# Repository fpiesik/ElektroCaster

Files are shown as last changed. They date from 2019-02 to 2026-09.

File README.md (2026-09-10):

What is the ElektroCaster?

The highest premise of the ElectroCaster is that it's a real guitar which can be used just like that. This project is about to extend the possibilities of expression of a guitar without taking anything away from it. By guitar I don't mean a specific instrument that's hacked somehow, but the idea of a guitar that's to be extended. The ElektroCaster is built from scratch out of aluminum, 3d printed PLA and wood. All the design files are made with open tools such as OpenScad and Kicad. The design is made with the option of parametric changes in mind, like changing the string count, for example.

Here is a list with the most important "guitar-extensions" I've implemented on the hardware side so far are:

    led lit fretboard with 150 individually controllable rbg-leds
    hexaphonic pickip along with a Teensy 4 based 6 channel dsp-unit
    actuator called Kickup that consists of 6 solenoid hitting the strings
    actuator called MultEbow that works like a polyphonic e-Bow (endless sustain)
    fretboard is "touch sensitive" in a way that it recognises which string was pressed at what position
    10 faders, 7 potis, 8 rotary encoder(&switches), 5 buttons, 7 toggle switches, 3 rotary switches (12steps), an analog joystick
    128*64 oled display

## Documentation quick reference

This repository contains three cooperating firmware targets. The tables below summarize the currently documented board roles, serial links, and hardware/protocol references without changing firmware behavior.

### Board roles

| Board firmware | Target noted in docs | Main role | Documentation |
| --- | --- | --- | --- |
| `software/firmwareHid` | Teensy 3.5 | Body controls, encoder/analog/digital input scanning, and local OLED rendering. | `docs/architecture.md`, `docs/protocols.md`, `docs/pinout.md` |
| `software/firmwareCtl` | Teensy 4.1 | Main controller for system state, LED fretboard, fretboard sensing, Kickup, MulEBow control, sequencer/MIDI/SD coordination, and board-to-board routing. | `docs/architecture.md`, `docs/protocols.md`, `docs/realtime.md` |
| `software/firmwareAudio` | Teensy 4.1 | Hexaphonic audio processing, pitch/amplitude analysis, per-string DSP, and actuator audio/control outputs. | `docs/architecture.md`, `docs/protocols.md`, `docs/realtime.md` |

### Serial protocol map

| Link | Baud | Purpose | Details |
| --- | ---: | --- | --- |
| HID <-> CTL | 115200 | Body-control events from HID to CTL and AsciiMassage display commands from CTL to HID. | `docs/protocols.md` |
| CTL <-> Audio | 250000 | Raw byte audio-control commands from CTL to Audio and pitch/amplitude status from Audio to CTL. | `docs/protocols.md` |

### Hardware and timing notes

| Topic | Documentation file | Notes |
| --- | --- | --- |
| Pin assignments | `docs/pinout.md` | Documents firmware-inferred pins only; hardware connector names remain open unless present in source. |
| Realtime intervals | `docs/realtime.md` | Documents LED, fretboard debounce, Kickup, display, clock, HID, and audio intervals. |
| Testing guidance | `docs/testing.md` | Lists safe checks and hardware validation areas. |

### User manual

The German, code-derived operating guide is available at [`docs/bedienungsanleitung.md`](docs/bedienungsanleitung.md). It distinguishes implemented behavior from hardware details that cannot be confirmed from the repository.

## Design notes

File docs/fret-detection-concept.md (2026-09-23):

# Konzept für eine robustere Bunderkennung

## Ausgangslage

Im vollständigen Sensormodus scannt `firmwareCtl` nacheinander alle Bundkontakte
und liest dabei für jede Saite den zugehörigen Eingang. Aus allen aktiven
Kontakten wird derzeit der höchste Bund als `strPrs` gewählt. Erst wenn derselbe
Wert `strBncs` Scans lang anliegt und seit dem letzten ausgegebenen Ereignis
mindestens `fretMaskT` Millisekunden vergangen sind, wird die Änderung
weitergegeben.

Ein normal gegriffener Ton oberhalb des ersten Bundes kann mechanisch zwei
benachbarte Kontakte erzeugen:

- den tatsächlich gegriffenen Bund `F`, und
- den darunterliegenden Bund `F - 1`.

Beim Greifen und Loslassen entstehen diese Kontakte jedoch nicht gleichzeitig.
Die Zwischenzustände `nur F`, `nur F - 1` und `kein Kontakt` können deshalb als
scheinbar gültige Zustände lange genug anliegen, um trotz Debounce und Maske ein
falsches Ereignis auszulösen.

## Bewertung der Zwei-Kontakt-Idee

Zwei **benachbarte** Kontakte sind ein wesentlich stärkeres Plausibilitätssignal
als ein einzelner Kontakt. Die Idee kann daher insbesondere beim Umgreifen
Fehlinterpretationen des tieferen Bundes unterdrücken. Eine globale Regel
„gedrückt nur bei mindestens zwei Kontakten“ ist aber nicht ausreichend:

1. **Bund 1 ist konstruktiv ein Sonderfall.** Dort steht kein tieferer
   Bundkontakt zur Bestätigung zur Verfügung. Ein striktes Zwei-Kontakt-Kriterium
   würde Bund 1 unspielbar machen.
2. **Ein einzelner Kontakt am höheren Bund ist nicht zwingend falsch.** Je nach
   Fingerposition, Saitenlage, Verschmutzung oder Kontaktwiderstand kann der
   zweite Kontakt zeitweise fehlen. Eine harte Regel würde dann gültige Griffe
   übersehen und sich langsamer anfühlen.
3. **Beliebige zwei Kontakte reichen nicht.** Nur das Paar `(F - 1, F)` bestätigt
   `F`. Zwei nicht benachbarte Kontakte können durch mehrere Finger, Nebenschlüsse
   oder Scanartefakte entstehen.
4. **Beim Loslassen hilft das Kriterium allein nicht.** Das bestätigte Paar zerfällt
   zwangsläufig zuerst zu einem Einzelkontakt. Würde dieser sofort als anderer
   Bund behandelt, bleibt das bisherige Fehltracking erhalten; würde er sofort
   als „losgelassen“ behandelt, entstehen vorzeitige Note-Offs.
5. **Die aktuelle Information wird bereits erfasst, aber verworfen.** Der Scanner
   hält die gesamte Matrix in `frtState`; `updateFretDebounce()` reduziert sie
   anschließend auf den höchsten Kontakt und eine Kontaktanzahl. Für ein
   Nachbarschaftskriterium muss deshalb kein Pin oder Scanablauf geändert werden.

**Empfehlung:** Das benachbarte Kontaktpaar als schnelle Bestätigung verwenden,
aber nicht als absolute Voraussetzung. Es sollte Teil eines zustandsbehafteten,
asymmetrischen Filters sein: bestätigte Paare dürfen schneller übernommen
werden; Einzelkontakte werden als Übergang behandelt und erst nach einer kurzen,
gemessenen Frist als Fallback akzeptiert.

## Vorgeschlagene Zustandsmaschine pro Saite

Die Zustandsmaschine arbeitet nach einem vollständigen Matrixscan und getrennt
von MIDI-, Audio-, Kickup- und Sequenceraktionen. Sie liefert weiterhin nur den
bisherigen logischen Wert `0..nFrets`; nachgelagerte Ereignisse und Protokolle
bleiben unverändert.

### Beobachtung aus einem Scan

Für jede Saite werden abgeleitet:

- `highest`: höchster aktiver Kontakt oder `0`,
- `hasPair`: `highest > 1` und die Kontakte `highest` sowie `highest - 1` sind
  aktiv,
- `contactCount`: Zahl aktiver Kontakte,
- optional eine Bitmaske aller Kontakte für Diagnose und Tests.

Die vorhandene Abbildung ist zu beachten: Matrixindex `f` wird aktuell als
Bundnummer `f + 1` ausgegeben. Das Paar für den ausgegebenen Bund `F` liegt somit
an den Matrixindizes `F - 1` und `F - 2`.

### Zustände

| Zustand | Bedeutung |
| --- | --- |
| `RELEASED` | Kein bestätigter Griff. |
| `CANDIDATE(F)` | Ein noch nicht bestätigter Einzelkontakt oder ein instabiler Übergang. |
| `PRESSED(F)` | Stabil bestätigter, nach außen gemeldeter Griff. |
| `RELEASING(F)` | Das bestätigte Paar ist zerfallen; kurze Haltephase gegen falschen Bundwechsel beziehungsweise vorzeitiges Loslassen. |

### Übergänge

1. **Schnelles Greifen oberhalb Bund 1:** In `RELEASED` oder `CANDIDATE`
   bestätigt das benachbarte Paar `(F - 1, F)` den Bund `F` nach einer kleinen
   Anzahl aufeinanderfolgender identischer Scans. Diese Schwelle sollte deutlich
   kleiner als der heutige allgemeine Debounce sein, muss aber am Instrument
   gemessen werden.
2. **Bund 1:** Ein Einzelkontakt an Bund 1 wird über einen eigenen, zeitbasierten
   oder scanbasierten Debounce bestätigt.
3. **Fallback für unvollständige Paare:** Ein stabiler Einzelkontakt oberhalb
   Bund 1 darf nach einer längeren Frist bestätigt werden. Dadurch bleibt das
   System bei schwachem oder fehlendem Zweitkontakt spielbar.
4. **Umgreifen:** Liegt in `PRESSED(oldF)` ein vollständiges neues Paar für
   `newF` vor, kann direkt auf `newF` gewechselt werden. Ein einzelner Kontakt
   neben `oldF` ändert die ausgegebene Note zunächst nicht, sondern startet oder
   erneuert nur `CANDIDATE(newF)`.
5. **Loslassen:** Zerfällt das Paar, bleibt `oldF` zunächst in `RELEASING(oldF)`
   logisch aktiv. Erst eine kurze stabile Nullphase erzeugt Release. Entsteht
   währenddessen ein bestätigtes neues Paar, erfolgt ein direkter Bundwechsel
   ohne zwischenzeitliches Release.
6. **Mehrdeutige Matrix:** Bei mehr als zwei Kontakten wird das höchste
   benachbarte Paar als Kandidat gewählt. Existiert kein benachbartes Paar, gilt
   die Beobachtung als unsicher und wird nur über den langsamen Fallback
   übernommen. Ob Mehrfingergriffe auf derselben Saite für Step-Edit weiterhin
   separat benötigt werden, muss vor der Implementierung geprüft werden.

## Warum Zeit statt ausschließlich Scananzahl erwägen

`readFretboard()` läuft im Hauptloop, dessen Frequenz durch andere Aufgaben
schwanken kann. Eine feste Anzahl gleicher Scans entspricht daher nicht zwingend
einer konstanten Latenz. Für musikalisch wahrnehmbare Übergänge sind Zeitgrenzen
in Mikro- oder Millisekunden leichter zu messen und zu begründen. Alternativ muss
die tatsächliche Scanrate unter Worst-Case-Last bestimmt werden, bevor neue
Scan-Schwellen gewählt werden.

Die bestehenden Werte `strBncs = 500` Samples und `fretMaskT = 50 ms` sollten
nicht blind übernommen oder geändert werden. Die Paarbestätigung, der
Einzelkontakt-Fallback und die Release-Haltezeit benötigen getrennte, anhand von
Messdaten festgelegte Parameter. Insbesondere darf die bestehende 50-ms-Maske
einen schnellen, eindeutig bestätigten Bundwechsel nicht unnötig blockieren.

## Implementierung in kleinen Schritten

1. **Nur instrumentieren:** Pro Scan Zeitstempel, Rohkontaktmaske, aktuell
   ausgegebenen Bund und Ereignisgrund in einen begrenzten Debug-Puffer schreiben.
   Keine seriellen Prints im zeitkritischen Scanpfad; den Puffer später gedrosselt
   ausgeben.
2. **Reale Übergänge aufzeichnen:** Je Saite Bund 1, mehrere mittlere und hohe
   Bünde, langsames und schnelles Greifen, Loslassen, Slides und schnelle
   Bundwechsel erfassen. Dabei besonders die Dauer der Einzelkontaktphasen
   bestimmen.
3. **Filter als reine Logik isolieren:** Die Auswertung einer Kontaktmaske in
   einer kleinen zustandsbehafteten Komponente implementieren. Der bestehende
   Hardware-Scan bleibt unverändert. Hostseitige Tests speisen aufgezeichnete
   Maskenfolgen ein.
4. **Schattenbetrieb:** Alten und neuen Filter parallel berechnen, Aktionen aber
   weiterhin nur aus dem alten Filter auslösen. Abweichungen protokollieren.
5. **Gezielter Hardwareversuch:** Erst nach Auswertung der Logs den neuen Filter
   für Ereignisse aktivieren. MIDI, Audio, Kickup und Step-Edit einzeln prüfen.
6. **Parameter abstimmen:** Fast-Path, Fallback und Releasezeit anhand der
   schlechtesten realen Saite/Bund-Kombination wählen, nicht anhand eines
   synthetischen Idealverlaufs.

## Minimale Testmatrix

Für jede Saite und mindestens Bund 1, 2, einen mittleren sowie den höchsten
erfassten Bund:

- einzelnes Greifen und Loslassen, langsam und schnell,
- Wechsel `F -> F + 1`, `F + 1 -> F` und Sprung über mehrere Bünde,
- Slide mit durchgehendem Saitenkontakt,
- sehr kurzer Tap und wiederholte schnelle Taps,
- absichtlich nur ein Bundkontakt,
- Kontaktfolge `F - 1`, dann Paar; beim Loslassen Paar, dann `F - 1`, dann null,
- Kontaktfolge `F`, dann Paar; beim Loslassen Paar, dann `F`, dann null,
- mehr als zwei gleichzeitige Kontakte sowie nicht benachbarte Kontakte,
- mehrere Saiten gleichzeitig,
- Betrieb mit LED-Update, Sequencer und MIDI, um variable Looplast abzudecken.

Zu messen sind mindestens False Note-On, False Note-Off, falsche Bundnummer,
verlorene Griffe sowie Latenz von erstem Kontakt bis zum Ereignis. Als
Abnahmekriterium sollte die neue Logik bei gleicher Testsequenz weniger
Fehlereignisse erzeugen, ohne die gemessene typische Anschlagslatenz zu erhöhen.

## Auswirkungen und Grenzen

- **Betroffenes Board:** ausschließlich `firmwareCtl` (Teensy 4.1).
- **Pins und elektrischer Scan:** Das Konzept benötigt keine Änderung.
- **Serielle Protokolle:** Keine Änderung; nach außen bleibt der logische
  Griffzustand gleich codiert.
- **Realtime-Audio und Audio-Routing:** Keine Änderung.
- **Kickup:** Keine Timingänderung, aber verbesserte Erkennung verändert
  naturgemäß, welches Griffereignis einen Kick auslöst; deshalb sicher testen.
- **Ungewissheit:** Ob wirklich jeder reale Griff ab Bund 2 zuverlässig das
  benachbarte Paar bildet, ist aus dem Code nicht belegbar. Diese Annahme muss mit
  Rohdaten aller Saiten und relevanten Bünde validiert werden.

## Implementierungsstand

Der zustandsbehaftete Filter ist als hardwareunabhängige Logik in
`software/firmwareCtl/FretDetection.h` umgesetzt. Im vollständigen Sensormodus
wertet `firmwareCtl` nach jedem unveränderten Matrixscan die Kontaktmaske aus und
verwendet den höchsten benachbarten Kontakt als schnelle Bestätigung. Bund 1,
einzelne höhere Kontakte und die Nullphase besitzen getrennte Zeitgrenzen. Der
vereinfachte Sensormodus verwendet weiterhin den bisherigen scanbasierten
Debounce und die 50-ms-Ereignismaske.

Die Startwerte betragen 4 ms für ein Paar, 12 ms für Bund 1, 30 ms für den
Einzelkontakt-Fallback und 12 ms für das Loslassen. Diese Werte sind ausdrücklich
vorläufig. Vor dem Einsatz am Instrument müssen sie mit der oben beschriebenen
Testmatrix und aufgezeichneten Rohkontakten validiert und gegebenenfalls
angepasst werden.

Die reine Filterlogik wird hostseitig durch `tests/fret_detection_test.cpp`
geprüft. Der Test deckt Paarbestätigung, zerfallende Paare, Loslassen, Bund 1,
Einzelkontakt-Fallback, direkte Bundwechsel, mehrdeutige Kontaktmasken und den
Überlauf von `millis()` ab.

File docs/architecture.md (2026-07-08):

# ElektroCaster architecture

This document summarizes the firmware architecture as currently inferable from the repository. It is documentation only and does not define new behavior.

## System overview

ElektroCaster is a hardware/firmware electric guitar platform with:

- a 150-pixel LED fretboard,
- touch-sensitive fretboard detection through string/fret contacts,
- Kickup solenoid string actuators,
- a MulEBow electromagnetic sustain actuator,
- hexaphonic pickup/audio processing,
- many body controls,
- an OLED display.

The firmware is split across three microcontrollers.

## Board role summary

| Firmware | Board role | Owns / directly touches | Communicates with | Protected behavior to preserve |
| --- | --- | --- | --- | --- |
| `software/firmwareHid` | Body-control and display companion | Analog controls, digital controls, encoders, resistor-ladder rotary switches, SH1106 128x64 OLED | `firmwareCtl` over `Serial6` at 115200 baud | HID command byte layout, display packet names/payloads, input pin assignments |
| `software/firmwareCtl` | Main coordinator | LED fretboard, fretboard contact scanning, Kickup pins/timing, MIDI, SD song state, display composition, Audio/HID routing | `firmwareHid` over `Serial7` at 115200 baud; `firmwareAudio` over `Serial1` at 250000 baud; USB/hardware MIDI | Fretboard scan/debounce, Kickup pulse timing, serial payload formats, LED pin/mapping |
| `software/firmwareAudio` | Hexaphonic DSP and actuator-audio board | TDM audio I/O, CS42448 codec control, per-string DSP, analysis objects, coil/MulEBow outputs | `firmwareCtl` over `Serial1` at 250000 baud | AudioConnection graph, audio routing, analysis intervals, audio command scaling |

## Microcontroller roles

### `software/firmwareHid`

Likely target: Teensy 3.5.

Responsibilities:

- Read body controls:
  - 22 analog inputs,
  - 19 digital inputs,
  - 8 encoders,
  - 3 analog resistor-ladder rotary switch values.
- Send changed control values to `firmwareCtl` over a serial link.
- Own the OLED display hardware through U8g2.
- Receive display drawing commands from `firmwareCtl` using AsciiMassage packets and render them locally.

Important files:

- `software/firmwareHid/HardwareConfig.h`: HID input counts and pin arrays.
- `software/firmwareHid/firmwareHid.ino`: encoder instances, input scanning loop, display initialization.
- `software/firmwareHid/send.ino`: HID-to-CTL byte protocol.
- `software/firmwareHid/receive.ino`: CTL-to-HID display command receiver.
- `software/firmwareHid/display.ino`: local U8g2 drawing helpers.

### `software/firmwareCtl`

Likely target: Teensy 4.1.

Responsibilities:

- Main system state.
- LED fretboard control through FastLED/WS2812Serial.
- Fretboard contact scanning and debouncing.
- Kickup cueing and solenoid timing.
- MulEBow control messages sent to the audio board.
- Sequencer, scale, string setup, song, and pattern state.
- SD card song loading/saving.
- USB MIDI and hardware MIDI handling.
- Serial coordination with HID and Audio boards.

Important files:

- `software/firmwareCtl/firmwareCtl.ino`: large global state block, setup, main loop, hardware initialization.
- `software/firmwareCtl/04_hid.ino`: fretboard scan/debounce plus HID processing and musical actions.
- `software/firmwareCtl/ProtocolAudio.h` and `ProtocolHid.h`: shared byte constants for Audio and HID serial protocols.
- `software/firmwareCtl/2audio.ino`: CTL-to-Audio command senders.
- `software/firmwareCtl/13_serialEvents.ino`: serial receivers from Audio and HID.
- `software/firmwareCtl/01_actuators.ino`: Kickup cueing and pulse handling.
- `software/firmwareCtl/02_clock.ino`: internal clock, MIDI clock, sync points, pattern scheduling.
- `software/firmwareCtl/03_display.ino`: display update and drawing command senders.
- `software/firmwareCtl/05_ledfrets.ino`: LED fretboard update logic.
- `software/firmwareCtl/14_song.ino`: binary SD song save/load format.

### `software/firmwareAudio`

Likely target: Teensy 4.1.

Responsibilities:

- Hexaphonic audio input and processing using the Teensy Audio Library.
- TDM audio input and output through `AudioInputTDM`, `AudioOutputTDM`, and `AudioControlCS42448`.
- Per-string input gain, envelope, filter, ring/amplitude modulation, pitch analysis, RMS analysis.
- MulEBow/coil oscillator outputs.
- Receive control commands from `firmwareCtl`.
- Send pitch and amplitude analysis data back to `firmwareCtl`.

Important files:

- `software/firmwareAudio/ProtocolAudio.h`: shared byte constants for the CTL/Audio serial protocol.
- `software/firmwareAudio/firmwareAudio.ino`: global audio objects, state, static output summing connections.
- `software/firmwareAudio/0Setup.ino`: audio hardware setup and per-string `AudioConnection` construction.
- `software/firmwareAudio/yLoop.ino`: serial command parser, analysis loop, MulEBow state handling.
- `software/firmwareAudio/2ctl.ino`: Audio-to-CTL status senders.
- `software/firmwareAudio/envelopes.ino`, `filter.ino`, `fx.ino`, `lfos.ino`: DSP parameter helpers.

## Data flow

```text
Body controls + OLED hardware
        |
        | firmwareHid Serial6 @ 115200 baud
        v
firmwareCtl Serial7 @ 115200 baud
        |
        | firmwareCtl Serial1 @ 250000 baud
        v
firmwareAudio Serial1 @ 250000 baud
```

Additional flows:

- `firmwareCtl` sends display drawing commands to `firmwareHid` using AsciiMassage packets.
- `firmwareHid` sends HID control changes to `firmwareCtl` using compact byte messages.
- `firmwareCtl` sends audio control, string state, envelope, filter, volume, and bow commands to `firmwareAudio` using compact byte messages.
- `firmwareAudio` sends pitch and amplitude estimates back to `firmwareCtl`.
- `firmwareCtl` also handles USB MIDI and hardware MIDI.

## Known technical risks

- Many global variables in `firmwareCtl` and `firmwareAudio` make dependencies implicit.
- Several files mix hardware access, state updates, UI handling, musical logic, and protocol handling.
- Pin assignments and hardware mappings are embedded directly in firmware files.
- Serial protocols use magic byte values and do not appear to have checksums, versioning, or documented recovery behavior.
- Serial packet parsing is non-blocking on the inspected HID and Audio links and uses short packet timeouts, but the byte protocols still lack checksums, sequence numbers, explicit length bytes, or version negotiation.
- `firmwareCtl/04_hid.ino` couples fretboard scanning, debounce, MIDI, Kickup, audio triggering, and sequencer editing.
- `firmwareCtl/02_clock.ino` calls display updates from the internal clock path; timing impacts should be measured before changing it.
- `firmwareAudio/0Setup.ino` builds many audio connections dynamically; audio routing changes are high risk.
- `firmwareCtl/14_song.ino` stores song data as an implicit binary layout without an evident version header.

## Refactor safety guidance

- Documentation-only changes should not touch firmware source files.
- For firmware refactors, start by naming constants and documenting existing behavior before changing control flow.
- Treat pin mappings, serial payloads, audio routing, Fretboard scan timing, Clock timing, and Kickup pulse timing as protected behavior.

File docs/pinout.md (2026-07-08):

# ElektroCaster pinout notes

This document records pin assignments inferable from firmware source. It does not change pin values. Hardware labels and board connector names are open unless explicitly shown in code.

## Board-level pin ownership

| Firmware | Pin / hardware area | Source of truth in firmware | Notes |
| --- | --- | --- | --- |
| `software/firmwareHid` | Body controls, encoders, OLED I2C | `software/firmwareHid/HardwareConfig.h`, `software/firmwareHid/firmwareHid.ino` | OLED constructor uses hardware I2C with `U8X8_PIN_NONE`; exact SDA/SCL board pins are implied by Teensy hardware I2C rather than listed here. |
| `software/firmwareCtl` | LED data, fret contacts, string sense pins, Kickup outputs | `software/firmwareCtl/HardwareConfig.h`, `software/firmwareCtl/firmwareCtl.ino` | LED matrix order is encoded in `led_pixPos`; fret and string scan semantics are timing-sensitive. |
| `software/firmwareAudio` | TDM audio channels and codec/audio objects | `software/firmwareAudio/firmwareAudio.ino`, `software/firmwareAudio/0Setup.ino` | Physical codec connector labels are not documented in source. |

## `software/firmwareHid`

### Encoders

| Encoder | Pins |
| --- | --- |
| `enc0` | `16`, `15` |
| `enc1` | `3`, `2` |
| `enc2` | `6`, `5` |
| `enc3` | `9`, `8` |
| `enc4` | `12`, `11` |
| `enc5` | `26`, `24` |
| `enc6` | `29`, `28` |
| `enc7` | `45`, `44` |

Note: `nEnc` is declared as `8`; eight encoders are instantiated and sent.

### Analog inputs

`aPin[22]`:

| Index | Pin | Notes |
| ---: | --- | --- |
| 0 | `31` | Analog control; exact hardware function open. |
| 1 | `32` | Analog control; exact hardware function open. |
| 2 | `33` | Analog control; exact hardware function open. |
| 3 | `34` | Analog control; exact hardware function open. |
| 4 | `35` | Analog control; exact hardware function open. |
| 5 | `36` | Analog control; exact hardware function open. |
| 6 | `37` | Analog control; exact hardware function open. |
| 7 | `38` | Analog control; exact hardware function open. |
| 8 | `39` | Analog control; exact hardware function open. |
| 9 | `A21` | Analog control; exact hardware function open. |
| 10 | `A22` | Analog control; exact hardware function open. |
| 11 | `14` | Analog control; exact hardware function open. |
| 12 | `A26` | Analog control; exact hardware function open. |
| 13 | `A25` | Analog control; exact hardware function open. |
| 14 | `A11` | Analog control; exact hardware function open. |
| 15 | `A10` | Analog control; exact hardware function open. |
| 16 | `A24` | Analog control; exact hardware function open. |
| 17 | `A23` | Analog control; exact hardware function open. |
| 18 | `A9` | Analog control; exact hardware function open. |
| 19 | `A8` | Rotary switch resistor ladder input. |
| 20 | `A7` | Rotary switch resistor ladder input. |
| 21 | `A6` | Rotary switch resistor ladder input. |

### Digital inputs

`dPin[19]`:

| Index | Pin | Notes |
| ---: | --- | --- |
| 0 | `17` | Digital control; exact hardware function open. |
| 1 | `13` | Digital control; exact hardware function open. |
| 2 | `51` | Digital control; exact hardware function open. |
| 3 | `52` | Digital control; exact hardware function open. |
| 4 | `53` | Digital control; exact hardware function open. |
| 5 | `42` | Digital control; exact hardware function open. |
| 6 | `41` | Digital control; exact hardware function open. |
| 7 | `40` | Digital control; exact hardware function open. |
| 8 | `56` | Digital control; exact hardware function open. |
| 9 | `57` | Digital control; exact hardware function open. |
| 10 | `43` | Digital control; exact hardware function open. |
| 11 | `54` | Digital control; exact hardware function open. |
| 12 | `55` | Digital control; exact hardware function open. |
| 13 | `4` | Digital control; exact hardware function open. |
| 14 | `7` | Digital control; exact hardware function open. |
| 15 | `10` | Digital control; exact hardware function open. |
| 16 | `25` | Digital control; exact hardware function open. |
| 17 | `27` | Digital control; exact hardware function open. |
| 18 | `30` | Digital control; exact hardware function open. |

## `software/firmwareCtl`

### Serial ports

| Port | Baud | Inferred use |
| --- | ---: | --- |
| `Serial` | 115200 | Debug USB serial. |
| `Serial1` | 250000 | Audio board link. |
| `Serial7` | 115200 | HID board link. |
| `Serial8` | MIDI library instance | Hardware MIDI. |

### LED fretboard

| Symbol | Value | Notes |
| --- | --- | --- |
| `LED_PIN` | `14` | WS2812Serial/FastLED data pin. |
| `NUMPIXELS` | `150` | Total LED count. |
| `nLedFrets` | `25` | LED fret positions per string. |

The physical LED matrix mapping is encoded in `led_pixPos[6][25]`. Exact physical orientation should be verified against hardware.

### Fretboard contact sensing

| Symbol | Values | Notes |
| --- | --- | --- |
| `nFrets` | `21` | Fret contact count used for scanning. |
| `frtPins` | `{13,33,2,3,4,5,6,7,8,9,10,11,12,24,25,26,27,30,31,32,17,16}` | Contains 22 entries while `nFrets` is 21; open issue to verify. |
| `strPins` | `{18,19,20,21,22,23}` | Six string sense inputs. |

Open: `strSnsPins` is also declared as `{2,3,4,5,6,7}` in the string definitions section, but the fretboard scanner uses `strPins`.

### Kickup

| String index | Pin |
| ---: | ---: |
| 0 | `41` |
| 1 | `40` |
| 2 | `39` |
| 3 | `38` |
| 4 | `37` |
| 5 | `36` |

## `software/firmwareAudio`

### Serial ports

| Port | Baud | Inferred use |
| --- | ---: | --- |
| `Serial` | 115200 | Debug USB serial. |
| `Serial1` | 250000 | CTL board link. |

### TDM audio channel mappings

| Array | Values | Notes |
| --- | --- | --- |
| `strAIn[6]` | `{10,8,6,4,2,0}` | Audio input channels of the strings. |
| `strAOut[6]` | `{10,8,6,4,2,0}` | Output channels of the string coils. |

Open: Physical codec channel labels and connector wiring are not documented in source.

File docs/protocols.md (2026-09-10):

# ElektroCaster serial protocols

This document records currently observed serial protocols. It is based on repository source code only. Where semantics are unclear, they are marked as open.

## Serial links and baud rates

| Link | Sender-side port | Receiver-side port | Baud | Notes |
| --- | --- | --- | --- | --- |
| HID -> CTL | `firmwareHid` `Serial6` | `firmwareCtl` `Serial7` | 115200 | HID controls to main controller. |
| CTL -> HID display | `firmwareCtl` `Serial7` | `firmwareHid` `Serial6` | 115200 | AsciiMassage display drawing commands. Same physical link is likely bidirectional. |
| CTL -> Audio | `firmwareCtl` `Serial1` | `firmwareAudio` `Serial1` | 250000 | Raw byte command protocol. |
| Audio -> CTL | `firmwareAudio` `Serial1` | `firmwareCtl` `Serial1` | 250000 | Raw byte status protocol. Same physical link is likely bidirectional. |

Open question: physical wiring and electrical directionality are not documented in the repository.

## Protocol byte-space summary

| Direction | Transport | Framing style | Command / packet namespace | Payload style | Receiver notes |
| --- | --- | --- | --- | --- | --- |
| HID -> CTL | Raw bytes on HID/CTL serial link | Command/index byte followed by value byte; HID also sends `255` after `sendAllNew()` | Command bytes are offset from HID indexes using `+ 201`; CTL subtracts `201` before dispatch | One value byte per recognized input event | CTL uses non-blocking packet assembly with a short timeout; no checksum or versioning identified. |
| CTL -> HID display | AsciiMassage on HID/CTL serial link | Named AsciiMassage packets | Text packet names such as `str`, `int`, `frm`, `buf` | Packet-specific byte/int/long/string fields | HID delegates parsing/framing to AsciiMassage and executes U8g2 drawing calls. |
| CTL -> Audio | Raw bytes on CTL/Audio serial link | Command byte `200..255`, then command-specific payload | Shared audio command constants; Audio decodes `command - 200` | One or more bytes; most scaled values are intended to stay `<= 199` | Audio uses non-blocking packet assembly with a short timeout; no checksum or length byte identified. |
| Audio -> CTL | Raw bytes on CTL/Audio serial link | Status command byte, then status-specific payload | Audio status constants reuse some numeric IDs from the opposite direction | Pitch/amplitude/status bytes | CTL decodes by direction, so numeric reuse is only safe because links are directional at parser level. |

## HID -> CTL protocol

Implemented in:

- `software/firmwareHid/ProtocolHid.h`
- `software/firmwareHid/send.ino`
- `software/firmwareCtl/ProtocolHid.h`
- `software/firmwareCtl/13_serialEvents.ino`

General form: a command/index byte followed by one value byte. HID also emits `255` as a frame/end marker; CTL resets the current HID packet state when it receives this marker.

Constants inferred from code:

- `nDigital = 19`
- `nAnalog = 22`
- Rotary switch analog source indices are `19..21`, sent separately as rotary states instead of normal analog values.

| HID data type | Sender command byte | CTL decoded range | Payload | Value range / scaling |
| --- | --- | --- | --- | --- |
| Digital input | `idx + 201` | `incoming < 19` | 1 byte `val` | Raw digital state. |
| Analog input | `idx + nDigital + 201` | `incoming >= 19 && incoming < 38` | 1 byte `val` | `analogRead` mapped from `0..1023` to `0..200`; indices `19..21` are excluded. |
| Rotary switch | `idx + nDigital + 19 + 201` | `incoming >= 38 && incoming < 41` | 1 byte `val` | Rotary state index, likely `0..11`. |
| Encoder delta | `idx + nDigital + 22 + 201` | `incoming >= 41 && incoming < 49` | 1 byte `val` | Delta encoded as `delta + 100`; CTL subtracts `100`. |
| Frame/end marker | `255` | Packet-state reset marker | none | Sent by HID after `sendAllNew()`; CTL resets any pending HID packet state. |

Open/incomplete:

- `nEnc` is declared as `8`; eight encoder instances are instantiated and the protocol range supports encoder indices `0..7` through decoded values `41..48`.
- CTL uses a 20 ms timeout while assembling HID command/value pairs.
- No checksum or sequence number was identified.

## CTL -> HID display protocol

Implemented in:

- `software/firmwareCtl/03_display.ino`
- `software/firmwareHid/receive.ino`

Transport: AsciiMassage packets over the CTL/HID serial link.

Known packet names and payloads:

| Packet | Payload | Meaning |
| --- | --- | --- |
| `str` | `byte x`, `byte y`, `string text` | Draw string. |
| `int` | `byte x`, `byte y`, `int val` | Draw integer. |
| `lng` | `byte x`, `byte y`, `long val` | Draw long integer. |
| `frm` | `byte xp`, `byte yp`, `byte xs`, `byte ys` | Draw frame. |
| `box` | `byte xp`, `byte yp`, `byte xs`, `byte ys` | Draw box. |
| `rfr` | `byte xp`, `byte yp`, `byte xs`, `byte ys`, `byte r` | Draw rounded frame. |
| `rbx` | `byte xp`, `byte yp`, `byte xs`, `byte ys`, `byte r` | Draw rounded box. |
| `cir` | `byte x`, `byte y`, `byte r` | Draw circle. |
| `dis` | `byte x`, `byte y`, `byte r` | Draw filled disc. |
| `pix` | `byte x`, `byte y` | Draw pixel. |
| `col` | `byte c` | Set draw color. |
| `lin` | `byte x0`, `byte y0`, `byte x1`, `byte y1` | Draw line. |
| `clr` | none | Clear buffer. |
| `buf` | none | Send buffer to display. |
| `tuner` | open | Handler is present but commented out. |

Open/incomplete:

- Coordinate and color ranges are not formally documented; likely U8g2 display coordinates for a 128x64 OLED.
- Error handling for malformed packets is delegated to AsciiMassage behavior.

## CTL -> Audio protocol

Implemented in:

- `software/firmwareCtl/ProtocolAudio.h`
- `software/firmwareCtl/2audio.ino`
- `software/firmwareAudio/ProtocolAudio.h`
- `software/firmwareAudio/yLoop.ino`

General form: first byte is a command ID in the range `200..255`. Audio computes `incoming = command - 200`. Payload length depends on command.

Known command IDs:

| Command byte | Audio `incoming` | Sender function | Payload | Observed receiver behavior / scaling |
| --- | ---: | --- | --- | --- |
| `200` | `0` | `sndTrigEnv(str, vel)` | `byte str`, `byte velocity` | Audio calls `trigEnv(str, velocity / 199.0)`. |
| `201` | `1` | `sndStrPrs(str, pitch, state)` | `byte str`, `byte pitch`, `byte state` | Audio calls `strFret(str, pitch, state)` and stores `strState[str] = state`. |
| `202` | `2` | not found in CTL sender file | one byte | Audio calls `chOpMode(data)` when byte `<=199`. Source uncertain. |
| `203` | `3` | not found in CTL sender file | one byte | Audio calls `chDispMode(data)` when byte `<=199`. Source uncertain. |
| `204` | `4` | not found in CTL sender file | one byte | Audio calls `chKickMode(data)` when byte `<=199`. Source uncertain. |
| `205` | `5` | `sndBowMode(mode)` | `byte mode` | Audio calls `chBowMode(mode)` when byte `<=199`. Note: Audio-to-CTL CC also uses byte `205` in another direction. |
| `206` | `6` | `sndBowOn(mode)` | `byte mode` | Audio sets `bowOn = mode` when byte `<=199`. Note: Audio-to-CTL pitch also uses byte `206` in reverse direction. |
| `207` | `7` | `sndEnv1(para, val)` | `byte para`, `byte scaledVal` | Audio scales `scaledVal / 199.0` with `sclEnvA[para]`, calls `chEnvA`. |
| `208` | `8` | `sndEnv2(para, val)` | `byte para`, `byte scaledVal` | Audio scales `scaledVal / 199.0` with `sclEnvF[para]`, calls `chEnvF`. |
| `209` | `9` | `sndFilter(para, val)` | `byte para`, `byte scaledVal` | Audio scales with `sclFilter[para]`, calls `chFilter`. |
| `210` | `10` | `sndManualEnv(str, state)` | `byte str`, `byte state` | Audio stores per-string manual envelope-decay override; while enabled, amplitude and filter decay keep sustain high regardless of decay fader value. |
| `211` | `11` | `sndVol(val)` | `byte scaledVal` | Audio computes `(scaledVal / 199.0)^2 * 2`, then `ampOut.gain(val + 0.0001)`. |
| `212` | `12` | `sndStrGain(str, val)` | `byte str`, `byte scaledVal` | Audio computes `scaledVal / 100.0`, calls `chngStrOutGain`. CTL sends `val * 2`. |
| `215` | `15` | not found in CTL sender file | `byte para`, `byte scaledVal` | Audio scales with `sclFX[para]`, calls `chFX`. Source uncertain. |
| `216` | `16` | `sndLfo1(para, val)` | `byte para`, `byte scaledVal` | Audio scales with `sclLfo1[para]`, applies `chLfo1` to all strings. |
| `217` | `17` | not found in CTL sender file | one byte | Audio stores BPM byte. Source uncertain. |
| `218` | `18` | not found in CTL sender file | `byte a`, `byte b` | Audio sends MIDI CC `3, b/2` only if `a == 2`. Source uncertain. |

Open/incomplete:

- Commands `202`, `203`, `204`, `215`, `217`, and `218` are handled by Audio but corresponding CTL sender functions were not identified in `2audio.ino`.
- Audio uses a 10 ms timeout while assembling CTL-to-Audio packets.
- No checksum, version, length byte, escaping, or full resynchronization strategy was identified beyond treating bytes `>= 200` as command/status bytes.
- Values above `199` are treated as command bytes, so payload values should remain `<=199` unless explicitly safe.

## Audio -> CTL protocol

Implemented in:

- `software/firmwareAudio/ProtocolAudio.h`
- `software/firmwareAudio/2ctl.ino`
- `software/firmwareCtl/ProtocolAudio.h`
- `software/firmwareCtl/13_serialEvents.ino`

General form: first byte is a command ID, CTL computes `incoming = command - 200`.

Known command IDs:

| Command byte | CTL `incoming` | Sender function | Payload | CTL receiver behavior |
| --- | ---: | --- | --- | --- |
| `201` | `1` | `sndNote(pitch, vel)` | `byte pitch`, `byte vel` | Audio sender exists, but CTL currently assigns no payload length for this status, so these packets are ignored by the non-blocking parser. |
| `205` | `5` | `sndCC()` | `byte cc`, `byte val` | Audio sender exists, but CTL currently assigns no payload length for this status, so these packets are ignored by the non-blocking parser. |
| `206` | `6` | `sndStrP()` | `byte string`, `byte integerPart`, `byte fractionalPart` | CTL stores `strP[string] = integerPart + fractionalPart / 100.0`. |
| `207` | `7` | `sndStrA()` | `byte string`, `byte amplitudePercent` | CTL stores `strA[string] = amplitudePercent / 100.0`. |

Open/incomplete:

- Audio sender functions for note/CC exist, but CTL currently ignores those status IDs because only pitch and amplitude are assigned receive payload lengths.
- CTL uses a 10 ms timeout while assembling Audio-to-CTL status packets.
- Same numeric command IDs are reused in opposite directions, which is acceptable on a bidirectional link only if direction is always clear.

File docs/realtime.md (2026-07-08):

# ElektroCaster realtime and timing notes

This document records timing values inferable from firmware source. It does not change timing behavior.

## Timing summary

| Firmware | Area | Interval / value | Why it matters |
| --- | --- | --- | --- |
| `software/firmwareCtl` | LED fretboard refresh | `fled_frameInt = 50 ms` | Visible LED update cadence. |
| `software/firmwareCtl` | Fretboard press masking/debounce | `fretMaskT = 50 ms`, `strBncs = 500 samples`, `strBncsP = 5000 samples` | Touch detection behavior; hardware-sensitive. |
| `software/firmwareCtl` | Kickup actuation | `kickDur[6] = 5 ms`, `kCueInt = 3 ms` | Solenoid pulse width and stagger interval. |
| `software/firmwareCtl` | Display refresh | `disp_frameInt = 200 ms` | OLED command generation cadence from CTL. |
| `software/firmwareCtl` | Internal clock basis | 24 PPQN; default `bpm = 90` | Sequencer/MIDI-clock-style timing. |
| `software/firmwareHid` | Serial byte spacing / analog averaging | `waitS = 50 us`, `analogReadAveraging(200)` | HID serial pacing and analog stability. |
| `software/firmwareAudio` | Control / analysis loop | `ctlInt = 10 ms`, `nFrqInt = 20 ms`, `peakInt = 20 ms` | DSP status and CTL feedback cadence. |

## `software/firmwareCtl`

### LED fretboard

| Symbol | Value | Meaning |
| --- | ---: | --- |
| `fled_frameInt` | `50` ms | LED fretboard frame/update interval. |

### Fretboard scanning and debounce

| Symbol | Value | Meaning |
| --- | ---: | --- |
| `fretMaskT` | `50` ms | Minimum time before another string press on the same string is detected. |
| `strBncs` | `500` samples | Same-sample count threshold for normal string press detection. |
| `strBncsP` | `5000` samples | Same-sample count threshold intended for pattern section detection; related code appears commented/disabled. |

Notes:

- `readFretboard()` is called from the main loop.
- The scanner switches fret pins between output/input modes depending on sensing mode.
- Fretboard scan behavior is protected and should not be changed without explicit request and hardware tests.

### Kickup timing

| Symbol | Value | Meaning |
| --- | ---: | --- |
| `kickDur[6]` | `{5,5,5,5,5,5}` ms | Pulse duration per string. |
| `kCueInt` | `3` ms | Interval used to stagger queued kicks. |

Notes:

- `cueKicks()` calls `kickOff()` and then triggers at most one queued string per cue interval.
- This likely prevents simultaneous solenoid current spikes.

### Display update

| Symbol | Value | Meaning |
| --- | ---: | --- |
| `disp_frameInt` | `200` ms | Display update interval. |

Note: `updDisplay()` is currently called from `updIntClock()`, so display refresh is coupled to internal clock processing when `extClk == 0`.

### Clock timing

| Item | Value / formula | Meaning |
| --- | --- | --- |
| Internal PPQN basis | `24` | `bpm2Micros()` divides by 24. |
| `bpm2Micros(val)` | `60000000 / val / 24` | Microseconds per MIDI-clock-style tick. |
| `bpm2Millis(val)` | `60000 / val / 24` | Milliseconds equivalent; comment says microseconds but function name says millis. |
| Default `bpm` | `90` | Main controller default BPM. |

Clock-derived state:

- `pulse = mClock / 24`
- `bar = mClock / 96`
- `syncPnt = mClock / syncInt`

Open: `syncInt` initialization should be verified before any clock refactor.

## `software/firmwareHid`

| Symbol / call | Value | Meaning |
| --- | ---: | --- |
| `waitS` | `50` microseconds | Delay inserted between HID protocol bytes. |
| `analogReadAveraging(200)` | `200` samples | Analog input averaging setting. |
| startup display delay | `2000` ms | Delay after `u8g2.begin()`. |

## `software/firmwareAudio`

| Symbol | Value | Meaning |
| --- | ---: | --- |
| `ctlInt` | `10` ms | Control loop interval placeholder/check interval. |
| `nFrqInt` | `20` ms | Pitch analysis/send interval. |
| `peakInt` | `20` ms | RMS/amplitude analysis/send interval. |
| `waitS` | `100` microseconds | Delay used between bytes in some Audio-to-CTL senders. |
| `AudioMemory` | `2000` blocks | Teensy Audio memory allocation. |
| setup delay | `1000` ms | Delay before audio initialization. |

Notes:

- Pitch analysis resumes/checks all six `AudioAnalyzeMonoFrequency` instances every `nFrqInt` interval.
- RMS analysis checks all six `AudioAnalyzeRMS` instances every `peakInt` interval.
- Debug processor/memory usage printing exists but is disabled behind `if(0)`.

## Protected timing areas

Do not change these without explicit user instruction and hardware validation:

- LED frame interval and LED update path.
- Fretboard pin scanning mode, debounce counters, and mask time.
- Kickup pulse duration and queue interval.
- Internal clock tick calculation and pattern sync behavior.
- Audio analysis intervals and Audio Library routing.
- Serial byte spacing unless the protocol is intentionally redesigned.

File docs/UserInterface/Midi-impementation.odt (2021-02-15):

CC# | Function | | Original Midi
0 | | | Bank Select (MSB)
1 | | | Modulation Wheel (MSB)
2 | | | Breath Controller (MSB)
3
4 | | | Foot Controller (MSB)
5 | | | Portamento Time (MSB)
6 | | | Data Entry (MSB)
7 | | | Channel Volume (MSB)
8 | | | Balance (MSB)
9
10 | | | Pan (MSB)
11 | | | Expression (MSB)
12 | | | Effect Control 1 (MSB)
13 | | | Effect Control 2 (MSB)
14
15
16 | | | General Purpose Controller 1 (MSB)
17 | | | General Purpose Controller 2 (MSB)
18 | | | General Purpose Controller 3 (MSB)
19 | | | General Purpose Controller 4 (MSB)
20 | Arp | String 1 repeats
21 | Arp | String 2 repeats
22 | Arp | String 3 repeats
23 | Arp | String 4 repeats
24 | Arp | String 5 repeats
25 | Arp | String 6 repeats
26 | Arp | All String repeats
27
28 | ArpMode | Val
29 | Arp Clock Mode | Val
30 | Time devision | String 1
31 | | String 2
32 | | String 3 | Bank Select (LSB)
33 | | String 4 | Modulation Wheel (LSB)
34 | | String 5 | Breath Controller (LSB)
35 | | String 6
36 | | All Strings | Foot Controller (LSB)
37 | | | Portamento Time (LSB)
38 | | | Data Entry (LSB)
39 | | | Channel Volume (LSB)
40 | Operation Mode | | Balance (LSB)
41
42 | | | Pan (LSB)
43 | | | Expression (LSB)
44 | | | Effect Control 1 (LSB)
45 | | | Effect Control 2 (LSB)
46
47
48 | | | General Purpose Controller 1 (LSB)
49 | | | General Purpose Controller 2 (LSB)
50 | Light Hold | On Off | General Purpose Controller 3 (LSB)
51 | Light Hold | reset | General Purpose Controller 4 (LSB)
52
53 | Filter | frequency
54 | Filter | resonance
55 | Filter
56 | Filter | octave control
57
58
59
60 | Notes or Tones
61
62
63
64 | | | Sustain Pedal
65 | | | Portamento On/Off
66 | | | Sostenuto
67 | | | Soft Pedal
68 | | | Legato Footswitch
69 | | | Hold 2
70 | | | Sound Controller 1 (default: Sound Variation)
71 | | | Sound Controller 2 (default: Timbre / Harmonic Quality)
72 | | | Sound Controller 3 (default: Release Time)
73 | | | Sound Controller 4 (default: Attack Time)
74 | | | Sound Controller 5 (default: Brightness)
75 | | | Sound Controller 6 (GM2 default: Decay Time)
76 | | | Sound Controller 7 (GM2 default: Vibrato Rate)
77 | | | Sound Controller 8 (GM2 default: Vibrato Depth)
78 | | | Sound Controller 9 (GM2 default: Vibrato Delay)
79 | | | Sound Controller 10 (GM2 default: Undefined)
80 | | | General Purpose Controller 5
81 | | | General Purpose Controller 6
82 | | | General Purpose Controller 7
83 | | | General Purpose Controller 8
84 | | | Portamento Control
85
86
87
88
89
90
91 | | | Effects 1 Depth (default: Reverb Send)
92 | | | Effects 2 Depth (default: Tremolo Depth)
93 | | | Effects 3 Depth (default: Chorus Send)
94 | | | Effects 4 Depth (default: Celeste [Detune] Depth)
95 | | | Effects 5 Depth (default: Phaser Depth)
96 | | | Data Increment
97 | | | Data Decrement
98 | | | Non-Registered Parameter Number (LSB)
99 | | | Non-Registered Parameter Number(MSB)
100 | | | Registered Parameter Number (LSB)
101 | | | Registered Parameter Number(MSB)
102 | Amp Envelope | delay
103 | Amp Envelope | attack
104 | Amp Envelope | hold
105 | Amp Envelope | decay
106 | Amp Envelope | sustain
107 | Amp Envelope | release
108 | Amp Envelope | bias
109 | Filter Envelope | delay
110 | Filter Envelope | attack
111 | Filter Envelope | hold
112 | Filter Envelope | decay
113 | Filter Envelope | sustain
114 | Filter Envelope | release
115 | Filter Envelope | bias
116
117
118
119
120 | | | All Sound Off
121 | | | Reset All Controllers
122 | | | Local Control On/Off
123 | | | All Notes Off
124 | | | Omni Mode Off
125 | | | Omni Mode On
126 | | | Poly Mode Off
127 | | | Poly Mode On

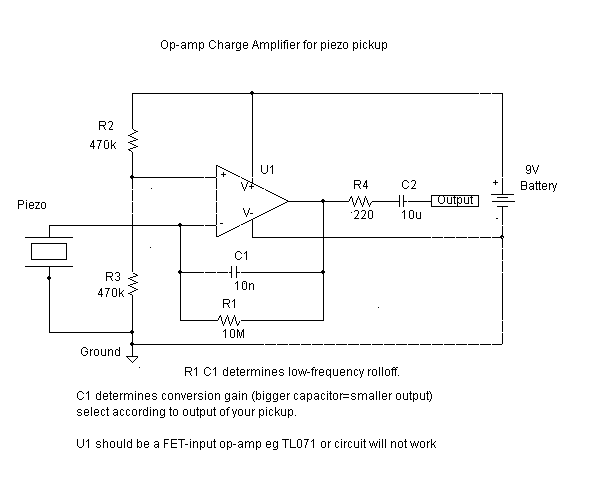
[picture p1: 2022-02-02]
electronics/hexPreamp(opAmp)/chargeamp.gif

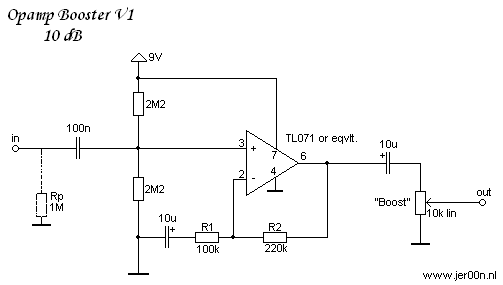
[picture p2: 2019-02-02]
electronics/hexPreamp(opAmp)/schematic.png

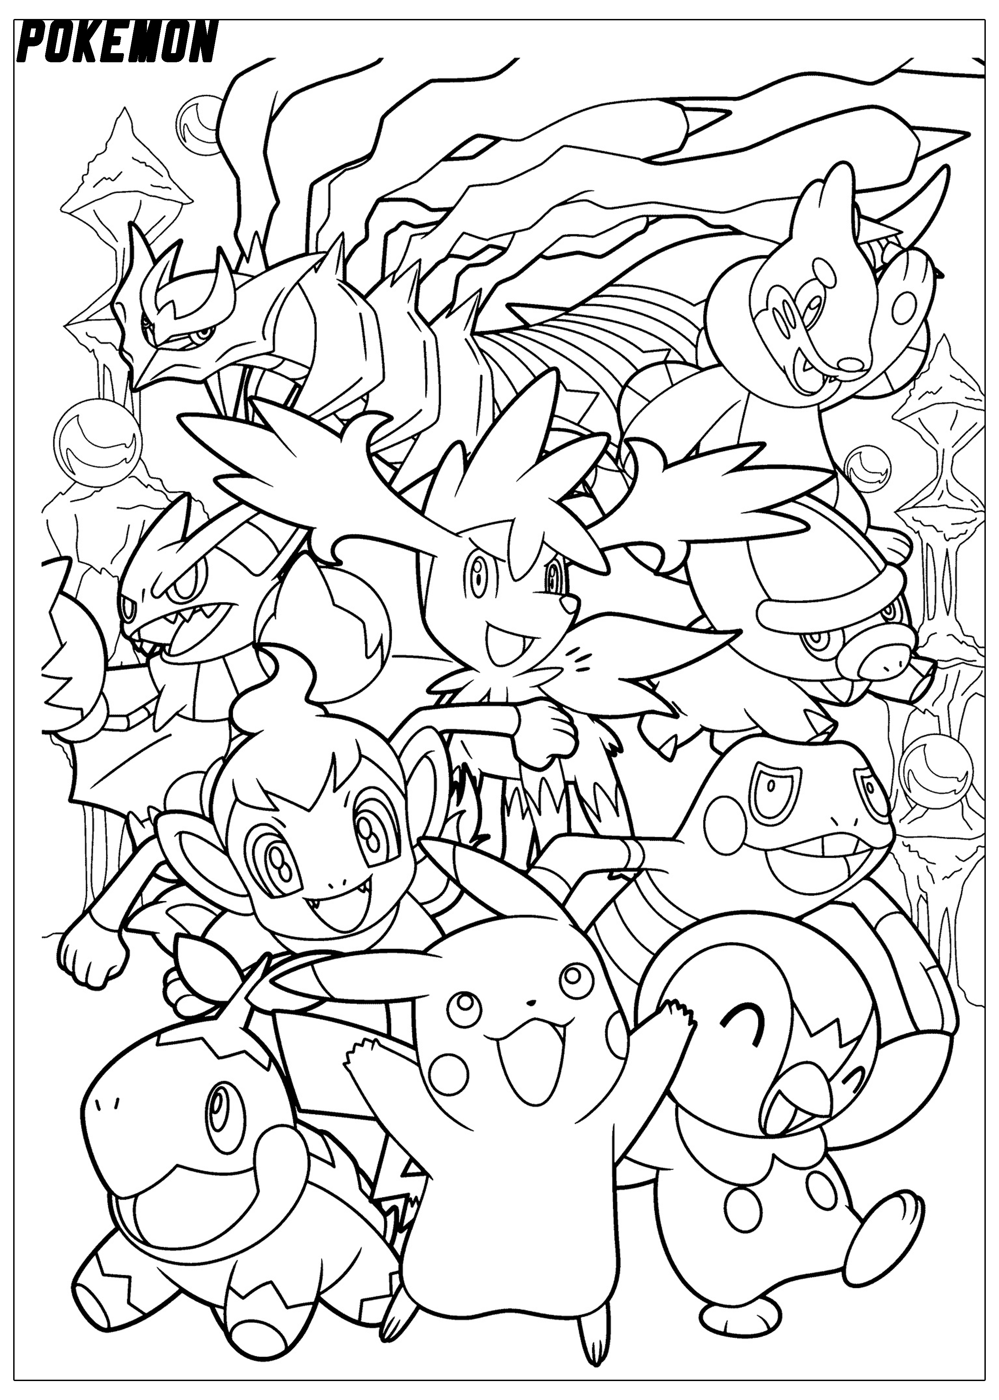
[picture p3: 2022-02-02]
docs/ext_ressources/circuits/piezoPreamps/Pokemon Ausmalbilder Kostenlos Malvorlagen Windowcolor zum Drucken-Dateien/pokemon4.jpg

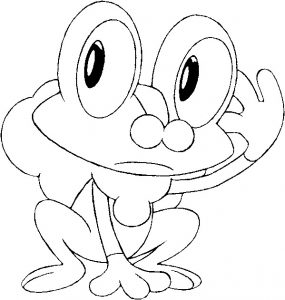
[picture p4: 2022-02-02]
docs/ext_ressources/circuits/piezoPreamps/Pokemon Ausmalbilder Kostenlos Malvorlagen Windowcolor zum Drucken-Dateien/Pokemon-Ausmalbilder-Froxy-285x300.jpg

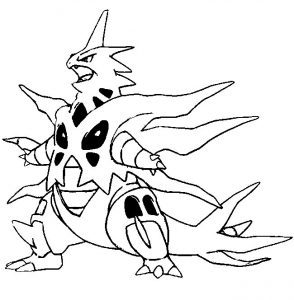
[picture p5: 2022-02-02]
docs/ext_ressources/circuits/piezoPreamps/Pokemon Ausmalbilder Kostenlos Malvorlagen Windowcolor zum Drucken-Dateien/Pokemon-Ausmalbilder-Despotar-294x300.jpg

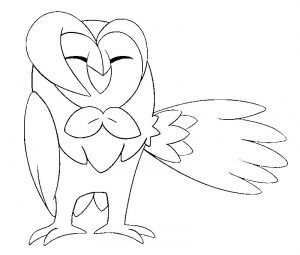
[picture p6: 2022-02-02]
docs/ext_ressources/circuits/piezoPreamps/Pokemon Ausmalbilder Kostenlos Malvorlagen Windowcolor zum Drucken-Dateien/Ausmalbilder-Pokemon-Arboretoss-300x255.jpg

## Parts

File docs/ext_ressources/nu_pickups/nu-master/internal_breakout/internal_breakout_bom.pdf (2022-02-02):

iNTERNAL BREAKOUT
Item | Description | Part Number | Packaging | Qty. | Location
1 | 1uF | C1608X7R1V105M080AE (https://www.mouser.ph/ProductDetail/TDK/C1608X7R1V105M080AE) | C0603 | 3 | C1, C3
2 | 10nF | ZRB18AR61E106ME01L (https://www.mouser.ph/ProductDetail/Murata-Electronics/ZRB18AR61E106ME01L) | C0402 | 1 | C4
3 | 2.2uF | GCM155L81H102KA37D (https://www.mouser.ph/ProductDetail/Murata-Electronics/GCM155L81H102KA37D) | C0603 | 1 | C6
4 | 1nF | C0402C103K5RAC (https://www.mouser.ph/ProductDetail/80-C0402C103K5RAC) | C0402 | 1 | C5
5 | 10uF | C1608JB1V225K080AC (https://www.mouser.ph/ProductDetail/TDK/C1608JB1V225K080AC) | C0603 | 1 | C2
6 | 2x5 Male Header TH | | 2mm TH | 4 | SV5, SV6, SV7, SV8
7 | 1X3 Male Header TH | | 2.54mm TH | 9 | SV1, SV2, SV4, SV9, SV11, SV12, SV13, SV3, SV10
8 | P MOSFET | DMP3099L-7 (https://www.mouser.ph/ProductDetail/Diodes-Incorporated/DMP3099L-7) | SOT 23 | 1 | Q1
9 | 10V LDO Regulator | LP2985-10DBVR (https://www.mouser.ph/ProductDetail/Texas-Instruments/LP2985-10DBVR) | SOT23-5 | 1 | U1

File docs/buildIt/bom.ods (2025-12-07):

Part type | part model/specs | quantity | price (one) | price (sum) | partnumber | link
Body&Neck
aluminum profile | V-slot 2020 50cm | 4 | 3,75
plywood sheet | 40cm*40cm | 2 | 5
locking tuner | Left | 6 | 6 |  |  | https://www.thomann.de/de/harley_benton_parts_locking_tuners_6l_chrome.htm
screw | m5, 50mm | 20 | 0,1
nut | m5 | 20 | 0,1
Fretboard
Rgb-led | ws2812b Led-Stripe 144
frets | nickel silver 7 cm x 3,25 mm x 2,99 mm | 1 | 12,9 |  | Wagner 9770 Nickel Silver Frets
Elektronics
microcontroller board | Arduino Due | 1 | 35
microcontroller board | Teensy 3.6 | 1
microcontroller board | Teensy 3.5 | 1 |  |  | 1568-1443-ND | http://d.digikey.com/r20a1K0gcXtNMpS9M00f070
3d-printing filament | pla | 1
3d-printing filament | Wood-pla | 1
guitar Pickup | hexaphonic | 1
Teensy TDM-Audio-Board |  | 1
pcb blanked | 150mm*1500mm | 2
slide potentiometer | 10k OHM, 20mm | 10 |  |  | PTA2043-2015DPB103 | http://d.digikey.com/Ec70S0MUXCM1p0fK0f02N09
potentiometer | 10k OHM | 7 |  |  | 987-1649-ND | http://d.digikey.com/TapSf0M0901cMXS00N2f7K0
Joystick | 10k OHM | 1 |  |  | 1528-1730-ND | http://d.digikey.com/SX1K070MN020pSMc900ff2K
mosfet | N-ch. 20V 6A Sot23-3 | 6 |  |  | DMN2050LDICT-ND | http://d.digikey.com/F9MXN00wOcS0M0ff010K7p2
rotary encoder | MECHANICAL 20PPR | 8 |  |  | 987-1188-ND | http://d.digikey.com/G9X0Kg00Mn24S07N00c1Mpf
rotary switch | 12 positions | 3 |  |  | GH7279-ND | http://d.digikey.com/y9fSMfMp070NKXXc2f10000

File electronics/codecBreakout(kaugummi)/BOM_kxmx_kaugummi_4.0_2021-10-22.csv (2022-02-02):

ID | Name | Designator | Footprint | Quantity | Manufacturer Part | Manufacturer | Supplier | Supplier Part | Price
1 | 100pF | C4,C10,C17,C22 | 0603 | 4
2 | 100nF | C2,C1,C5,C3,C9,C16,C21,C18,C11 | 0603 | 9
3 | 10uF | C6,C20,C8,C15 | 0603 | 4
4 | CAT811TTBI-GT3 | U1 | SOT-143 | 1
5 | 2K | R2,R1 | 0603 | 2
6 | Header-2.54_1x16 | P2,P1 | HDR-16X1/2.54 | 2
7 | 220Ω | L1 | 0805 | 1
8 | CS42448 | U2 | LQFP64-10X10 | 1
9 | Header-2.54_1x5 | H1,H2 | HDR-5X1/2.54 | 2
10 | 100uF | C13,C7,C19,C14 | 1206 | 4
11 | 22uF | C12 | 0603 | 1
12 | TEENSY 4.0 W. USB ONLY | MCU2 | TEENSY 4.0 W. USB ONLY | 1

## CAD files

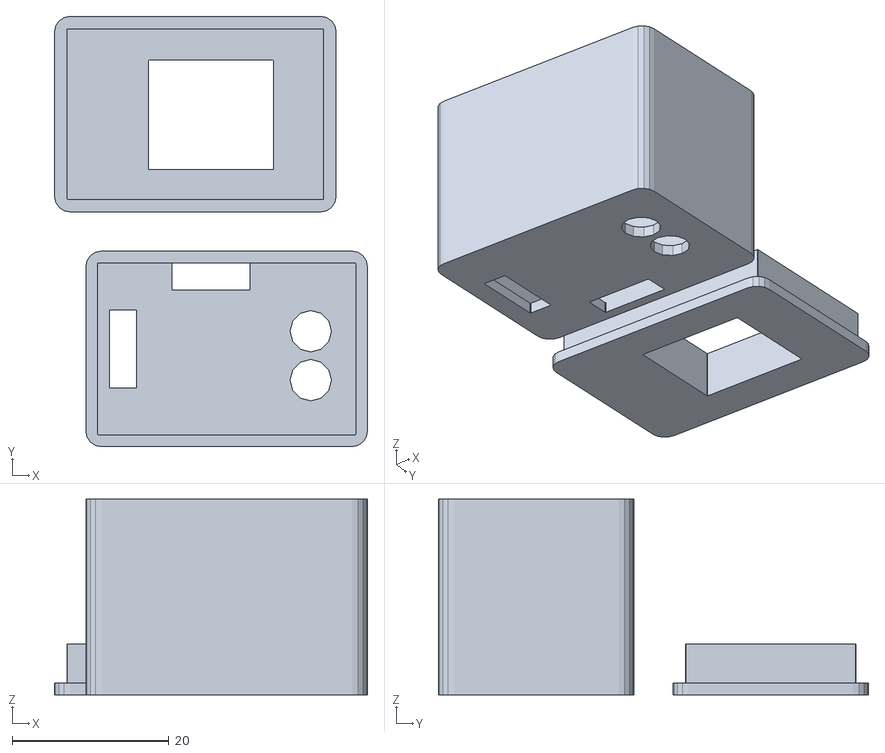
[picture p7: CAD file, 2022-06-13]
mechanics/adapterBox/usbc_power_data.stl
40.0 x 55.0 x 25.0

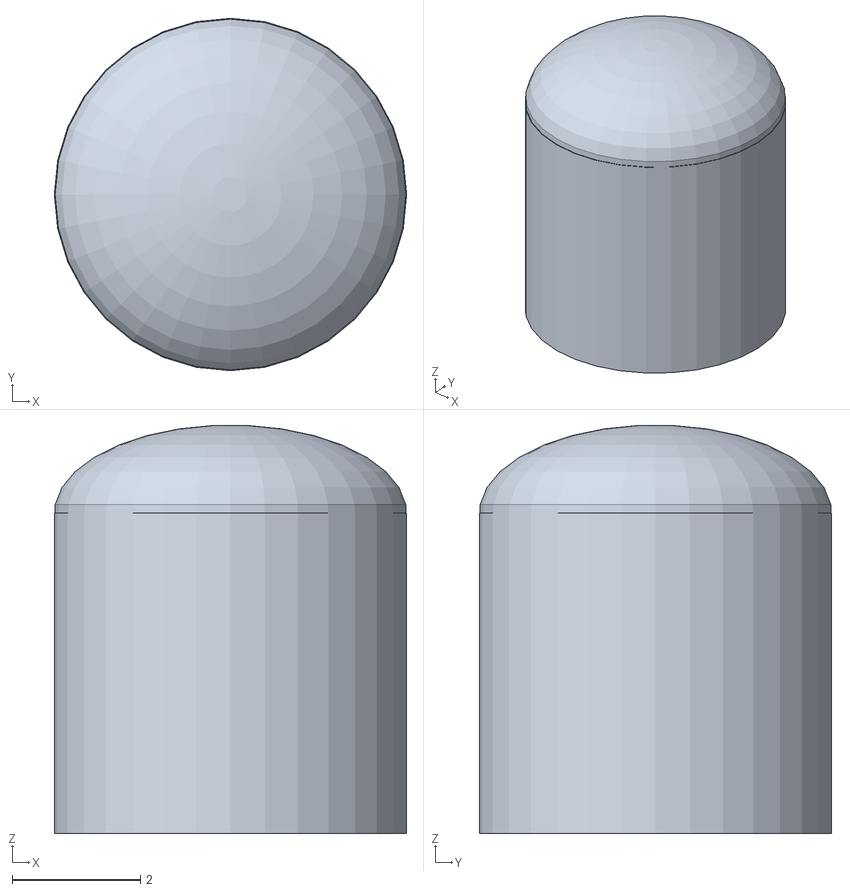
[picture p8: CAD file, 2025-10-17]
mechanics/body/littleButton.stl
5.50 x 5.50 x 6.37

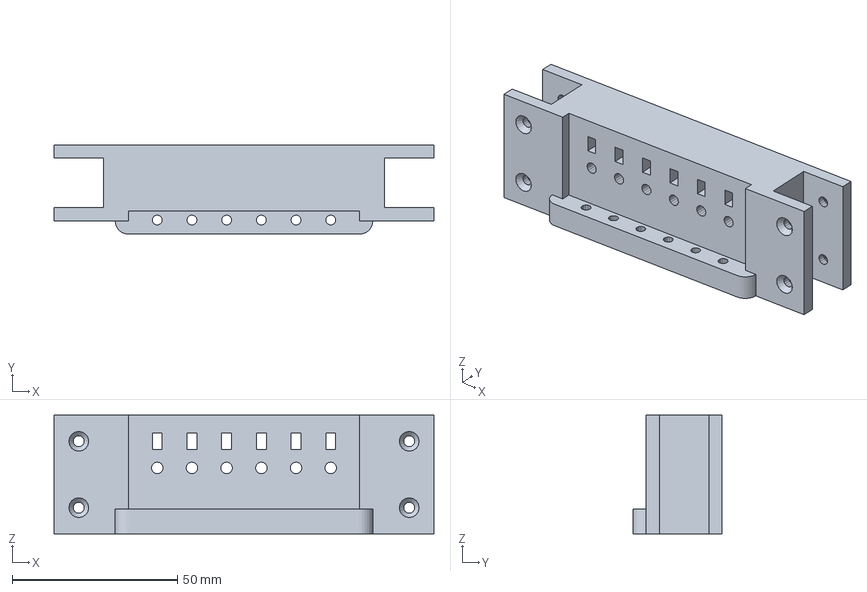
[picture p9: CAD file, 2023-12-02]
mechanics/bridge/bridge(piezo(ghost)).3mf
115.0 x 27.0 x 36.0 mm

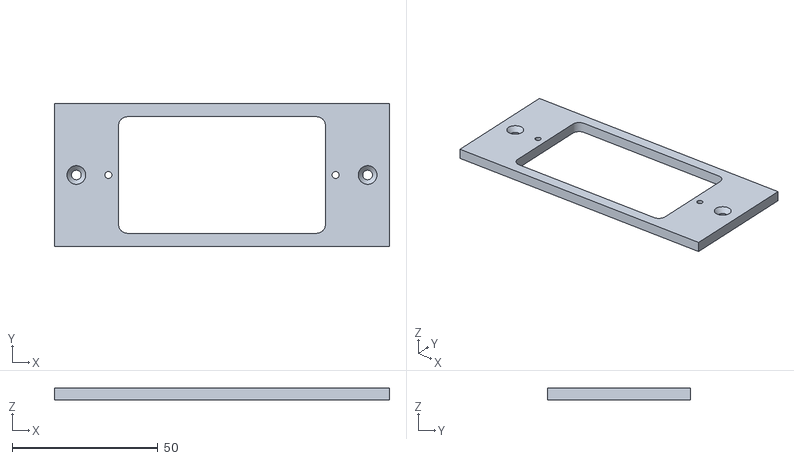
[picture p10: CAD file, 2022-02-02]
mechanics/fretboard/pickup(hb).stl
115.0 x 49.0 x 4.00

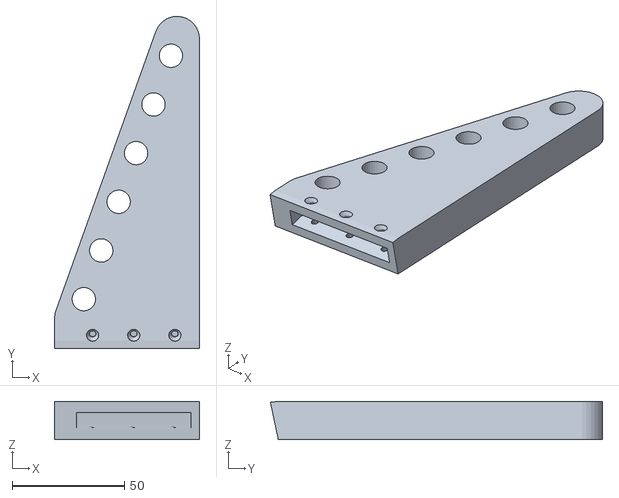
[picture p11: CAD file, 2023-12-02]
mechanics/head/head.stl
64.5 x 147.8 x 17.0

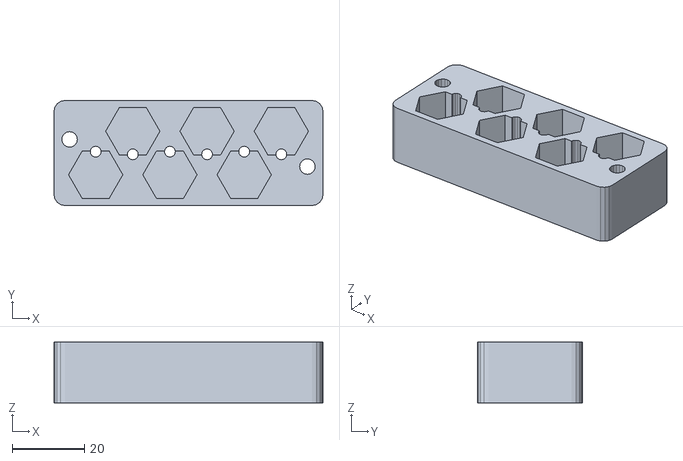
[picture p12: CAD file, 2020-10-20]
mechanics/kickup_mEbow/kickup-base.stl
74.2 x 29.0 x 16.8

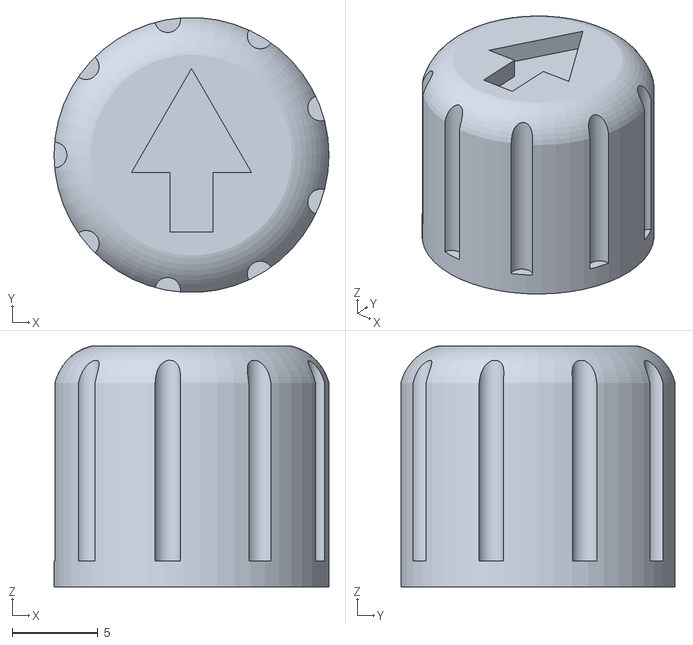
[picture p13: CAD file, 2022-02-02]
mechanics/knobs/rotSwKnob(ext).stl
16.0 x 16.0 x 14.0

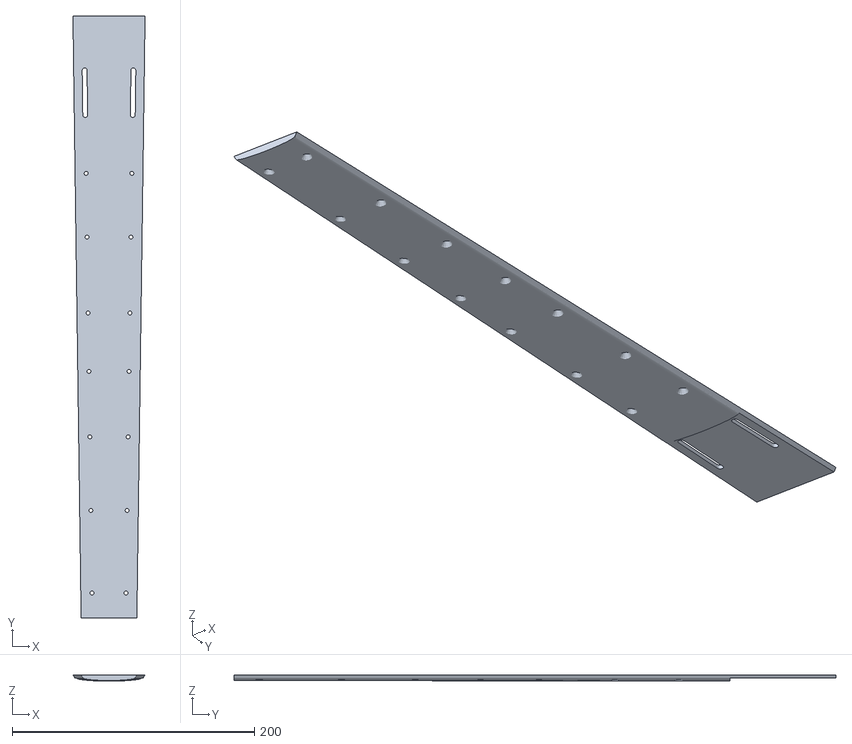
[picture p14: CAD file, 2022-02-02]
mechanics/neck/neck_mntBtm.stl
59.5 x 496.7 x 5.21

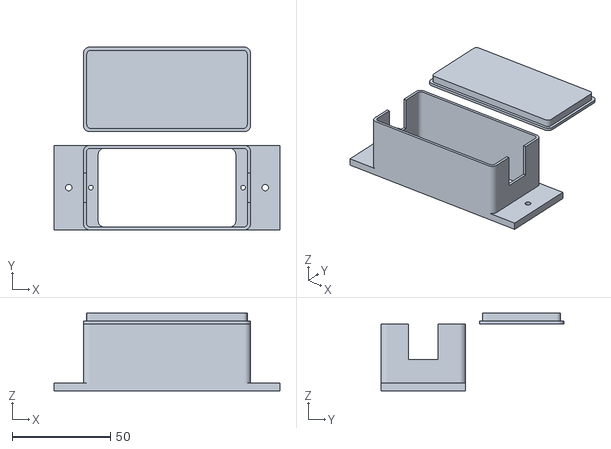
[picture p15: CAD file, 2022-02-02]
mechanics/pickup(HB)/pickup(hb).stl
115.0 x 93.0 x 39.5

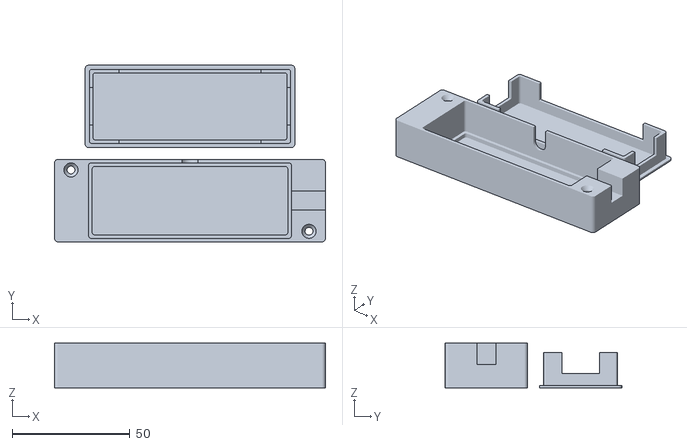
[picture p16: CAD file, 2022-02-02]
mechanics/preamp/preampCase.stl
115.0 x 75.0 x 19.0

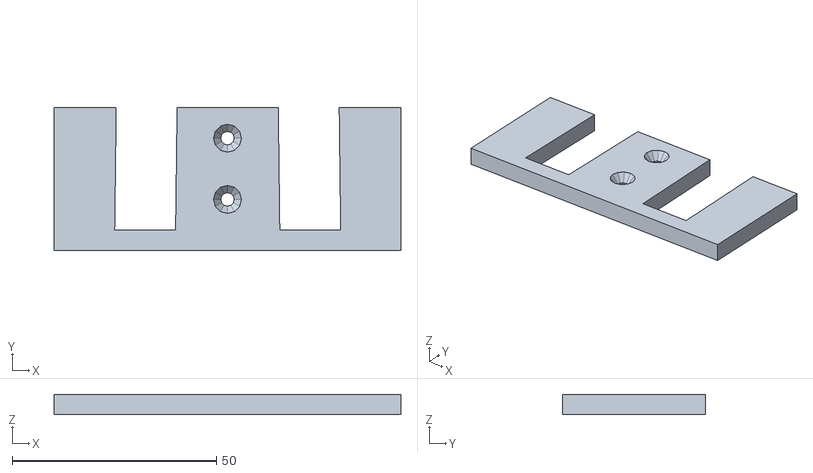
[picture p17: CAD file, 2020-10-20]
mechanics/skeleton/slotBody-spacer.stl
85.0 x 35.0 x 5.00

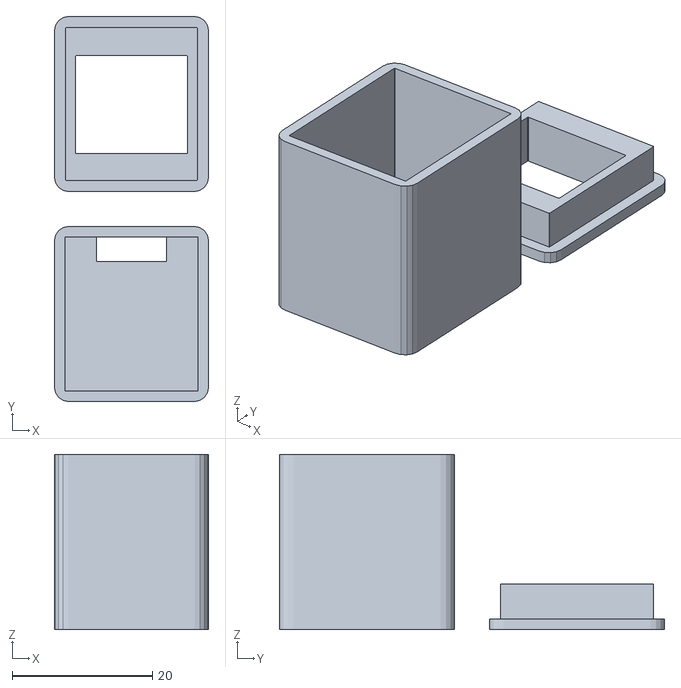
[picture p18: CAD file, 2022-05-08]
mechanics/adapterBox/usbc_power.stl
22.0 x 55.0 x 25.0

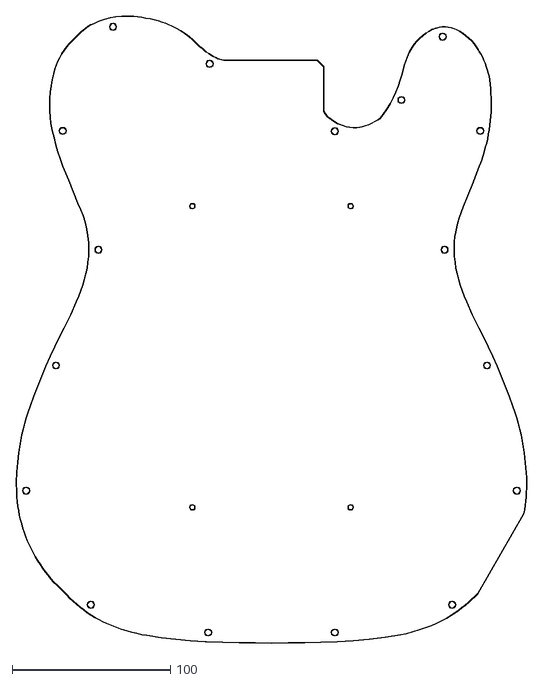
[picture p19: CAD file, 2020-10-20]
mechanics/body/bodyBtm.dxf
322.0 x 395.7

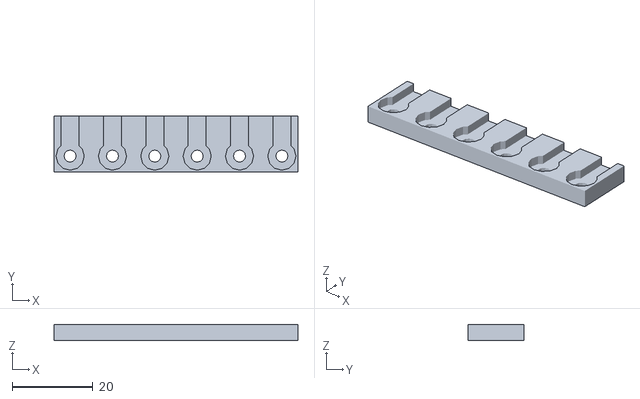
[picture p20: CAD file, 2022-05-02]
mechanics/bridge/stringContact.stl
60.5 x 14.0 x 4.00

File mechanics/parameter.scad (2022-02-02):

nStrings=6;
nFrets=24;
nLedFrets=16;
m5Dia=5.3;
m5HeadZ=3.5;
m4Dia=4.3;
m4NutDia=8.3;
m4NutZ=3.5;
m4HeadZ=2.5;
m3Dia=3.3;
m3NutDia=6.6;
m3NutZ=2.5;
m3HeadZ=2;
m3HeadDia=6;
m2Dia=2.4;
m2HeadZ=2;
strDistN=7;
strDistB=10.5;
scale=645;
neckSlotY=500;

slotXY=15;

bodySlotX=115;
bodySlotY=250;

jackYA=40;
jackYB=54;
jackZA=20;
jackZB=25;

bodyX=300;

bodyZ=40;

strDia=[1.7,1.4,1.1,0.7,0.5,0.35];

fretStrPlus=4;
fretLN=strDistN*(nStrings-1)+fretStrPlus*2;
fretLB=strDistB*(nStrings-1)+fretStrPlus*2;
strSpanB=strDistB*(nStrings-1);
strSpanN=strDistN*(nStrings-1);
fretBtmZ=1;
neckSlotX=fretLN;
neckSlotDist=neckSlotX-slotXY*2;

neck_sideT=5.5; //thicknes of the neck side locks
neck_bottomT=2.5;

neck_mntPosYA=447;
neck_mntPosYB=420;
neck_mntEndT=2.5;
neck_lastFretSpc=13;

nut_slotSink=6;

//fretY=16;
fretPcbZ=1.6;
fretDia=3.5;
fretZ=1.5;
fretOvrZ=4;
fretboardZ=fretOvrZ+fretPcbZ;



L=scale;
k=1.05946;

fretPos1=scale-(scale/pow(k,4));

function fretPos(i)=L-(L/pow(k,i));
function fretSpc(i)=(L/pow(k,i))-(L/pow(k,i+1));
function strSpc(i)=i/L*strDistB+(1-i/L)*strDistN;
function fretL(i)=(i/L*strDistB+(1-i/L)*strDistN)*(nStrings-1)+fretStrPlus*2;

echo (70-(fretL(fretPos(1))));

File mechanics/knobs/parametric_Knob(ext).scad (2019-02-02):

/*

Parametric Potentiometer Knob Generator
version 1.4
2013 Steve Cooley
http://sc-fa.com
http://beatseqr.com
http://hapticsynapses.com

parametric potentiometer knob generator by steve cooley is licensed under a Creative Commons Attribution-NonCommercial-ShareAlike 3.0 Unported License. Based on a work at sc-fa.com. Permissions beyond the scope of this license may be available at http://sc-fa.com/blog/contact.

view terms of the license here:
http://creativecommons.org/licenses/by-nc-sa/3.0/


version history
---------------
1.4 2013-07-16 added an additive OR subtractive pill shaped indicator type
1.3 2013-04-01 updated for more awesome Thingiverse Customizer
1.2 2013-01-09 updated for Thingiverse Customizer
1.1 2012-04-12 fixed the arrow indicator code to be more robust and easier to adjust parameters for.
1.0 2012-03-?? initial release.


*/

/* [Physical attributes] */

bottom_spaceH=0;
bottom_spaceD=11;
layerH=0;

// All values are in Millimeters!  How big the top of the knob is:
01_knob_diameter_top = 13; //[10:100]
knob_radius_top = 01_knob_diameter_top / 2;

// How big the bottom of the knob is:
02_knob_diameter_bottom = 13; // [10:100]
knob_radius_bottom = 02_knob_diameter_bottom / 2;

// how tall the knob is:
03_knob_height = 12; // [5:50]
knob_height = 03_knob_height / 1;

// how smooth or geometric the knob is:
04_knob_smoothness = 40; // [3:40]
knob_smoothness = 04_knob_smoothness / 1;

// (measure the potentiometer shaft with calipers and remember to add a bit for shrinkage.)
05_shaft_diameter = 6.2; // this could be a slider if precision were available
shaft_radius = 05_shaft_diameter / 2;

// how much of the shaft the knob should allow space inside for:
06_shaft_height = 10; // [1:40]
shaft_height = 06_shaft_height / 1;

// higher is smoother
07_shaft_smoothness = 20; // [3:20]
shaft_smoothness = 07_shaft_smoothness / 1;

// some potentiometers have a flat surface on the shaft to allow for the use of a set screw.
08_shaft_hole_is_flatted = "true"; // [true,false]

// ignore if no flat is needed.
09_shaft_hole_flat_size = 5; // this could be a slider if precision were available
flat_size = 09_shaft_hole_flat_size / 1;

/* [Set screw] */

// some potentiometers need to have their knobs affixed with a set screw.
10_set_screw = "false"; //[true,false]

// in MM:
11_set_screw_diameter = 3; // [0:8]
set_screw_radius = 11_set_screw_diameter / 2;

// how deep into the knob, from the side:
12_set_screw_depth = 9; // [0:20]
set_screw_depth = 12_set_screw_depth / 1;

// from the top:
13_set_screw_height = 4; // [0:20]
set_screw_height = 13_set_screw_height / 1;

// higher is smoother:
14_quality_of_set_screw = 20; // [0:20]
quality_of_set_screw = 14_quality_of_set_screw / 1;

/* [Decorations] */

// thanks to http://www.iheartrobotics.com/ for the articles!
15_top_edge_smoothing = "true"; // [true,false]

// how big of a smoothing radius to apply
16_top_edge_smoothing_radius = 3.0; // [1:10]
smoothing_radius = 16_top_edge_smoothing_radius / 1;

// Number of facets for the rounding cylinder
17_top_edge_smoothing_smoothness = 20.0; // [1:40]
smooth = 17_top_edge_smoothing_smoothness / 1;

ct = -0.1 / 1; 							// circle translate? not sure.
circle_radius = knob_radius_top / 1;  	// just match the top edge radius
circle_height = 1 / 1; 					// actually.. I don't know what this does.
pad = 0.2 / 1;							// Padding to maintain manifold



/* [External indicator] */

// this is a corner edge of a cube sticking out of the cylinder at the bottom, you can use it instead of the arrow shaped cutout in the top if you like. Or both.
18_pointy_external_indicator = "false"; // [true,false]


// how tall should the indicator be, from the bottom:
19_pointy_external_indicator_height = 3; // [1:50]
pointy_external_indicator_height = 19_pointy_external_indicator_height / 1;

// how far out the indicator should poke out:
20_pointy_external_indicator_pokey_outey_ness = 1.0;
pointy_external_indicator_pokey_outey_ness = 20_pointy_external_indicator_pokey_outey_ness * 1;

pokey_outey_value = pointy_external_indicator_pokey_outey_ness - 1 - pad;
pokey_outey = [pokey_outey_value, pokey_outey_value,0];

// there's an arrow shaped hole you can have. There aren't a lot of controls for this.
// please feel free to improve on this script here.

/* [Pill-shaped indicator] */

// there's an arrow shape you can have in the top of the knob.
00_pill_indicator = "false"; // [true,false]

// add or subtract the pill shape?
00_pill_add_or_subtract = "add"; // [add,subtract]

// relative scale of the pill shape:
00_pill_scale = 1.0;

// height of the pill shape:
00_pill_height = 16.0;

// relative scale of length of the pill shape:
00_pill_length = 2.5;

// where to put the arrow, x:
00_pill_location_x = 0.0;

// where to put the arrow, y:
00_pill_location_y = 5.0;

// where to put the arrow, z:
00_pill_location_z = 0.0;

pill_translate = [00_pill_location_x,00_pill_location_y,00_pill_location_z];


/* [Internal Arrow indicator] */

// there's an arrow shape you can have in the top of the knob.
21_top_of_knob_arrow_indicator = "false"; // [true,false]

// scale the arrow head:
22_arrow_head_scale = 2.0;
arrow_scale_head = 22_arrow_head_scale / 1;

// scale the arrow shaft:
23_arrow_shaft_scale = 1.5;
arrow_scale_shaft = 23_arrow_shaft_scale / 1;

// how big the overall arrow indicator should be:
24_arrow_indicator_scale = 1.3;
arrow_indicator_scale = 24_arrow_indicator_scale / 1;

// where to put the arrow, x:
25_arrow_location_x = 0.0;

// where to put the arrow, y:
26_arrow_location_y = 1.0;

// where to put the arrow, z:
27_arrow_location_z = 16.0;

arrow_indicator_translate = [25_arrow_location_x,26_arrow_location_y,27_arrow_location_z];



/* [Sphere Indentations] */

// for spherical indentations, set the quantity, quality, size, and adjust the placement
28_indentations_sphere = "false"; // [true,false]

29_sphere_number_of_indentations = 12; // [1:50]
sphere_number_of_indentations = 29_sphere_number_of_indentations / 1;

30_sphere_quality_of_indentations = 40; // [1:100]
sphere_quality_of_indentations = 30_sphere_quality_of_indentations / 1;

31_size_of_sphere_indentations = 4; // [1:20]
size_of_sphere_indentations = 31_size_of_sphere_indentations / 1;

// the first number in this set moves the spheres in or out. smaller is closer to the middle
32_sphere_indentation_location_x = 12.0;

// the second number in this set moves the spheres left or right
33_sphere_indentation_location_y = 00.0;

// the third number in this set moves the speheres up or down
34_sphere_indentation_location_z = 15.0;

translation_of_sphere_indentations = [32_sphere_indentation_location_x,33_sphere_indentation_location_y,34_sphere_indentation_location_z];

// in case you are using an odd number of indentations, you way want to adjust the starting angle so that they align to the front or set screw locations.
35_sphere_indentation_starting_rotation = 30; // [-90:90]
sphere_starting_rotation = 35_sphere_indentation_starting_rotation / 1 + 90;

/* [Cylinder Indentations] */

// for cylinder indentations, set quantity, quality, radius, height, and placement
36_indentations_cylinder = "true"; // [true,false]

37_number_of_cylinder_indentations = 9; // [1:40]
cylinder_number_of_indentations = 37_number_of_cylinder_indentations / 1;

// higher is smoother:
38_smoothness_of_cylinder_indentations = 50; // [3:100]
cylinder_quality_of_indentations = 38_smoothness_of_cylinder_indentations / 1;

39_diameter_of_top_of_the_cylinder = 1.5; // [1:20]
radius_of_cylinder_indentations_top = 39_diameter_of_top_of_the_cylinder / 2;

40_diameter_of_bottom_of_the_cylinder = 1.5;  // [1:20]
radius_of_cylinder_indentations_bottom = 40_diameter_of_bottom_of_the_cylinder / 2;

41_height_of_cylinder_indentations = 15.0; // [0:40]
height_of_cylinder_indentations = 41_height_of_cylinder_indentations / 1;

// this moves the cylinders in or out from the center
42_position_of_cylinder_x = -0.0; //[-20:20]

// this moves the cylinders left or right
43_position_of_cylinder_y = 0.0; //[-20:20]

// this moves the cylinders up or down
44_position_of_cylinder_z = -5.0; //[-20:20]

translation_of_cylinder_indentations = [42_position_of_cylinder_x,43_position_of_cylinder_y,44_position_of_cylinder_z];

45_cylinder_starting_rotation = -30; // [-90:90]
cylinder_starting_rotation = 45_cylinder_starting_rotation / 1 - 90;


// these are some setup variables... you probably won't need to mess with them.
negative_knob_radius = knob_radius_bottom*-1;


// this is the main module. It calls the submodules.
make_the_knob();
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

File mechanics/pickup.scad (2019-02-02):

include <parameter.scad>
pickup();

!rotate([0,0,0])coil();


module pickup(){
strings=6;
spacing=strSpanB;
echo (spacing);
diameter=10.5;
wall=2;
coilZ=12;
bottomZ=2;
t=0.3;
ySpacing=11;

bX = spacing+diameter+wall*4;
bY=ySpacing+diameter+wall*1;
bZ=coilZ+bottomZ+t;

tX = bX;
tY=bY;
hub=2.5;
magZ=1.5;
magDia=3.2;
tbottomZ=2;
tZ=hub+magZ+tbottomZ;
tDia=6.7;//6.5;
screwTdia=3.3;

screwMdia=4.3;
screwAdia=2.25;


module base(){
$fn=16;
difference(){
translate([0,0,0])rcube([bX,bY,bZ],3);

translate([-spacing/2,0,0]){
for(x=[0:strings-1]){
translate([x*(spacing/(strings-1)),ySpacing/2,0]){
translate([0,0,bottomZ])rotate([0,0,30])cylinder(d=diameter,h=100,$fn=6);
translate([0,0,-1])cylinder(d=magDia,h=100,$fn=16);
rotate([0,0,30])translate([0,-diameter/2+0.5,0])cylinder(d=screwAdia,h=100);
}}

for(x=[0:strings-1]){
translate([x*(spacing/(strings-1)),-ySpacing/2,0]){
translate([0,0,bottomZ])rotate([0,0,30])cylinder(d=diameter,h=100,$fn=6);
translate([0,0,-1])cylinder(d=magDia,h=100,$fn=16);
rotate([0,0,30])translate([0,diameter/2-0.5,0])cylinder(d=screwAdia,h=100);
}}

}
translate([-bX/2+screwMdia*0.8,0,0])cylinder(d=screwMdia-t,h=bZ);
translate([bX/2-screwMdia*0.8,0,0])cylinder(d=screwMdia-t,h=bZ);
}

}

//for(x=[0:strings-1]){
//translate([-spacing/2+x*(spacing/(strings-1)),-ySpacing/2,bottomZ]){
//rotate([0,0,0])coil();
//}}
base();
}

module coil(){
$fn=32;
magholedia=4;
wallthick=0.5;
loweridlerZ=1.8;
upperidlerZ=1.8;
rampBZ=0.1;
rampTZ=0.1;
coildia=10.25;
rampdia=coildia;
threaddepth=5;
roofZ=0;//loweridlerZ;
coilZ=12;
idlRes=6;

difference(){
union(){
cylinder(d=magholedia+wallthick*2,h=coilZ);
translate([0,0,loweridlerZ])cylinder(d1=rampdia,d2=magholedia+wallthick*2,h=rampBZ,$fn=idlRes);
translate([0,0,coilZ-upperidlerZ-rampTZ])cylinder(d2=rampdia/100*100,d1=magholedia+wallthick*2,h=rampTZ,$fn=idlRes);
translate([0,0,coilZ-upperidlerZ])cylinder(d=coildia/100*100,h=upperidlerZ,,$fn=idlRes);
//Ccube([coildia,coildia,upperidlerZ],[0,0,1]);
translate([0,0,0]){
//Ccube([coildia,coildia,loweridlerZ],[0,0,1]);
cylinder(d=coildia,h=loweridlerZ,$fn=idlRes);

}
}

translate([0,0,-roofZ])cylinder(d=magholedia,h=coilZ);
//cylinder(d=coilthreaddia,h=coilZ+1);
}}

module rcube(size,radius){
linear_extrude(height=size[2])
if(radius>0){
hull()
{
    // place 4 circles in the corners, with the given radius
    translate([(-size[0]/2)+(radius), (-size[1]/2)+(radius), 0])
    circle(r=radius);

    translate([(size[0]/2)-(radius), (-size[1]/2)+(radius), 0])
    circle(r=radius);

    translate([(-size[0]/2)+(radius), (size[1]/2)-(radius), 0])
    circle(r=radius);

    translate([(size[0]/2)-(radius), (size[1]/2)-(radius), 0])
    circle(r=radius);
}
}
if(radius==0){
translate([0,0,size[2]/2])cube(size,center=true);
}
}

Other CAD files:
docs/ext_ressources/nu_pickups/nu-master/cad_drawings/nu_multi/nu_multi_8.DWG
docs/ext_ressources/nu_pickups/nu-master/cad_drawings/nu_multi/nu_multi_6.DWG
mechanics/fretboard/fretConnect.stl
mechanics/kickup_mEbow/kickup-top.stl
mechanics/putTogether.scad
docs/ext_ressources/nu_pickups/nu-master/cad_drawings/nu_multi/Nu_Multi_6_Routing_Template_Drawing.DXF
docs/ext_ressources/nu_pickups/nu-master/cad_drawings/nu_multi/nu_multi_7.DWG
electronics/hexPreamp(jfet)/case.scad
mechanics/adapterBox/AdapterBox.scad
mechanics/adapterBox/usbc_power.scad
mechanics/adapterBox/usbc_power_data.scad
mechanics/body/body.scad
mechanics/body/body.stl
mechanics/body/bodyConFilled.dxf
mechanics/body/bodyCont.dxf
mechanics/body/bodyCont.stl
mechanics/body/bodyContFilled.stl
mechanics/body/bodyContFilled2.stl
mechanics/body/bodyContour.dxf
mechanics/body/bodyTop(noKnobs).dxf
mechanics/body/bodyTop.dxf
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

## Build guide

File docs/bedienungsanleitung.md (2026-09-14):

# ElektroCaster – Bedienungsanleitung

> **Stand und Geltungsbereich:** Diese Anleitung beschreibt ausschließlich das Verhalten, das sich aus dem aktuellen Firmware-Quellcode ableiten lässt. Die Bedienelemente sind im Code nur teilweise beschriftet; deshalb werden sie hier zusätzlich mit ihren Firmware-Indizes bezeichnet. Aussagen mit **„unklar“**, **„derzeit ohne Wirkung“** oder **„zu prüfen“** sind bewusst keine Vermutungen über die Hardware.

## Inhaltsverzeichnis

1. [Sicherheit und wichtige Einschränkungen](#1-sicherheit-und-wichtige-einschränkungen)
2. [Systemüberblick](#2-systemüberblick)
3. [Bedienelemente und Bezeichnungen](#3-bedienelemente-und-bezeichnungen)
4. [Globale Schalter und Taster](#4-globale-schalter-und-taster)
5. [Fader, Potis und Joystick](#5-fader-potis-und-joystick)
6. [String Setup und Stimmhilfe](#6-string-setup-und-stimmhilfe)
7. [Skalen- und Spielansicht](#7-skalen--und-spielansicht)
8. [Generischer Sequencer](#8-generischer-sequencer)
   - [Aufbau](#81-aufbau)
   - [Pattern-Drehschalter](#82-pattern-drehschalter)
   - [Spurparameter über Saiten-Encoder](#83-spurparameter-über-saiten-encoder)
   - [Step setzen und bearbeiten](#84-step-setzen-und-bearbeiten)
   - [Step-Parameter (`str`)](#85-step-parameter-str)
   - [Saitentaster-Funktionen (`btn`)](#86-saitentaster-funktionen-btn)
   - [Pattern kopieren](#87-pattern-kopieren)
9. [Saiten-Arpeggiator](#9-saiten-arpeggiator)
   - [Aktivieren](#91-aktivieren)
   - [Globale Arpeggiatorfunktionen](#92-globale-arpeggiatorfunktionen)
10. [Spielen, Griffbrettsensing und Aktoren](#10-spielen-griffbrettsensing-und-aktoren)
11. [Clock und Synchronisation](#11-clock-und-synchronisation)
12. [MIDI-Funktionen](#12-midi-funktionen)
13. [Songs und SD-Karte](#13-songs-und-sd-karte)
14. [OLED- und LED-Anzeigen lesen](#14-oled--und-led-anzeigen-lesen)
15. [Bekannte derzeitige Grenzen](#15-bekannte-derzeitige-grenzen)
16. [Empfohlener erster Funktionstest](#16-empfohlener-erster-funktionstest)

## 1. Sicherheit und wichtige Einschränkungen

- Die ElektroCaster ist ein Prototyp mit sechs **Kickup-Magneten** und sechs elektromagnetischen **MulEBow-Spulen**. Aktoren nur mit korrekt dimensionierter Versorgung und Treiberhardware betreiben. Vor Arbeiten an Saiten, Steg, Spulen oder Verkabelung die Aktorversorgung trennen.
- Kickup kann eine Saite selbsttätig anschlagen. Hände und lose Gegenstände aus dem Bewegungsbereich halten.
- MulEBow erzeugt ein elektromagnetisches Dauersignal. Bei ungewöhnlicher Erwärmung oder Geräuschentwicklung sofort ausschalten.
- Die Firmware zeigt keine aus dem Code erkennbare Fehler- oder Schutzmeldung am OLED für SD-, Audio- oder Kommunikationsfehler an.
- Die reale Anordnung, Beschriftung, Schalterpolarität und Saitennummerierung sind nicht vollständig dokumentiert. Vor einem Bühnen- oder Lautstärkebetrieb alle Zuordnungen bei kleiner Lautstärke prüfen.
- Die Firmware verwendet intern die **Saitenindizes 0 bis 5**. OLED-Werte werden meist in umgekehrter räumlicher Reihenfolge ausgegeben. Diese Anleitung spricht deshalb neutral von „Saite 0 … 5“ und nicht von hoher/tiefer E-Saite.

## 2. Systemüberblick

Die ElektroCaster kann zunächst wie eine normale Gitarre gespielt werden. Zusätzlich verarbeitet sie jede Saite getrennt und bietet:

- ein berührungsempfindliches Griffbrett mit 21 erfassten Bundpositionen,
- 150 RGB-LEDs, entsprechend 25 LED-Positionen je Saite,
- hexaphonische Filter-, Hüllkurven- und Ringmodulationsverarbeitung,
- Kickup zum mechanischen Anschlagen einzelner Saiten,
- MulEBow zum elektromagnetischen Anregen gegriffener Saiten,
- USB-MIDI-Ausgabe und USB-MIDI-Eingang,
- drei parallele generische Sequencer-Instanzen mit je sechs Patterns,
- einen alternativen Saiten-Arpeggiator mit sechs Patterns,
- 100 Song-Speicherplätze auf SD-Karte,
- Skalen-, MIDI- und Sequencer-Anzeigen auf dem LED-Griffbrett.

Beim Start lädt der Hauptcontroller **Song 0**, anschließend die separat gespeicherte Saitenstimmung und die Saitenpegel. Der interne Standardwert ist 90 BPM; gestartet wird die Clock erst über die Wiedergabetaste oder einen entsprechenden Steuerablauf.

## 3. Bedienelemente und Bezeichnungen

### 3.1 Übersicht

| Bedienelement | Anzahl | Bezeichnung in dieser Anleitung |
| --- | ---: | --- |
| Schieberegler | 10 | Fader 1 … 10 |
| Potentiometer | 7 | Poti 1 … 7 |
| Joystick | 1, zweiachsig | Joystick X/Y |
| Drehencoder | 8 | Display-Encoder, sechs Saiten-Encoder, Sammel-Encoder |
| 12-Stufen-Drehschalter | 3 | Pattern-Schalter 1 … 3 |
| digitale Eingänge | 19 | Display-Taster, Shift, drei Aktor/Auto-Schalter, drei Transporttaster, Poti-Schalter, Speichertaster, Poti-Encoder-Taster, zwei Griffbrett-Schalter, sechs Saiten-Encoder-Taster |

Die Zuordnung „Fader/Poti“ folgt den Kommentaren im Controllercode. Ein analoger Eingang ist dort als „Poti 7“ geführt; die übrigen sechs als Poti 1, 2, 3, 5 und 6 sowie ein weiterer, nur durch seine Funktion erkennbarer LFO-Regler. Eine physische Beschriftung für „Poti 4“ ist aus dem Code nicht sicher rekonstruierbar.

### 3.2 Encoder

- **Display-Encoder:** Der einzelne Encoder neben dem OLED. Drehen verändert je nach Ansicht einen Wert oder die gewählte Funktionszeile. Drücken schaltet zwischen diesen beiden Ebenen um.
- **Saiten-Encoder 0 … 5:** Je ein Encoder pro Saite. Sie ändern den aktuell gewählten Saitenparameter. Ihre Anzeige auf dem OLED erfolgt von links nach rechts in der Reihenfolge Saite 5 … 0.
- **Sammel-Encoder:** Ändert den aktuellen Parameter grundsätzlich für alle sechs Saiten. Im Step-Edit-Modus kann er stattdessen den gewählten Step-Parameter bearbeiten.
- Die HID-Firmware teilt Encoderbewegungen durch vier. Eine wahrnehmbare Rasterbewegung entspricht daher erst nach vier Rohschritten einer Änderung.

### 3.3 Display-Encoder bedienen

In den Skalen-, Sequencer- und Arpeggiatoransichten gilt grundsätzlich:

1. **Display-Taster nicht gedrückt:** Drehen ändert den Wert der markierten Zeile.
2. **Display-Taster gedrückt:** Drehen verschiebt die Auswahlmarkierung zwischen den Zeilen.

Im String-Setup wechselt das Drehen des Display-Encoders direkt zwischen Stimmung, Saitenpegel und BPM; der Tastenzustand wird dort nicht ausgewertet.

## 4. Globale Schalter und Taster

### 4.1 Shift-Taster

Der Taster unter dem Display-Encoder setzt den globalen `shift`-Zustand. Shift verändert folgende Funktionen:

- zusammen mit **MulEBow-Schalter**: interne/externe Clock auswählen,
- zusammen mit **Kickup-Schalter**: Griffbrett-Vollerkennung/vereinfachte Erkennung auswählen,
- beim Bearbeiten eines Sequencer-Steps: den Step löschen bzw. mit dem Display-Encoder alle Steps der gewählten Saite(n) ändern,
- beim Songwechsel: vor dem Wechsel Song 0 statt des aktuell gewählten Slots speichern,
- zusammen mit Speichertaster und gedrücktem Display-Taster: Standard-Song nur im Arbeitsspeicher herstellen.

Der Code wertet einen Zustand aus, nicht ausdrücklich eine Haltezeit. Ob der physische Taster als momentaner Taster oder rastender Schalter ausgeführt ist, muss am Instrument geprüft werden.

### 4.2 Dreifach-Schaltergruppe

| Schalter | Ohne Shift | Mit Shift |
| --- | --- | --- |
| links | Automatik für Instanz 1: generischen Saitensequencer oder, bei gewähltem Arpeggiator, Arpeggiator ein/aus | keine zusätzliche Sonderfunktion |
| Mitte | MulEBow ein/aus | setzt gleichzeitig `extClk`: aus = interne Clock, ein = externe USB-MIDI-Clock |
| rechts | Kickup ein/aus | setzt gleichzeitig den Griffbrett-Sensormodus: aus = Bundposition erkennen, ein = nur gedrückt/nicht gedrückt erkennen |

**Wichtig:** Mit Shift werden MulEBow beziehungsweise Kickup trotzdem ebenfalls geschaltet. Die Clock- beziehungsweise Sensormoduswahl ist keine getrennte, „stumme“ Zweitfunktion.

### 4.3 Dreifach-Tastergruppe

| Taster | Funktion |
| --- | --- |
| rechts | plant die Synchronisierung aller drei Sequencer-Instanzen und des Arpeggiators auf den nächsten Taktwechsel |
| Mitte | schaltet Start/Stop um; Start sendet USB-MIDI Start, danach 24 Clock-Ticks pro Viertelnote, Stop sendet USB-MIDI Stop und All Notes Off |
| links | wählt zyklisch Sequencer-Instanz 1, 2, 3 und schaltet auf deren Bedienmodus |

### 4.4 Griffbrett-Schalter

- **Edit/Play-Schalter (`fbrdMode`):**
  - `0` = Spielen. Berührte Bünde erzeugen je nach Automatikzustand Hüllkurven-, MIDI- und Kickup-Ereignisse; das LED-Griffbrett zeigt die Skalen-/Notenansicht.
  - `1` = Step-Edit. Die ersten 16 Bundpositionen dienen zum Setzen und Bearbeiten von Sequencer-Steps; das LED-Griffbrett zeigt das Raster. Außer im alternativen Arpeggiatorbetrieb wird der Audio-Hauptausgang dabei stummgeschaltet.
- **Sequencer-Ansicht halten (`fbrdSeqVHld`):** Zeigt das Sequencer- oder Arpeggiatorraster auch im Spielmodus. Der Kommentar im Code bezeichnet diese Ansicht ausdrücklich als **nicht editierbar**.

### 4.5 Poti-Schalter und Encoder-Taster

Der **Poti-Schalter** wählt die Funktion der sechs Saiten-Encoder-Taster:

- Stellung `1`: Ein Saiten-Encoder-Taster wählt direkt eine Encoderfunktion. Wegen der umgekehrten Zuordnung wählen die sechs Taster die Funktionsindizes 5 … 0. Beim generischen Sequencer existieren nur fünf gültige Encoderfunktionen; der zusätzliche Index 5 wird zwar gesetzt, hat aber keine implementierte Wirkung. Beim Arpeggiator gilt dasselbe für den zusätzlichen Index 5.
- Stellung `0`: Ein Saiten-Encoder-Taster führt die aktuell im OLED unter `btn` gewählte Saitenfunktion aus.

Der separate **Poti-Encoder-Taster** führt die aktuell gewählte generische Saitentaster-Funktion gleichzeitig für alle sechs Saiten aus. Er ruft auch im Arpeggiatorbetrieb die generische Sequencerfunktion auf, nicht die Arpeggiatorfunktion.

## 5. Fader, Potis und Joystick

Alle analogen Werte werden intern auf ungefähr 0 … 1 normiert.

| Regler | Funktion | Ausgabebereich / Hinweis |
| --- | --- | --- |
| Fader 1 | USB-MIDI CC 3, Kanal 1 | 0 … 127 |
| Fader 2 | USB-MIDI CC 4, Kanal 1 | 0 … 127 |
| Fader 3 | USB-MIDI CC 5, Kanal 1 | 0 … 127 |
| Fader 4 | USB-MIDI CC 6, Kanal 1 | 0 … 127 |
| Fader 5 | Filter-Hüllkurven-Decay | skaliert bis ca. 5000 ms |
| Fader 6 | Amplituden-Hüllkurven-Decay | skaliert bis ca. 5000 ms |
| Fader 7 | Filter-Hüllkurven-Attack | skaliert bis ca. 1000 ms |
| Fader 8 | Amplituden-Hüllkurven-Attack | skaliert bis ca. 1000 ms |
| Fader 9 | Anteil der Filterhüllkurve | Überblendung zwischen konstantem und Hüllkurven-Steuersignal |
| Fader 10 | Anteil der Amplitudenhüllkurve | Überblendung zwischen trockenem Ringmodulationssignal und Hüllkurvensignal |
| Joystick X | USB-MIDI CC 9, Kanal 1 | 0 … 127 |
| Joystick Y | USB-MIDI CC 10 **und** Channel Aftertouch, Kanal 1 | beide 0 … 127 |
| Poti 1 | Audio-Gesamtlautstärke | nichtlinear; Controller begrenzt den übertragenen Maximalwert zur Clipping-Vermeidung |
| Poti 2 | Filterresonanz | Audio-Skalierung etwa 0 … 7 |
| Poti 3 | Filter-Oktavsteuerung | Audio-Skalierung etwa 0 … 7 |
| Poti 4 (im Code nicht ausdrücklich kommentiert) | LFO-Tonhöhenoffset | etwa −12 … +12 Halbtöne |
| Poti 5 | USB-MIDI CC 7, Kanal 1 | 0 … 127 |
| Poti 6 | LFO-/Ringmodulations-Tiefe | Amplitude steigt, Offset sinkt entsprechend |
| Poti 7 | LFO-Oktavlage | intern ungefähr −5 … +4 Oktaven |

Beim manuellen Greifen hält die Firmware die Amplituden- und Filterhüllkurve für die jeweilige Saite auf Sustain, selbst wenn der Decay-Regler kürzer eingestellt ist. Beim Loslassen oder bei automatischer Triggerung gilt wieder die normale Decay-/Sustain-Logik.

## 6. String Setup und Stimmhilfe

### 6.1 Aufrufen

String Setup ist Betriebsmodus 0. Er wird über **Pattern-Schalter 2 oder 3, Stellung 6** (`val == 6`) aufgerufen. Pattern-Schalter 1 wechselt ab Stellung 6 stattdessen in den Arpeggiatorbetrieb.

### 6.2 Parameter

Der Display-Encoder wählt eine von drei markierten OLED-Zeilen:

1. **Stimmung:** Saiten-Encoder verschieben die Sollstimmung der jeweiligen Saite in MIDI-Halbtönen. Das OLED zeigt nur den Notennamen ohne Oktave.
2. **Saitenpegel:** Bereich 0 … 50; der Wert wird als Verstärkung von 0,00 … 1,00 an den Audio-Controller übertragen.
3. **BPM:** Bereich 1 … 250; jeder Saiten-Encoder verändert denselben globalen Tempowert.

Der Sammel-Encoder transponiert im String Setup stets alle sechs Stimmungen zugleich, unabhängig von der aktuell markierten OLED-Zeile.

Beim Verlassen des String Setup werden Stimmung und Saitenpegel separat gespeichert. Beim Systemstart werden sie nach Song 0 geladen und überschreiben damit die im Song enthaltenen entsprechenden Werte.

### 6.3 LED-Stimmhilfe

Im String Setup:

- markiert LED-Position 0 die eingestellte Leersaite in deren Tonfarbe,
- dient Position 12 als mittige Referenz,
- wird bei ausreichendem Eingangspegel die erkannte Tonhöhe farbig angezeigt,
- zeigt eine benachbarte LED an, ob die erkannte Tonhöhe oberhalb oder unterhalb des Zielbereichs liegt.

Die Richtung „zu hoch/zu tief“ relativ zur physischen Halsorientierung ist aus dem Code allein nicht sicher benennbar. Die Tonhöhenerkennung übernimmt nur Messwerte mit hoher Analysewahrscheinlichkeit; bei leiser oder instabiler Saite kann die Anzeige stehenbleiben.

## 7. Skalen- und Spielansicht

Die Skalenansicht erscheint in den Sequencer-Modi, wenn der Griffbrettschalter auf Spielen steht und „Sequencer-Ansicht halten“ aus ist.

### 7.1 Einstellbare Felder

Mit gedrücktem Display-Taster wählt man eines von sechs Feldern; ohne gedrückten Taster ändert man dessen Wert:

| OLED-Feld | Funktion | Werte |
| --- | --- | --- |
| Grundton | tonales Zentrum | C, C#, D, D#, E, F, F#, G, G#, A, A#, B |
| Skala | Skalentyp | off, root, pentatonic, major, minor, hrm minor, mel minor, altered, whole, wholeHalf |
| Stufe | Modus/Rotation innerhalb der Skala | abhängig von der Skala |
| `clr` | Skalenfarbe | 0 = weiß, 1 = Tonklassenfarben |
| `sng` | Songslot | 0 … 99 |
| `src` | Quelle der zusätzlich hervorgehobenen Noten | 0 = empfangene MIDI-/Saitennoten; 1 … 3 = aktive Noten der Sequencer-Instanz 1 … 3 |

**Skala `off`:** Sie besitzt laut Datenstruktur null Stufen. Die Stufenberechnung verwendet trotzdem Modulo mit dieser Anzahl. Diese Kombination ist daher als fehleranfällig einzustufen und sollte bis zur Korrektur nicht über die Stufenfunktion bedient werden.

### 7.2 Songwechsel über das OLED

Beim Drehen des Songfeldes geschieht vor jedem Wechsel:

1. ohne Shift: aktueller Songslot wird gespeichert,
2. mit Shift: Slot 0 wird gespeichert,
3. danach wird der neu gewählte Slot geladen.

Das Wechseln des Songfeldes ist daher **nicht nur Lesen**, sondern kann Daten überschreiben. Vor dem Experimentieren eine Sicherung der SD-Karte anlegen.

### 7.3 LED-Anzeige

- Die Skala wird über alle sichtbaren Bünde eingezeichnet.
- Tonklassen können farbig oder monochrom erscheinen.
- `src 0` überlagert aktive USB-MIDI-Noten:
  - Kanäle 1 … 6 werden jeweils einer Saite zugeordnet,
  - Kanal 15 hebt eine Tonklasse auf allen passenden Bünden hervor,
  - Kanal 16 hebt die exakte MIDI-Note hervor.
- `src 1 … 3` überlagert die aktuell ausgegebenen Tonklassen der jeweiligen Sequencer-Instanz.
- Die letzten drei LED-Positionen bilden zusätzlich eine Pattern-Anzeige für die drei Instanzen.

## 8. Generischer Sequencer

### 8.1 Aufbau

Es existieren drei Instanzen. Jede besitzt:

- sechs Patterns,
- sechs Saitenspuren,
- maximal 16 Steps je Spur,
- unabhängige Länge, Zeitteilung, Startversatz, Sync-/Patternsteuerung und MIDI-Kanal je Spur,
- pro Step: MIDI-Note/Skalenstufe, Repeat-Anzahl, Velocity und drei CC-Werte.

Die linke Transporttaste wählt Instanz 1 … 3. Die Pattern-Drehschalter 1 … 3 gehören den entsprechenden Instanzen.

### 8.2 Pattern-Drehschalter

- Stellungen 0 … 5 wählen Pattern 1 … 6 der betreffenden Instanz.
- Bei laufender Clock wird der Wechsel auf die nächste Viertelnote gelegt; bei gestoppter Clock erfolgt er unmittelbar.
- Mit Shift wird das gewählte Pattern nur als Edit-Pattern eingestellt, nicht als laufendes Pattern geplant.
- Stellungen 9 … 11 können die Instanz mit einer anderen Instanz synchronisieren. Die genaue physische Drehrichtung und sinnvolle Selbstsynchronisationsfälle müssen am Instrument geprüft werden.
- Bei Pattern-Schalter 2 und 3 ruft Stellung 6 String Setup auf.

Pattern-Schalter 1 hat zusätzlich eine Sonderrolle: Stellungen 6 … 11 wählen den Arpeggiator und dessen sechs Patterns; der Wechsel wird wie ein Patternwechsel quantisiert.

### 8.3 Spurparameter über Saiten-Encoder

Im Step-Edit-/Rastermodus wählt das OLED unter `enc` eine der folgenden Funktionen:

| Anzeige | Bedeutung | Bereich |
| --- | --- | ---: |
| `len` | Schleifenlänge der Spur | 1 … 16 Steps |
| `tmDv` | Tickabstand pro Step | `4`, `2`, `1`, `.75`, `/2`, `/3`, `/4`, `/6`, `/8`, `/12`, `/16`, `/24`, `/32`, `/48` |
| `offSt` | Startversatz im 16-Step-Raster | 0 … 16 |
| `sync` | Patternnummer, die eine Kanal-0-Steuerspur anfordern kann | 0 … 6; 0 = aus, 1 … 6 = Pattern 1 … 6 |
| `chn` | USB-MIDI-Kanal | 0 … 16; Kanal 0 ist interne Steuerung statt MIDI-Ausgabe |

Die Bezeichnungen der Zeitteilungen sind direkt aus dem Code übernommen. Intern beziehen sie sich auf eine 24-PPQN-Clock; beispielsweise entspricht `1` 96 Ticks, `/4` 24 Ticks und `/16` 6 Ticks.

### 8.4 Step setzen und bearbeiten

1. Griffbrett auf **Edit** stellen.
2. Auf einer Saite Bund 1 … 16 drücken. Dadurch wird der entsprechende Step umgeschaltet.
3. Mit gedrücktem Bund:
   - Display-Encoder drehen, um den unter `str` gewählten Parameter zu ändern, oder
   - Saiten-Encoder verwenden. Im Step-Modus sind die sechs Encoder den sechs Step-Parametern zugeordnet.
4. Shift + Bundkontakt löscht den Step.
5. Shift + Display-Encoder ändert den gewählten Parameter an allen 16 Steps der gerade gehaltenen Saite(n).

Mehrere gleichzeitig erkannte Bundkontakte auf einer Saite bewirken, dass Änderungen über Saiten-/Sammel-Encoder auf alle Steps der ausgewählten Saite(n) angewandt werden. Diese Mehrfachkontaktlogik ist hardwareabhängig.

### 8.5 Step-Parameter (`str`)

| Anzeige | Bedeutung | Bereich / Ausgabe |
| --- | --- | --- |
| `pStp` | MIDI-Note oder fortlaufende Skalenstufe | 0 … 127 |
| `rpt` | Trigger pro Step | 1 … 6; die Step-Länge bleibt unverändert |
| `vel` | Velocity | 0 … 50, für MIDI auf 0 … 127 skaliert |
| `c10` | interner Name; gesendet wird CC 2 | 0 … 99 |
| `c11` | interner Name; gesendet wird CC 3 | 0 … 99 |
| `c12` | interner Name; gesendet wird CC 4 | 0 … 99 |

`pStp` enthält jetzt Tonhöhe und Oktavlage gemeinsam; der frühere separate Parameter `oct` wurde durch `rpt` ersetzt. Bei `sclQ = 0` entspricht `pStp` direkt der ausgegebenen MIDI-Notennummer. Bei `sclQ = 1` wird der Wert als fortlaufende Stufe der gewählten und rotierten Skala ausgewertet: Werte oberhalb der ersten Skalenrunde führen in entsprechend höhere Oktaven. Das OLED zeigt die daraus berechnete Note mit Oktave an.

`rpt = 1` löst den Step einmal am Step-Anfang aus. Höhere Werte verteilen bis zu sechs Trigger gleichmäßig innerhalb derselben Step-Dauer; sie verlängern den Step nicht. Die zusätzlichen Trigger wiederholen die Note, Audiohüllkurve und gegebenenfalls Kickup, nicht jedoch die drei CC-Ausgaben des Steps.

Die OLED-Namen `c10`, `c11`, `c12` stimmen nicht mit den tatsächlich gesendeten Controller-Nummern 2, 3 und 4 überein.

Ist der Spurkanal `0`, werden die drei CC-Felder nicht gesendet, sondern steuern intern:

- erstes CC-Feld: Grundton (`Wert − 1`),
- zweites CC-Feld: Skala (`Wert − 1`),
- drittes CC-Feld: Skalenstufe (`Wert − 1`).

Ein CC-/Steuerwert von 0 führt keine Aktion aus. Bei Kanal 0 und aktivem `sync` kann ein gesetzter Step außerdem einen Patternwechsel anfordern.

### 8.6 Saitentaster-Funktionen (`btn`)

| Anzeige | Wirkung beim Tastendruck |
| --- | --- |
| `mute` | Spur stumm/aktiv umschalten |
| `rnd` | soll eine Spur randomisieren; im aktuellen Code ist die Zielanzahl jedoch immer 0, sodass die aktiven Steps der Spur gelöscht werden |
| `sclQ` | Skalenquantisierung für die Spur ein/aus |

Bei `sclQ = 0` ist `pStp` eine absolute MIDI-Note. Bei `sclQ = 1` ist es eine fortlaufende Stufe der aktuell ausgewählten, rotierten Skala.

### 8.7 Pattern kopieren

Beim Drücken des Display-Encoders merkt sich die Firmware die aktuell laufenden Patterns. Wird anschließend ein anderes Edit-Pattern gewählt und der Display-Encoder losgelassen, kopiert sie das zuvor laufende Pattern in das gewählte Edit-Pattern. Dieser Vorgang betrifft alle drei Instanzen, bei denen Edit- und zuvor aktives Pattern voneinander abweichen. Es gibt keine Bestätigungsabfrage.

## 9. Saiten-Arpeggiator

### 9.1 Aktivieren

1. Pattern-Schalter 1 auf Stellung 6 … 11 drehen; damit wird eines der sechs Arpeggiator-Patterns gewählt.
2. Linken Schalter der Dreifachgruppe einschalten, damit die Automatik läuft.
3. Im Spielmodus Saiten an gewünschten Bünden greifen.

Der Arpeggiator baut seine Folge dynamisch aus den aktuell gedrückten Saiten. Er sendet pro ausgelöstem Saitenschritt MIDI, triggert die Audiohüllkurve und – falls freigegeben – Kickup.

### 9.2 Globale Arpeggiatorfunktionen

Unter `str`:

| Anzeige | Reihenfolge |
| --- | --- |
| `simple` | konfigurierte/gedrückte Reihenfolge vorwärts |
| `back` | Reihenfolge rückwärts |
| `mirror` | vorwärts, dann rückwärts einschließlich der Randwerte |
| `rev mirror` | rückwärts, dann vorwärts einschließlich der Randwerte |

Unter `btn`:

- `mute`: Saitenspur umschalten,
- `randomise`: im aktuellen Code **ohne Wirkung**.

Unter `enc`:

| Anzeige | Funktion | Bereich |
| --- | --- | ---: |
| `steps` | Anzahl Steps der Saite in der Arpeggiofolge | 0 … 64 |
| `tmDv` | Dauer dieser Saite | `1`, `1.5`, `2`, `3`, `4`, `6`, `8`, `12`, `16`, `24`, `32`, `48` |
| `repeat` | Anzahl Trigger pro Step; die Step-Länge bleibt unverändert | 1 … 6 |
| `order` | feste Reihenfolge/Gruppe | 0 … 6 |
| `chn` | USB-MIDI-Kanal | 0 … 16 |

`order = 0` ordnet Saiten nach der Reihenfolge ihres Greifens ein. Gleiche positive `order`-Werte gruppieren Saiten; sie werden gemeinsam ausgelöst. `steps = 0` nimmt eine Saite aus der getakteten Folge. Eine solche Saite kann bei aktivem Arpeggiator weiterhin manuell triggern.

`repeat = 1` löst jeden Arpeggiator-Step einmal aus. Höhere Werte verteilen die Trigger gleichmäßig innerhalb der über `tmDv` gewählten Dauer, ohne den Step zu verlängern. Bei gruppierten Saiten werden auch die zusätzlichen Trigger für alle Saiten derselben positiven `order`-Gruppe ausgeführt. Der frühere Parameter `ser o par` ist entfallen; parallele Wiedergabe wird ausschließlich über solche `order`-Gruppen eingestellt.

## 10. Spielen, Griffbrettsensing und Aktoren

### 10.1 Vollständige Bunderkennung

Im Sensormodus `0` erkennt die Firmware pro Saite den höchsten gleichzeitig kontaktierten Bund. Im Spielmodus erzeugt ein neuer Kontakt:

- eine Audio-Hüllkurve, sofern keine Sequencer-/Arpeggiatorautomatik die manuelle Auslösung unterdrückt,
- eine USB-MIDI-Note mit Velocity 127,
- optional einen Kickup-Impuls,
- eine Meldung an den Audio-Controller über Tonhöhe und Greifzustand.

Die manuelle USB-MIDI-Note ist `Saitenstimmung + Bundnummer + 12`. Beim Wechsel oder Loslassen wird die vorherige Note der Saite beendet.

### 10.2 Vereinfachte Erkennung

Im Sensormodus `1` erkennt die Firmware nur, ob eine Saite irgendeinen Bund berührt. Da keine sichere Bundnummer vorliegt, werden die normalen MIDI-Notenereignisse für Griffpositionen unterdrückt. Der Modus ist über Shift + Kickup-Schalter erreichbar.

### 10.3 Saiten halten

Wird im Spielmodus bei aktivem Shift eine Saite gegriffen, setzt die Firmware für diese Saite `hold`. Nach Loslassen der Saite wird `hold` wieder gelöscht. Im generischen Sequencer kann eine gehaltene Saite ihre zuletzt bekannte Griffposition als MIDI-Note verwenden. Das ist ein momentaner, an Shift und aktuellen Kontakt gebundener Zustand, kein dauerhaft verriegeltes Hold.

### 10.4 Kickup

- Der rechte Schalter der Dreifachgruppe gibt Kickup frei.
- Manuelle Griffereignisse, Saitensequencer, Arpeggiator und eingehende USB-MIDI-Noten auf Kanälen 1 … 6 können Kickup auslösen.
- MIDI-Kanal 1 triggert intern Saite 5, Kanal 2 Saite 4, …, Kanal 6 Saite 0; die Notennummer wird dabei nicht ausgewertet.
- Gleichzeitig angeforderte Anschläge werden nacheinander abgearbeitet, um Stromspitzen zu reduzieren.

### 10.5 MulEBow

- Der mittlere Schalter der Dreifachgruppe schaltet MulEBow ein/aus.
- Bei eingeschaltetem MulEBow erzeugt der Audio-Controller nur für als gegriffen gemeldete Saiten ein Spulensignal in der gemeldeten Tonhöhe.
- Beim Loslassen wird das Signal der Saite abgeschaltet.
- Der globale `bowMode` ist im Code vorhanden, aber kein aktuelles Bedienelement sendet eine Änderung. Deshalb ist außer Ein/Aus kein bedienbarer MulEBow-Modus dokumentierbar.

## 11. Clock und Synchronisation

### 11.1 Interne Clock

- Tempo: 1 … 250 BPM, Standard 90 BPM.
- Auflösung: 24 PPQN.
- Start/Stop: mittlerer Transporttaster.
- Start, Clock und Stop werden als USB-MIDI-Realtime-Nachrichten ausgegeben.

### 11.2 Externe Clock

1. Shift aktivieren.
2. MulEBow-Schalter einschalten, um `extClk = 1` zu setzen.
3. Clock mit dem mittleren Transporttaster freigeben.
4. USB-MIDI Clock zuführen.

USB-MIDI Start setzt den internen Zähler zurück; USB-MIDI Stop setzt ihn zurück, löscht empfangene Notenanzeigen und sendet All Notes Off. Der externe Start/Stop-Handler setzt `clckOn` jedoch nicht selbst. Die lokale Transportfreigabe bleibt daher erforderlich.

## 12. MIDI-Funktionen

### 12.1 Ausgehend über USB-MIDI

- manuelle Griffbrettnoten auf dem pro Spur gewählten Kanal,
- Sequencer-Noten der Instanzen 2 und 3,
- Instanz 1 als Saitensequencer-/Arpeggiatorsteuerung,
- Sequencer-CC 2, 3 und 4,
- Fader-CC 3 … 6 auf Kanal 1,
- Joystick-CC 9/10 und Aftertouch auf Kanal 1,
- Poti-CC 7 auf Kanal 1,
- Program Change beim Laden der Songs 1 … 99: Programmnummer = Songslot − 1,
- interne Start/Clock/Stop-Nachrichten.

Der Hardware-MIDI-Port wird initialisiert, aber im Hauptloop nicht gelesen und die Sendefunktionen verwenden USB-MIDI. Eine aktuelle Bedienfunktion für DIN-/Hardware-MIDI lässt sich daher nicht bestätigen.

### 12.2 Eingehend über USB-MIDI

- Note On/Off wird für die LED-Anzeige gespeichert.
- Note On auf Kanal 1 … 6 triggert zusätzlich Audiohüllkurve und Kickup der zugeordneten Saite. Die Notenhöhe spielt dabei keine Rolle.
- Clock, Start und Stop steuern bei aktiviertem externem Clockmodus den Taktablauf.
- CC 10 wählt den Grundton modulo 12.
- CC 11 wählt Skala (`Wert modulo 16`, sofern gültig) und Skalenstufe (`Wert / 16`).
- CC 12 wählt die Skalenstufe modulo Anzahl der Skalenstufen.
- CC 13 steuert den LFO-Tonhöhenoffset.

Auch hier gilt: CC 11/12 zusammen mit Skala `off` kann wegen der Stufenanzahl 0 zu ungültigen Berechnungen führen.

## 13. Songs und SD-Karte

### 13.1 Gespeicherte Daten

Ein Song enthält nach aktuellem Dateiformat:

- Grundton, Skala, Skalenstufe, Farbmodus, BPM und LED-Quelle,
- alle drei Sequencer-Instanzen mit sechs Patterns, Spurparametern, Steps, Stepwerten und Skalenquantisierung,
- Stimmung und Saitenpegel,
- alle sechs Arpeggiator-Patterns einschließlich globaler Funktionswahl und Saitenparameter.

Die Dateien heißen `SONG00.ECS` bis `SONG99.ECS`. Beim Schreiben wird zunächst eine temporäre Datei erstellt, wieder eingelesen und per CRC geprüft, bevor sie den eigentlichen Slot ersetzt.

Das aktuelle Songformat hat **Version 4**. Durch die neuen Sequencer- und Arpeggiator-Repeat-Parameter sind Dateien älterer Formatversionen nicht kompatibel; beim Laden greift die Firmware für solche Slots auf den Standard-Song zurück. Bestehende Songdateien deshalb vor dem Firmwarewechsel sichern und die Patterns im aktuellen Format neu speichern.

### 13.2 Speichertaster

Der eingebettete Taster nahe der Potis reagiert beim Drücken:

| Display-Taster | Shift | Aktion |
| --- | --- | --- |
| nicht gedrückt | aus | ausgewählten Songslot laden |
| nicht gedrückt | ein | aktuellen Zustand in **Slot 0** speichern |
| gedrückt | aus | **Slot 0** laden |
| gedrückt | ein | Standard-Song im Arbeitsspeicher herstellen, noch nicht speichern |

Das Speichern des aktuell ausgewählten Slots erfolgt dagegen automatisch, wenn im OLED das Songfeld **ohne Shift** weitergedreht wird.

### 13.3 Fehlerfall und Standard-Song

Fehlt eine Songdatei, ist sie beschädigt, hat eine falsche Version/Größe/Prüfsumme oder enthält ungültige Werte, lädt die Firmware stattdessen den Standard-Song. Der Fehlerstatus ist nur über die Debug-Schnittstelle sichtbar, nicht über das OLED.

Der Standard-Song setzt unter anderem 90 BPM, C-Dur, farbige Skala, Sequencerlänge 16, Zeitteilung `/16`, leere Steps, `pStp = 36`, `rpt = 1` und unverstummte Arpeggiatorspuren mit `steps = 1` und `repeat = 1`.

## 14. OLED- und LED-Anzeigen lesen

- Das OLED zeigt jeweils nur die kontextabhängigen Parameter; eine permanente Statuszeile für Clock, Kickup, MulEBow oder externe Clock existiert nicht.
- Ein **gefüllter** abgerundeter Rahmen markiert in Sequencer/Arpeggiator die aktuell veränderbare Zeile; ein **leerer** Rahmen markiert die Zeile, während der Display-Taster zur Funktionsauswahl gedrückt ist.
- Im Step-Edit zeigt die rechte OLED-Hälfte Tonname/Oktave, Repeat-Anzahl, Velocity, drei CC-Werte und `sclQ` des zuletzt ausgewählten Steps.
- Im Sequencerraster markieren schwache Farben das Raster, Tonfarben gesetzte Steps, Grau Kanal 0, gedämpfte Farben stummgeschaltete Spuren und eine helle Überlagerung die aktuelle Cursorposition.
- Die LED-Anzeige blendet abklingend aus, statt jeden Pixel sofort hart abzuschalten.

## 15. Bekannte derzeitige Grenzen

Folgende Punkte sind direkt aus dem aktiven Code erkennbar und sollten bei der Bedienung berücksichtigt werden:

1. String-Arpeggiator-Modus 1 als eigener `opMode` zeichnet derzeit weder OLED noch LEDs; praktisch wird der Arpeggiator über Pattern-Schalter 1 innerhalb von Sequencer-Instanz 1 bedient.
2. Arpeggiator-`randomise` ist nicht implementiert.
3. Generisches `rnd` löscht nach aktueller Implementierung die Spur, statt ein Zufallsmuster zu erzeugen.
4. Die Skala `off` ist mit Step-/Stufenoperationen nicht robust kombinierbar.
5. Die drei Pattern-Drehschalter teilen sich Wertebereiche mit Sonderfunktionen (Arpeggiator, Instanzsync, String Setup). Vor Live-Betrieb die physischen Rastpositionen markieren.
6. Songwechsel und Patternkopieren können ohne Bestätigung Daten überschreiben.
7. Die Firmware initialisiert die SD-Karte vor weiteren Hauptcontroller-Initialisierungen und beendet `setup()` bei Fehlschlag vorzeitig. Ohne funktionsfähige SD-Karte ist daher kein normaler Betrieb zu erwarten.
8. Die physische Saitenreihenfolge, Steckerbelegung und Reglerbeschriftung müssen am konkreten Aufbau verifiziert werden.

## 16. Empfohlener erster Funktionstest

1. Aktorversorgung zunächst ausgeschaltet lassen; Audiopegel niedrig einstellen.
2. SD-Karte einsetzen und Instrument einschalten. Prüfen, ob OLED und LED-Griffbrett reagieren.
3. String Setup über Pattern-Schalter 2 oder 3, Stellung 6, öffnen; Saitenstimmung und Pegel kontrollieren.
4. In die Skalen-/Spielansicht wechseln und Grundton, Skala und LED-Quelle prüfen.
5. Jede Saite an mehreren Bünden greifen und USB-MIDI sowie LED-Reaktion beobachten.
6. Interne Clock starten, ein leeres Testpattern auswählen und einzelne Steps programmieren.
7. Erst danach Kickup mit strombegrenzter Aktorversorgung testen.
8. MulEBow zuletzt bei kurzer Einschaltdauer und Überwachung der Spulentemperatur testen.
9. Vor Songwechseln die SD-Karte sichern und die ungewöhnlichen Speicher-/Ladekombinationen aus Abschnitt 13.2 beachten.

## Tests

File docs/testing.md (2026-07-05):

# ElektroCaster testing guide

This guide lists manual and lightweight checks to run before and after refactors. Most functional tests require the physical ElektroCaster hardware.

## General pre-refactor checklist

1. Confirm the intended board(s): HID, CTL, Audio, or documentation only.
2. Record the current branch and `git status`.
3. Identify whether the change touches protected areas:
   - pin mappings,
   - serial protocols,
   - Audio Library routing or `AudioConnection`s,
   - fretboard scanning/debounce,
   - clock timing,
   - Kickup timing.
4. If protected behavior is touched, define an explicit hardware test plan before changing code.
5. Prefer one subsystem per pull request.

## Documentation-only checks

Can run without hardware:

- Verify changed file list contains only intended documentation files.
- Search for accidental firmware edits.
- Run `git diff --stat` and inspect `git diff`.
- Check Markdown readability manually.

## HID input test

Hardware required: HID board connected to CTL board or serial monitor instrumentation.

Purpose: verify controls still decode correctly.

Procedure:

1. Power the system in a safe state with actuators disabled if possible.
2. Move each analog control across its range.
3. Toggle each digital switch/button.
4. Rotate each encoder clockwise and counter-clockwise.
5. Rotate each 12-position rotary switch through all positions.
6. Observe decoded values on CTL debug output or display.

Expected results:

- Digital values change once per switch transition.
- Analog values change smoothly and remain in the expected `0..200` transmitted range.
- Encoder deltas have correct sign and no stuck values.
- Rotary switch states map to stable positions, likely `0..11`.

## Fretboard scan test

Hardware required: CTL board connected to the fretboard/string contact matrix.

Purpose: verify string/fret contact scanning, debouncing, and press/release behavior.

Procedure:

1. Enable a debug display or serial output for `strPrs`, `frtPrs`, and string index if available.
2. Press and release each string at several frets including low, middle, and high positions.
3. Test open-string release behavior.
4. Test fast repeated presses on the same string.
5. Test multiple simultaneous string presses.

Expected results:

- Pressed fret maps to the expected string and fret number.
- Release returns to zero state.
- No excessive double triggers.
- Behavior is unchanged before and after a refactor.

## LED fretboard test

Hardware required: CTL board and LED fretboard.

Purpose: verify LED mapping, colors, brightness, and frame update behavior.

Procedure:

1. Run a known LED mode, such as scale or grid display.
2. Verify all 150 LEDs can light.
3. Verify each string/fret coordinate maps to the expected physical LED.
4. Check brightness and color compensation visually.
5. Observe whether LED updates interfere with controls, clock, or audio.

Expected results:

- No missing or misaddressed LEDs.
- No unexpected color channel swaps.
- No visible stalls after documentation-only or behavior-neutral changes.

## Kickup test

Hardware required: CTL board, Kickup driver hardware, and safe test conditions.

Safety note: Kickup uses solenoids and can draw significant current. Use current limiting, dummy loads, or reduced power when appropriate.

Purpose: verify Kickup pulse timing and cue sequencing.

Procedure:

1. Disable or physically isolate strings if mechanical motion is unsafe.
2. Trigger each string individually.
3. Trigger multiple strings at once.
4. Use a logic analyzer or oscilloscope on Kickup pins if available.
5. Confirm pulse duration and inter-string cue spacing against documented values.

Expected results:

- Each selected string receives one pulse.
- Multiple queued kicks are staggered rather than fired simultaneously.
- No stuck HIGH outputs.

## Audio control test

Hardware required: CTL and Audio boards connected through their serial link.

Purpose: verify CTL-to-Audio command decoding.

Procedure:

1. Send or trigger known CTL commands for envelope trigger, string press, volume, filter, envelope parameter, string gain, bow mode/on, and LFO where applicable.
2. Observe Audio board debug output or audible behavior.
3. Confirm no command causes serial lockup.
4. If using debug output, keep prints minimal to avoid changing timing.

Expected results:

- Audio board receives correct command IDs and payloads.
- Values remain within expected scaled ranges.
- No blocking parser hang when commands are sent normally.

## Audio I/O test

Hardware required: Audio board, audio codec, hexaphonic input source or test signal, output monitoring.

Purpose: verify audio routing and per-string processing.

Procedure:

1. Feed a known signal into each string input channel one at a time.
2. Confirm each string path reaches the expected output/summed output.
3. Test envelope, filter, and gain changes.
4. Monitor processor and memory usage if debug instrumentation is enabled.

Expected results:

- Each input channel maps to the expected string.
- Output routing matches pre-refactor behavior.
- No unexpected clipping, silence, channel swap, or instability.

## MulEBow test

Hardware required: Audio board, coil/MulEBow actuator path, and safe actuator power setup.

Purpose: verify electromagnetic sustain actuator control.

Procedure:

1. Start with safe actuator levels.
2. Toggle Bow on/off from CTL controls.
3. Press strings and observe whether coil oscillator amplitude responds only for active strings.
4. Test bow mode changes if currently implemented in the UI.
5. Monitor for overheating or unintended continuous drive.

Expected results:

- Bow off results in no coil drive.
- Bow on drives only expected active strings.
- No stuck actuator output after release or mode changes.

## Tests possible without hardware

- Documentation diff review.
- Markdown review.
- Static file inventory with `rg --files`.
- Git checks: `git status --short`, `git diff --stat`, `git diff --check`.
- Future host-side protocol encode/decode tests, if protocol code is extracted into testable modules.
- Future song serialization tests, if SD layout is abstracted into host-testable code.

## Tests requiring hardware

- HID input test.
- Fretboard scan test.
- LED fretboard test.
- Kickup test.
- CTL-to-Audio and Audio-to-CTL live protocol test.
- Audio I/O test.
- MulEBow test.

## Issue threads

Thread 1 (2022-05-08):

add a chromatic mode

fpiesik, 2022-05-08:
In chromatic mode the sequencer can be programmed freely without restrictions from the songs choosen scale and root note. In the chromatic mode the displayed scale has to be decoupled from the sequencers chromaticness.

fpiesik, 2022-05-29:
There's a variable genSq_sclQ for scale quantisation that is adjustable for each string via the string encoder buttons.

Closed 2022-05-29.

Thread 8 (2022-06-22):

Make scale selection sequencable

fpiesik, 2022-06-22:
And replace the current CC step programming hack

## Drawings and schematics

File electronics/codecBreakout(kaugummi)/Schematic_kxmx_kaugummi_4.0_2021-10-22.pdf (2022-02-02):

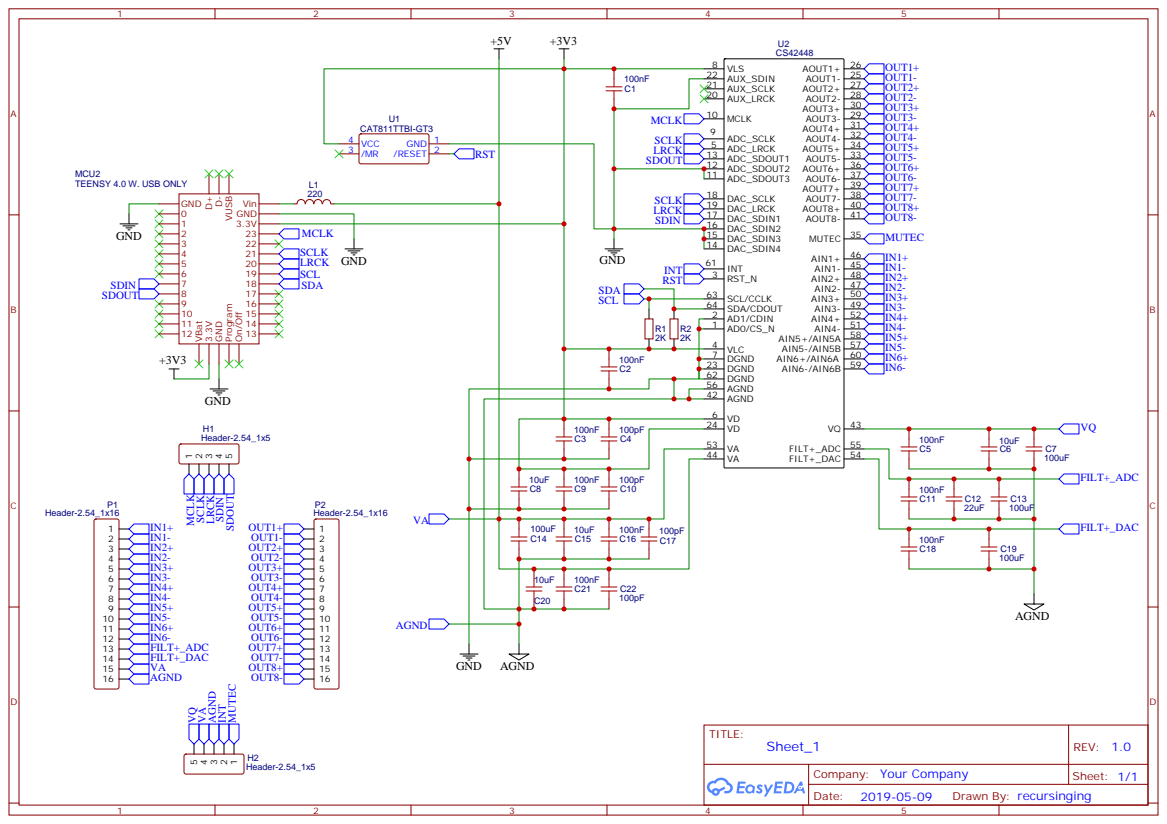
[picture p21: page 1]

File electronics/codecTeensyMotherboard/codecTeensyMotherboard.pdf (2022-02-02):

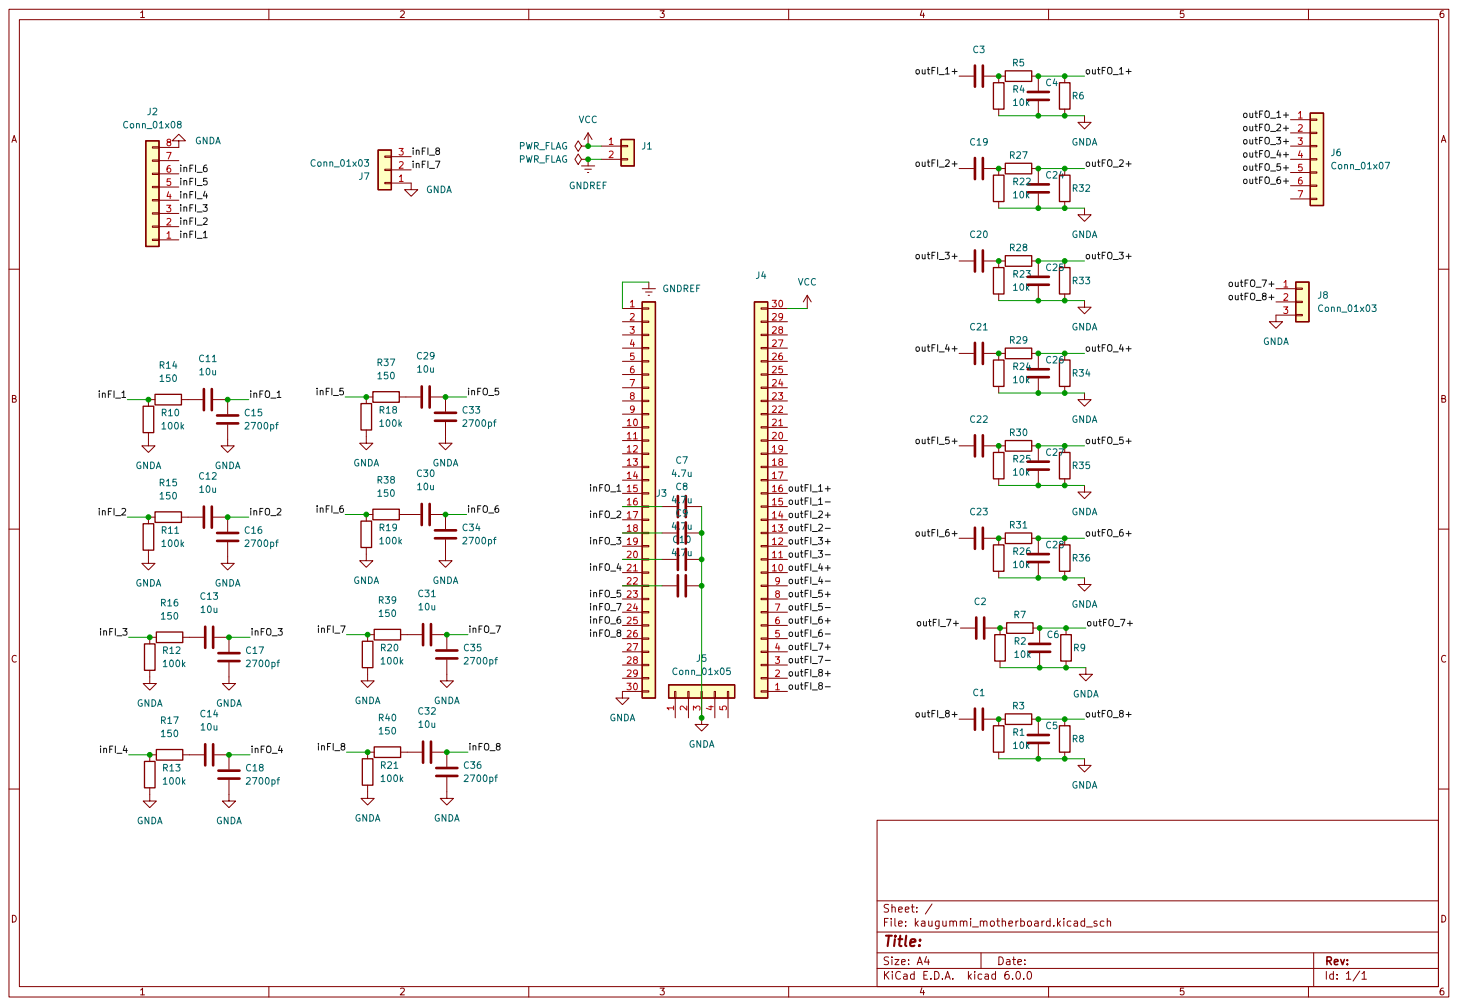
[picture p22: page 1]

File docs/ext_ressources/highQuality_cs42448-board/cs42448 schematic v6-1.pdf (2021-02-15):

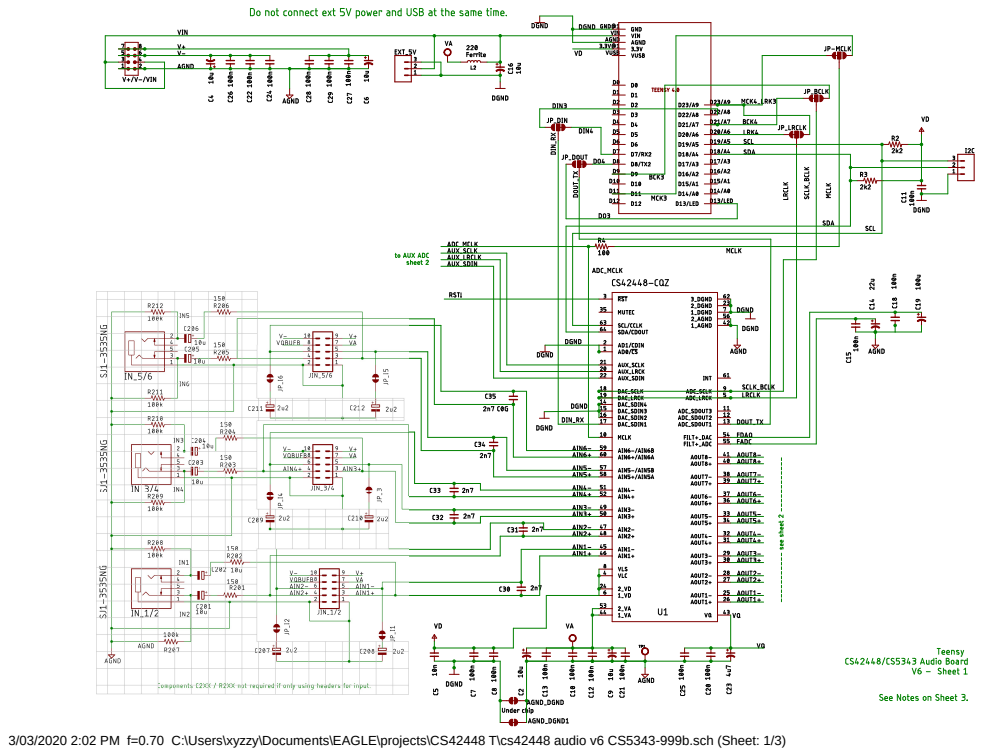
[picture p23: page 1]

3/03/2020 2:02 PM f=0.70 C:\Users\xyzzy\Documents\EAGLE\projects\CS42448 T\cs42448 audio v6 CS5343-999b.sch (Sheet: 1/3)

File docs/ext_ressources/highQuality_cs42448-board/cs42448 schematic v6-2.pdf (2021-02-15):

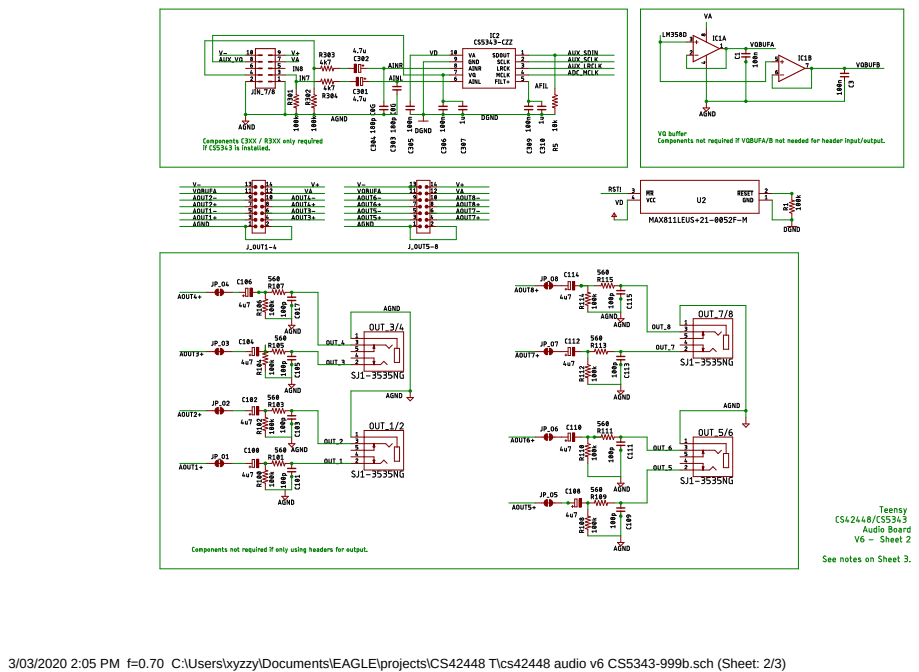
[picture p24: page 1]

3/03/2020 2:05 PM f=0.70 C:\Users\xyzzy\Documents\EAGLE\projects\CS42448 T\cs42448 audio v6 CS5343-999b.sch (Sheet: 2/3)

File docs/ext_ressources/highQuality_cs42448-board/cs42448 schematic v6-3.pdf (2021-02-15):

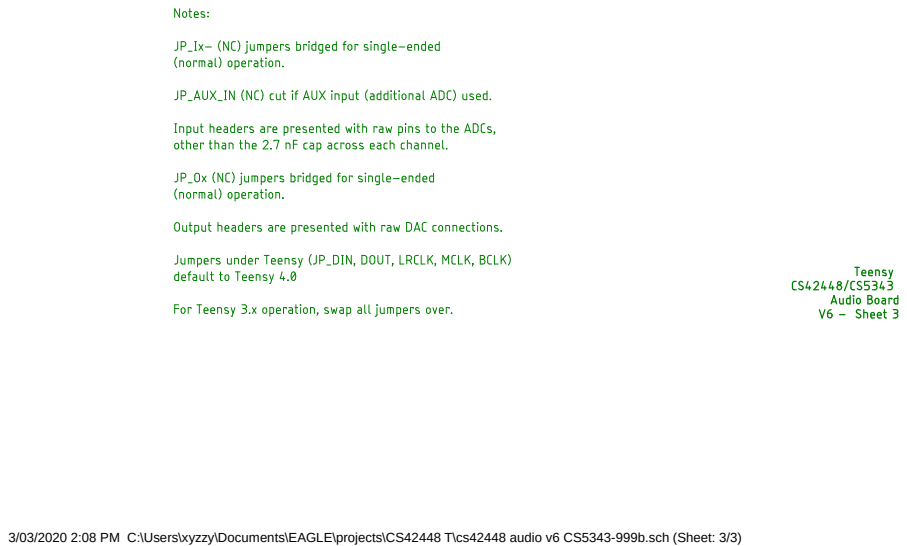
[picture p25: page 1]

3/03/2020 2:08 PM C:\Users\xyzzy\Documents\EAGLE\projects\CS42448 T\cs42448 audio v6 CS5343-999b.sch (Sheet: 3/3)

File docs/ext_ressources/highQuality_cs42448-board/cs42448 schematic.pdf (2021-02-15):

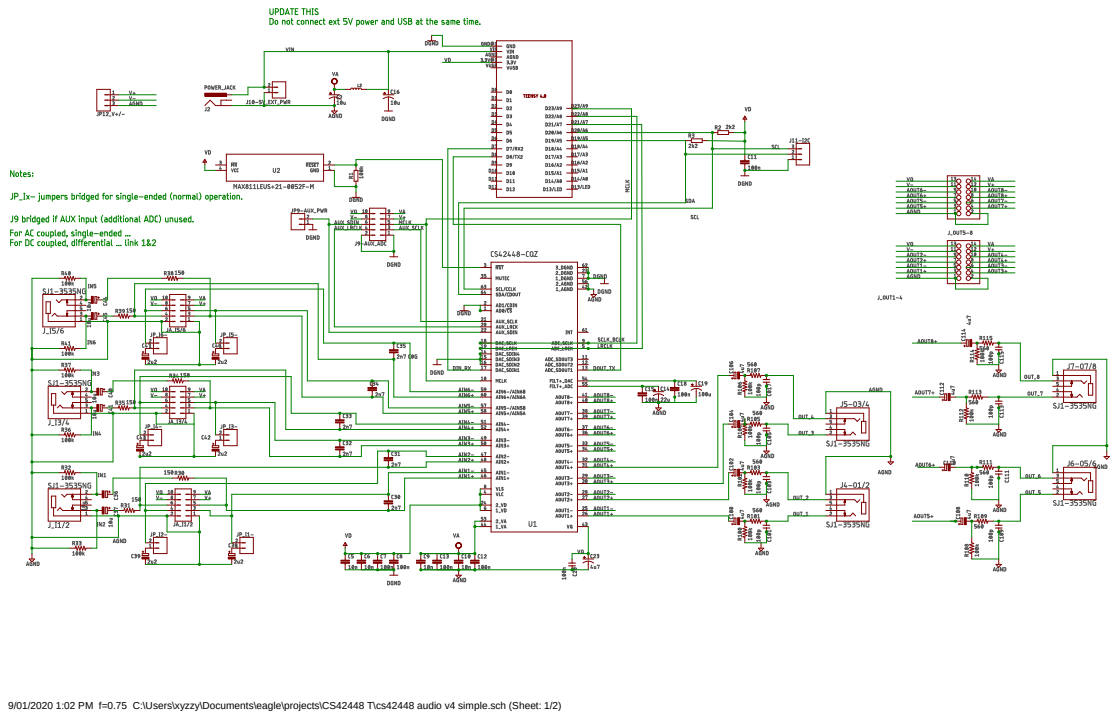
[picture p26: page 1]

9/01/2020 1:02 PM f=0.75 C:\Users\xyzzy\Documents\eagle\projects\CS42448 T\cs42448 audio v4 simple.sch (Sheet: 1/2)

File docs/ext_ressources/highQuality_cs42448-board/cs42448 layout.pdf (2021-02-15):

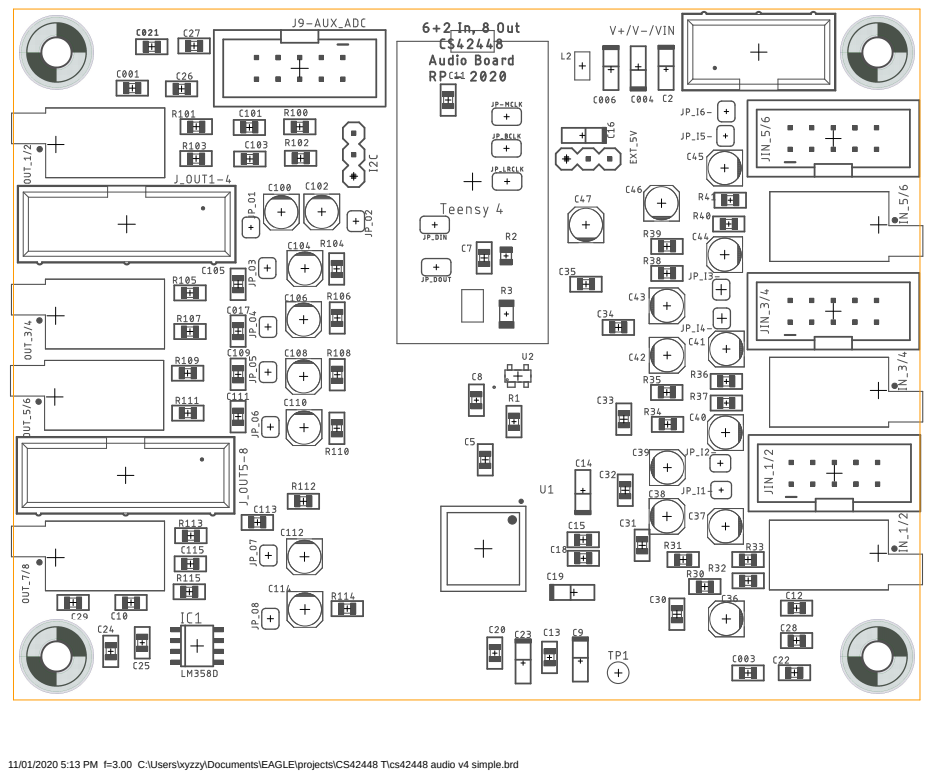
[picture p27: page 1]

11/01/2020 5:13 PM f=3.00 C:\Users\xyzzy\Documents\EAGLE\projects\CS42448 T\cs42448 audio v4 simple.brd

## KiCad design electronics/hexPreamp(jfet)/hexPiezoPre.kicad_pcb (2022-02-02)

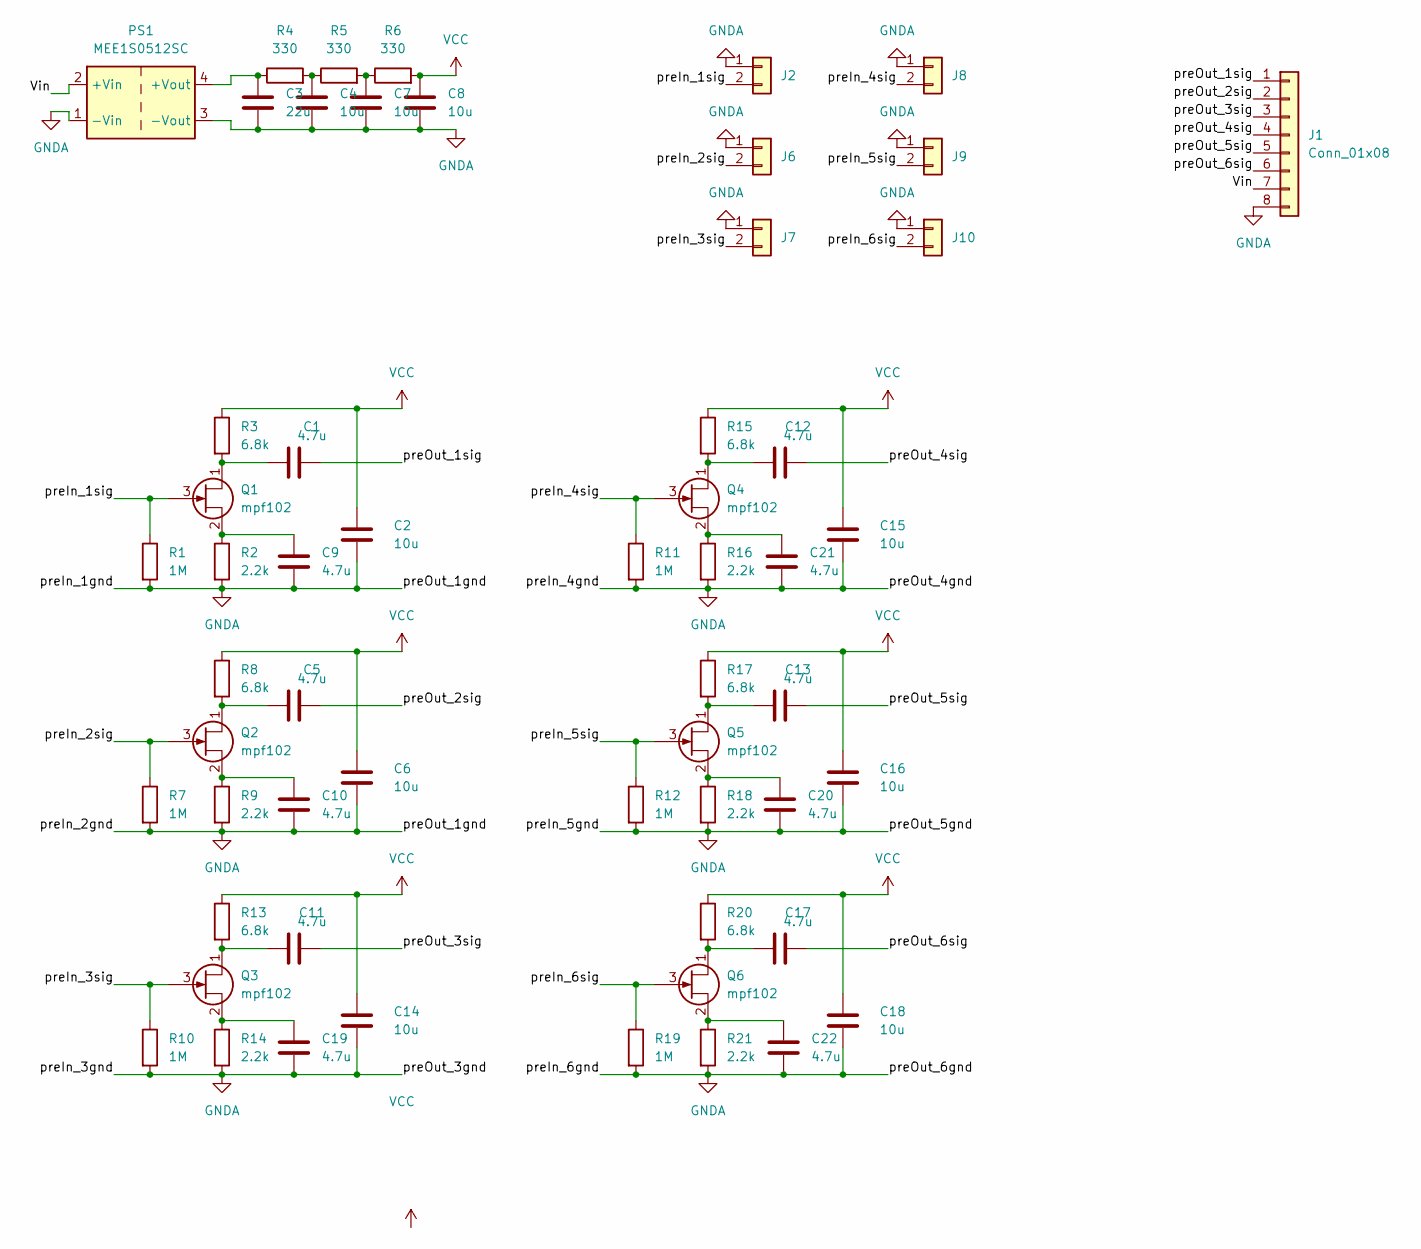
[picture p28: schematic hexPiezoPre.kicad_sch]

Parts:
C1, C5, C9, C10, C11, C12, C13, C17, C19, C20, C21, C22: 4.7u; C_0805_2012Metric_Pad1.18x1.45mm_HandSolder
C2, C4, C6, C7, C8, C14, C15, C16, C18: 10u; C_0805_2012Metric_Pad1.18x1.45mm_HandSolder
C3: 22u; C_0805_2012Metric_Pad1.18x1.45mm_HandSolder
J1: Conn_01x08; PinHeader_1x08_P2.54mm_Vertical
J2, J6, J7, J8, J9, J10: Conn_01x02; PinHeader_1x02_P2.54mm_Vertical
PS1: MEE1S0512SC; Converter_DCDC_Murata_MEE1SxxxxSC_THT
Q1, Q2, Q3, Q4, Q5, Q6: mpf102; TO-92
R1, R7, R10, R11, R12, R19: 1M; R_0805_2012Metric_Pad1.20x1.40mm_HandSolder
R2, R9, R14, R16, R18, R21: 2.2k; R_0805_2012Metric_Pad1.20x1.40mm_HandSolder
R3, R8, R13, R15, R17, R20: 6.8k; R_0805_2012Metric_Pad1.20x1.40mm_HandSolder
R4, R5, R6: 330; R_0805_2012Metric_Pad1.20x1.40mm_HandSolder

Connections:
/Vin: J1.7, PS1.2 (+Vin)
/preIn_1sig: J2.2, Q1.3 (G), R1.1
/preIn_2sig: J6.2, Q2.3 (G), R7.1
/preIn_3sig: J7.2, Q3.3 (G), R10.1
/preIn_4sig: J8.2, Q4.3 (G), R11.1
/preIn_5sig: J9.2, Q5.3 (G), R12.1
/preIn_6sig: J10.2, Q6.3 (G), R19.1
/preOut_1sig: C1.2, J1.1
/preOut_2sig: C5.2, J1.2
/preOut_3sig: C11.2, J1.3
/preOut_4sig: C12.2, J1.4
/preOut_5sig: C13.2, J1.5
/preOut_6sig: C17.2, J1.6
GNDA: C2.2, C3.2, C4.2, C6.2, C7.2, C8.2, C9.2, C10.2, C14.2, C15.2, C16.2, C18.2, C19.2, C20.2, C21.2, C22.2, J1.8, J2.1, J6.1, J7.1, J8.1, J9.1, J10.1, PS1.1 (-Vin), PS1.3 (-Vout), R1.2, R2.2, R7.2, R9.2, R10.2, R11.2, R12.2, R14.2, R16.2, R18.2, R19.2, R21.2
unnamed: C1.1, Q1.1 (D), R3.2
unnamed: C3.1, PS1.4 (+Vout), R4.1
unnamed: C4.1, R4.2, R5.1
unnamed: C5.1, Q2.1 (D), R8.2
unnamed: C7.1, R5.2, R6.1
unnamed: C9.1, Q1.2 (S), R2.1
unnamed: C10.1, Q2.2 (S), R9.1
unnamed: C11.1, Q3.1 (D), R13.2
unnamed: C12.1, Q4.1 (D), R15.2
unnamed: C13.1, Q5.1 (D), R17.2
unnamed: C17.1, Q6.1 (D), R20.2
unnamed: C19.1, Q3.2 (S), R14.1
unnamed: C20.1, Q5.2 (S), R18.1
unnamed: C21.1, Q4.2 (S), R16.1
unnamed: C22.1, Q6.2 (S), R21.1
VCC: C2.1, C6.1, C8.1, C14.1, C15.1, C16.1, C18.1, R3.1, R6.2, R8.1, R13.1, R15.1, R17.1, R20.1

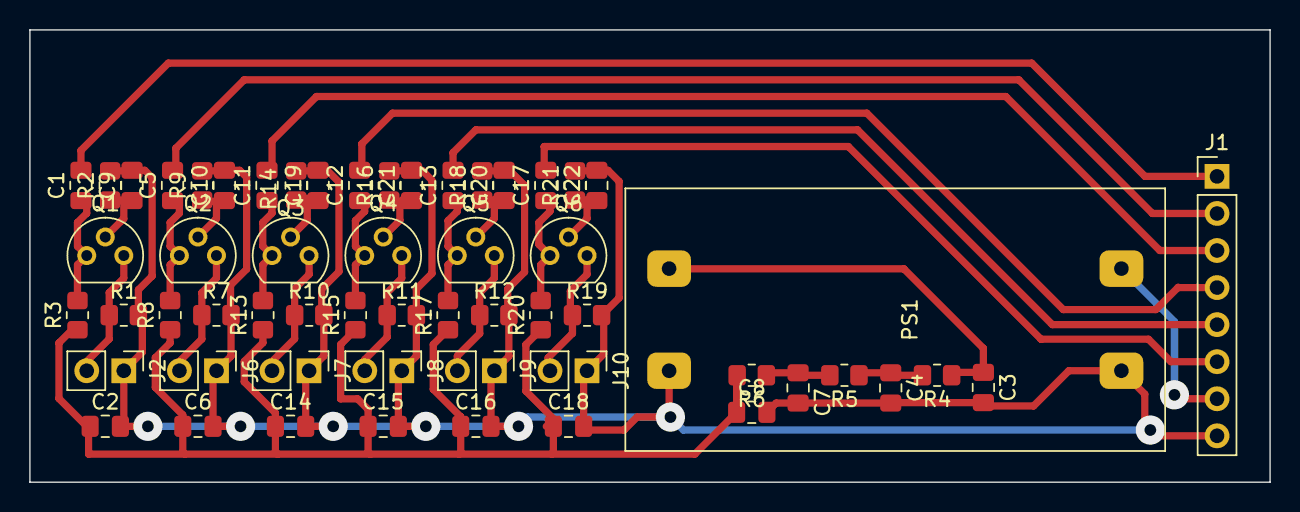
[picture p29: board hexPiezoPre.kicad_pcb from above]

Board: 2 copper layers, 85.0 x 31.0 mm, 57 parts (0 on the bottom side), 30 nets.

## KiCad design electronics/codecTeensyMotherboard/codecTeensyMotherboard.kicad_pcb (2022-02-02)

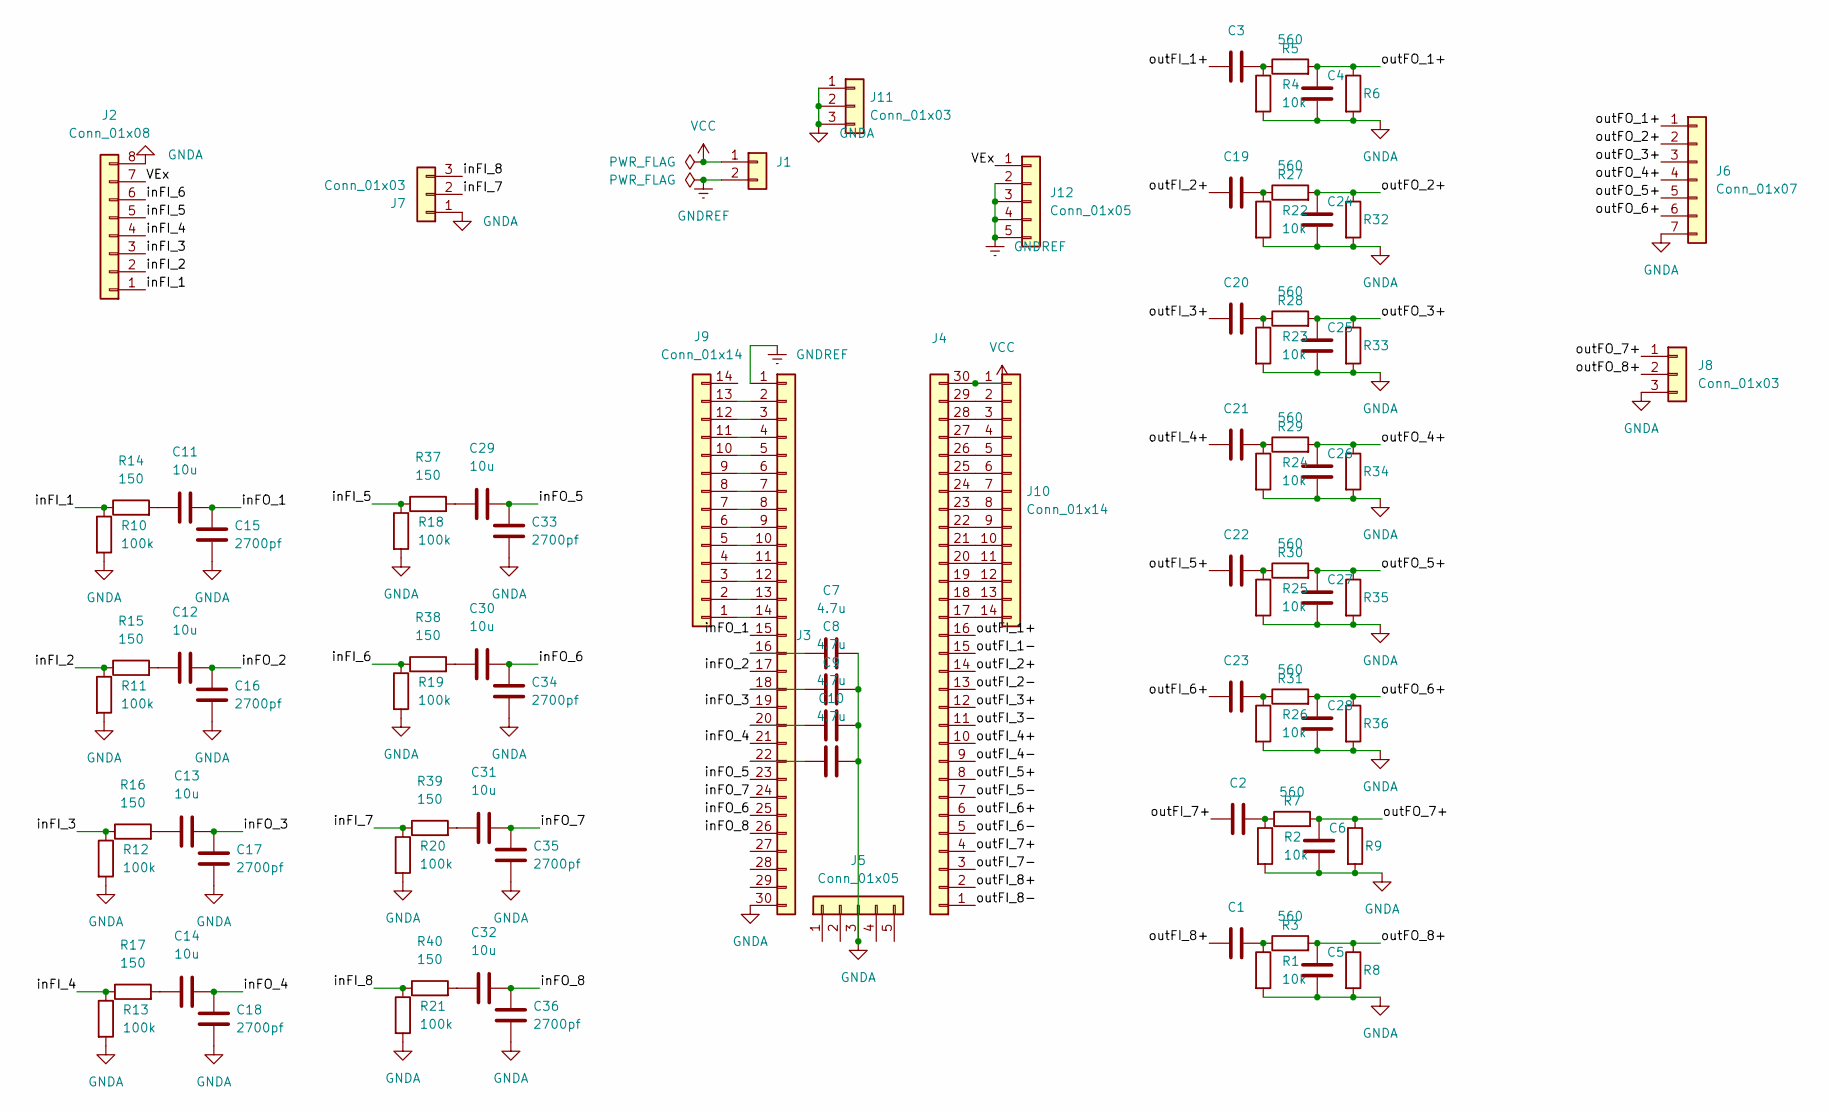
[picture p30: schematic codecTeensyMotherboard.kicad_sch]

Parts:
C1, C2, C3, C19, C20, C21, C22, C23: 3.3u; C_0805_2012Metric_Pad1.18x1.45mm_HandSolder
C4, C5, C6, C24, C25, C26, C27, C28: CAP; C_0805_2012Metric_Pad1.18x1.45mm_HandSolder
C7, C8, C9, C10: 4.7u; C_0805_2012Metric_Pad1.18x1.45mm_HandSolder
C11, C12, C13, C14, C29, C30, C31, C32: 10u; C_0805_2012Metric_Pad1.18x1.45mm_HandSolder
C15, C16, C17, C18, C33, C34, C35, C36: 2700pf; C_0805_2012Metric_Pad1.18x1.45mm_HandSolder
J1: Conn_01x02; PinHeader_1x02_P2.54mm_Vertical
J2: Conn_01x08; PinHeader_1x08_P2.54mm_Vertical
J3, J4: Conn_01x30; PinHeader_1x30_P2.54mm_Vertical
J5, J12: Conn_01x05; PinHeader_1x05_P2.54mm_Vertical
J6: Conn_01x07; PinHeader_1x07_P2.54mm_Vertical
J7, J8, J11: Conn_01x03; PinHeader_1x03_P2.54mm_Vertical
J9, J10: Conn_01x14; PinHeader_1x14_P2.54mm_Vertical
R1, R2, R4, R22, R23, R24, R25, R26: 10k; R_0805_2012Metric_Pad1.20x1.40mm_HandSolder
R3, R5, R7, R27, R28, R29, R30, R31: 560; R_0805_2012Metric_Pad1.20x1.40mm_HandSolder
R6, R8, R9, R32, R33, R34, R35, R36: R; R_0805_2012Metric_Pad1.20x1.40mm_HandSolder
R10, R11, R12, R13, R18, R19, R20, R21: 100k; R_0805_2012Metric_Pad1.20x1.40mm_HandSolder
R14, R15, R16, R17, R37, R38, R39, R40: 150; R_0805_2012Metric_Pad1.20x1.40mm_HandSolder

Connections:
/VEx: J2.7, J12.1
/inFI_1: J2.1, R10.1, R14.1
/inFI_2: J2.2, R11.1, R15.1
/inFI_3: J2.3, R12.1, R16.1
/inFI_4: J2.4, R13.1, R17.1
/inFI_5: J2.5, R18.1, R37.1
/inFI_6: J2.6, R19.1, R38.1
/inFI_7: J7.2, R20.1, R39.1
/inFI_8: J7.3, R21.1, R40.1
/inFO_1: C11.2, C15.2, J3.15
/inFO_2: C12.2, C16.2, J3.17
/inFO_3: C13.2, C17.2, J3.19
/inFO_4: C14.2, C18.2, J3.21
/inFO_5: C29.2, C33.2, J3.23
/inFO_6: C30.2, C34.2, J3.25
/inFO_7: C31.2, C35.2, J3.24
/inFO_8: C32.2, C36.2, J3.26
/outFI_1+: C3.1, J4.16
/outFI_1-: J4.15
/outFI_2+: C19.1, J4.14
/outFI_2-: J4.13
/outFI_3+: C20.1, J4.12
/outFI_3-: J4.11
/outFI_4+: C21.1, J4.10
/outFI_4-: J4.9
/outFI_5+: C22.1, J4.8
/outFI_5-: J4.7
/outFI_6+: C23.1, J4.6
/outFI_6-: J4.5
/outFI_7+: C2.1, J4.4
/outFI_7-: J4.3
/outFI_8+: C1.1, J4.2
/outFI_8-: J4.1
/outFO_1+: C4.1, J6.1, R5.2, R6.1
/outFO_2+: C24.1, J6.2, R27.2, R32.1
/outFO_3+: C25.1, J6.3, R28.2, R33.1
/outFO_4+: C26.1, J6.4, R29.2, R34.1
/outFO_5+: C27.1, J6.5, R30.2, R35.1
/outFO_6+: C28.1, J6.6, R31.2, R36.1
/outFO_7+: C6.1, J8.1, R7.2, R9.1
/outFO_8+: C5.1, J8.2, R3.2, R8.1
GNDA: C4.2, C5.2, C6.2, C7.2, C8.2, C9.2, C10.2, C15.1, C16.1, C17.1, C18.1, C24.2, C25.2, C26.2, C27.2, C28.2, C33.1, C34.1, C35.1, C36.1, J2.8, J3.30, J5.3, J6.7, J7.1, J8.3, J11.1, J11.2, J11.3, R1.2, R2.2, R4.2, R6.2, R8.2, R9.2, R10.2, R11.2, R12.2, R13.2, R18.2, R19.2, R20.2, R21.2, R22.2, R23.2, R24.2, R25.2, R26.2, R32.2, R33.2, R34.2, R35.2, R36.2
GNDREF: J1.2, J3.1, J12.2, J12.3, J12.4, J12.5
unnamed: C1.2, R1.1, R3.1
unnamed: C2.2, R2.1, R7.1
unnamed: C3.2, R4.1, R5.1
unnamed: C7.1, J3.16
unnamed: C8.1, J3.18
unnamed: C9.1, J3.20
unnamed: C10.1, J3.22
unnamed: C11.1, R14.2
unnamed: C12.1, R15.2
unnamed: C13.1, R16.2
unnamed: C14.1, R17.2
unnamed: C19.2, R22.1, R27.1
unnamed: C20.2, R23.1, R28.1
unnamed: C21.2, R24.1, R29.1
unnamed: C22.2, R25.1, R30.1
unnamed: C23.2, R26.1, R31.1
unnamed: C29.1, R37.2
unnamed: C30.1, R38.2
unnamed: C31.1, R39.2
unnamed: C32.1, R40.2
unnamed: J3.2, J9.13
unnamed: J3.3, J9.12
unnamed: J3.4, J9.11
unnamed: J3.5, J9.10
unnamed: J3.6, J9.9
unnamed: J3.7, J9.8
unnamed: J3.8, J9.7
unnamed: J3.9, J9.6
unnamed: J3.10, J9.5
unnamed: J3.11, J9.4
unnamed: J3.12, J9.3
unnamed: J3.13, J9.2
unnamed: J3.14, J9.1
unnamed: J4.29, J10.2
unnamed: J4.28, J10.3
unnamed: J4.27, J10.4
unnamed: J4.26, J10.5
unnamed: J4.25, J10.6
unnamed: J4.24, J10.7
unnamed: J4.23, J10.8
unnamed: J4.22, J10.9
unnamed: J4.21, J10.10
unnamed: J4.20, J10.11
unnamed: J4.19, J10.12
unnamed: J4.18, J10.13
unnamed: J4.17, J10.14
VCC: J1.1, J4.30, J10.1

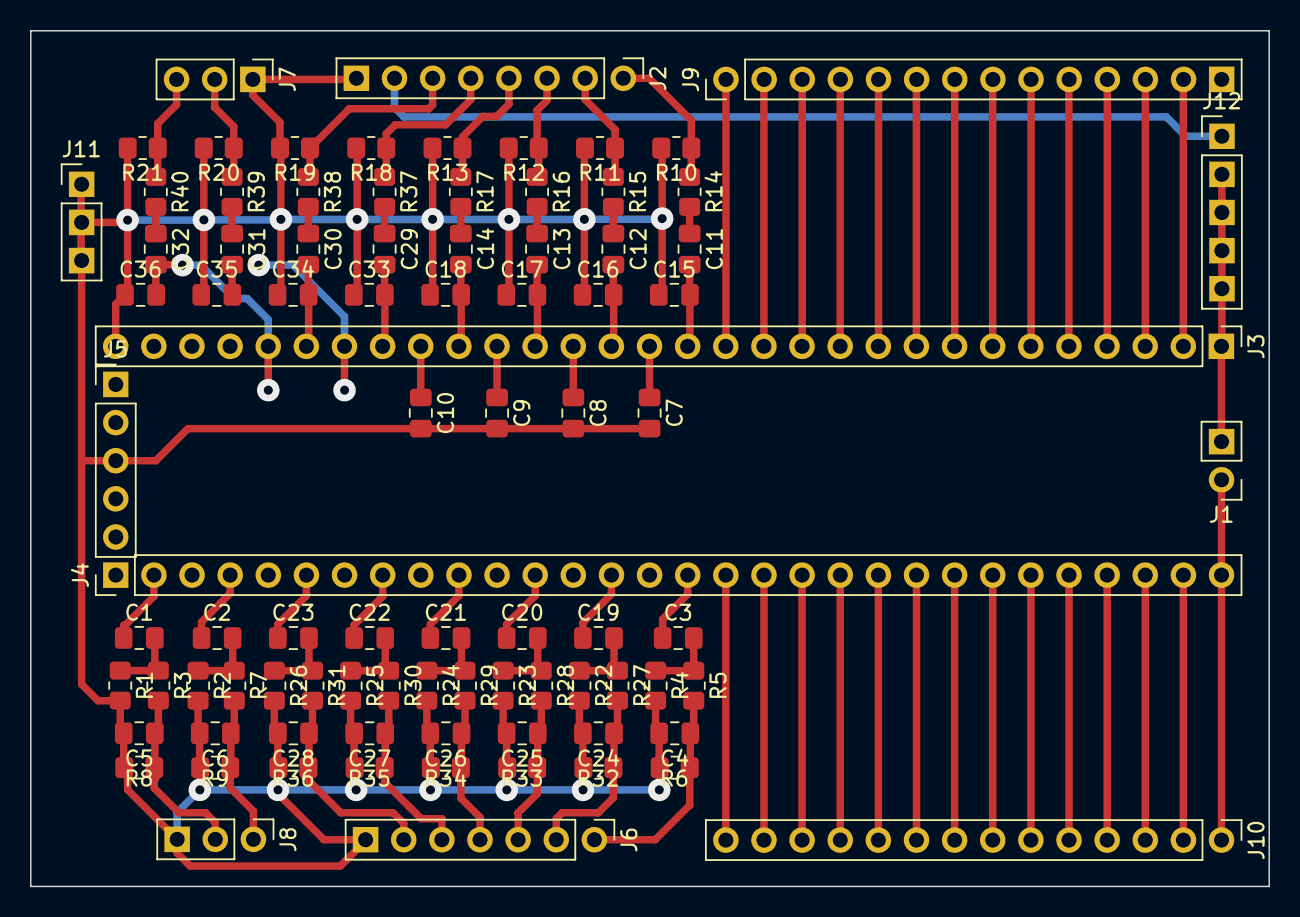
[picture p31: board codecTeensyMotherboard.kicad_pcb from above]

Board: 2 copper layers, 82.5 x 57.0 mm, 88 parts (0 on the bottom side), 82 nets.

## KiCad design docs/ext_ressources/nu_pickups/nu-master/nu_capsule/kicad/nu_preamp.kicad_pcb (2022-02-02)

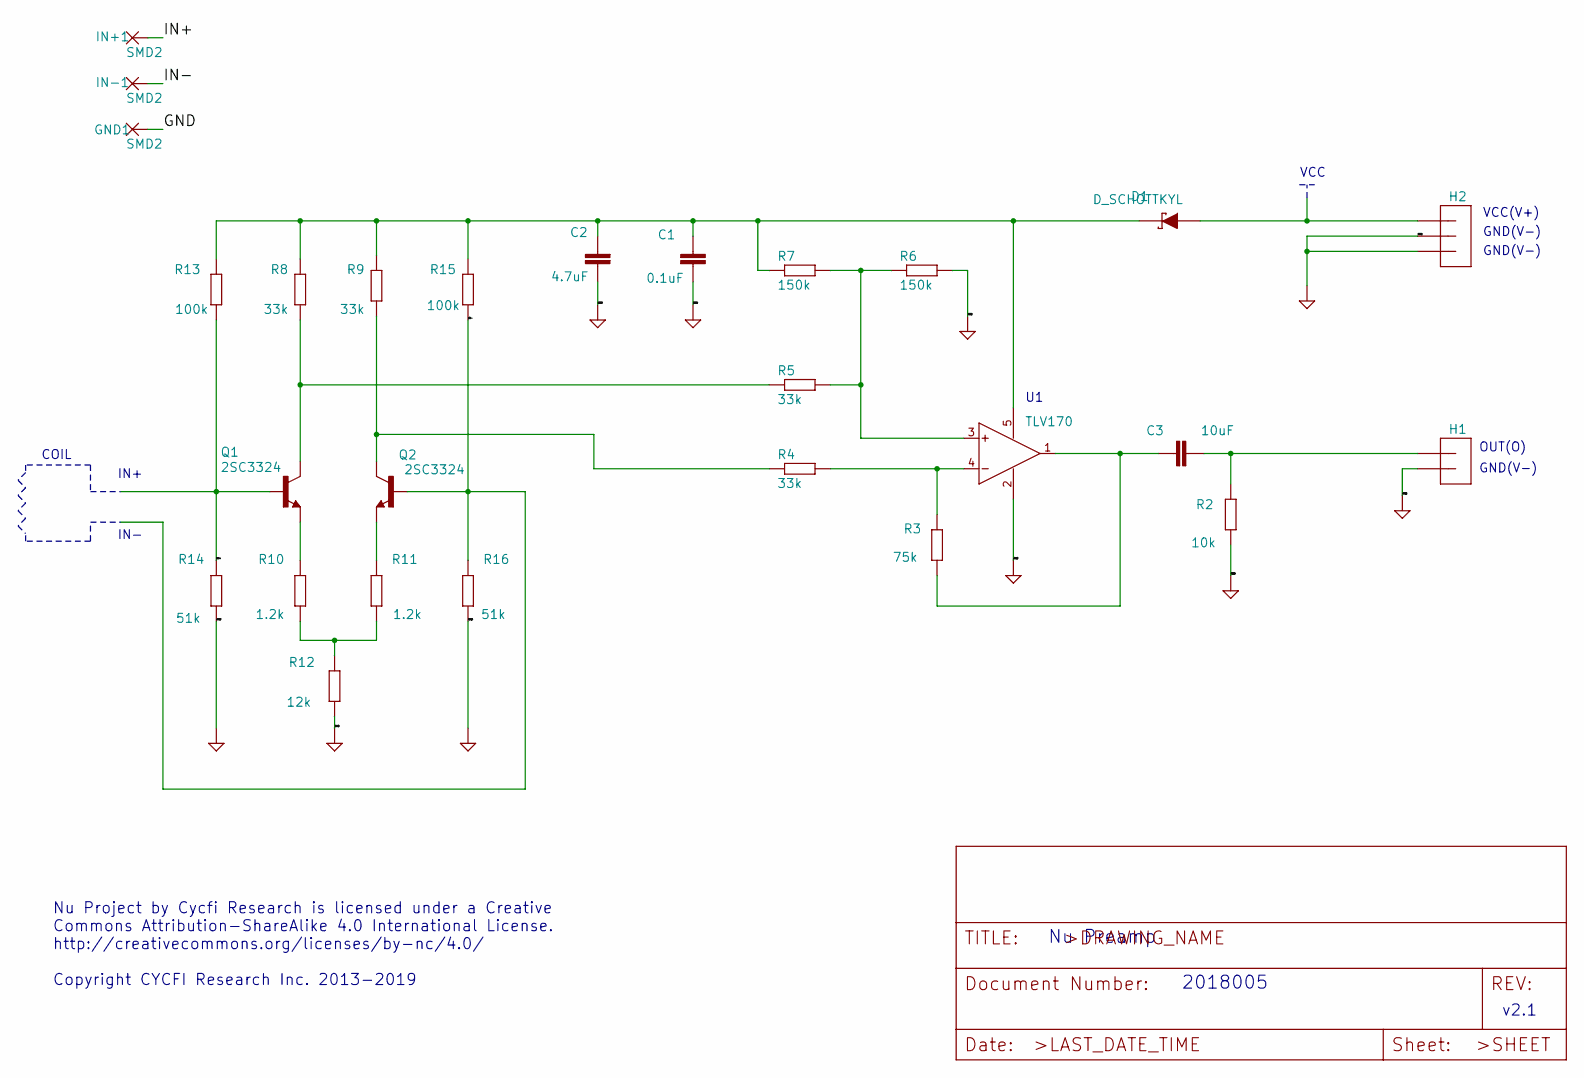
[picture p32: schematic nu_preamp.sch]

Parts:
C1: 0.1uF; C0402
C2: 4.7uF; C0603_NK
C3: 10uF; C0603_NK
D1: D_SCHOTTKYL; SOD-323
GND1: SMD2; SMD1,27-2,54
H1: 2P-2MM-TH-MALE; 2P-2MM-TH
H2: 3P-2MM-TH-MALE; 3P-2MM-TH
IN+1: SMD2; SMD1,27-2,54
IN-1: SMD2; SMD1,27-2,54
Q1, Q2: 2SC3324; SOT23
R2: 10k; R0402
R3: 75k; R0402
R4, R5, R8, R9: 33k; R0402
R6, R7: 150k; R0402
R10, R11: 1.2k; R0402
R12: 12k; R0402
R13, R15: 100k; R0402
R14, R16: 51k; R0402
U1: TLV170; SOT23-5

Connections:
/IN+: IN+1.1, Q1.1 (B), R13.1, R14.2
/IN-: IN-1.1, Q2.1 (B), R15.1, R16.2
GND: C1.2, C2.1, GND1.1, H1.P$2 (2), H2.P$2 (2), H2.P$3 (3), R2.1, R6.2, R12.1, R14.1, R16.1, U1.2 (V-)
unnamed: C1.1, C2.2, D1.2 (C), R7.1, R8.2, R9.2, R13.2, R15.2, U1.5 (V+)
unnamed: C3.1, R3.1, U1.1 (OUT)
unnamed: C3.2, H1.P$1 (1), R2.2
unnamed: D1.1 (A), H2.P$1 (1)
unnamed: Q1.2 (E), R10.2
unnamed: Q1.3 (C), R5.1, R8.1
unnamed: Q2.2 (E), R11.2
unnamed: Q2.3 (C), R4.1, R9.1
unnamed: R3.2, R4.2, U1.4 (IN-)
unnamed: R5.2, R6.1, R7.2, U1.3 (IN+)
unnamed: R10.1, R11.1, R12.2

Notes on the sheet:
Nu Preamp
v2.1
Nu Project by Cycfi Research is licensed under a Creative Commons Attribution-ShareAlike 4.0 International License. http://creativecommons.org/licenses/by-nc/4.0/ Copyright CYCFI Research Inc. 2013-2019
VCC
COIL
VCC(V+)
GND(V-)
OUT(O)
IN+
IN-
2018005

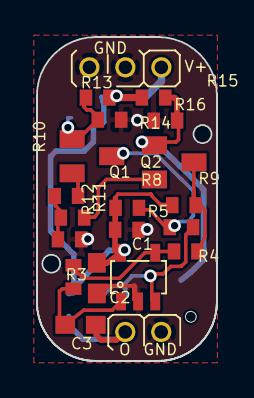
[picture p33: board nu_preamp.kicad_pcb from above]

Board: 2 copper layers, 10.0 x 18.0 mm, 28 parts (0 on the bottom side), 14 nets.

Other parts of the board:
@HOLE0: (no value)

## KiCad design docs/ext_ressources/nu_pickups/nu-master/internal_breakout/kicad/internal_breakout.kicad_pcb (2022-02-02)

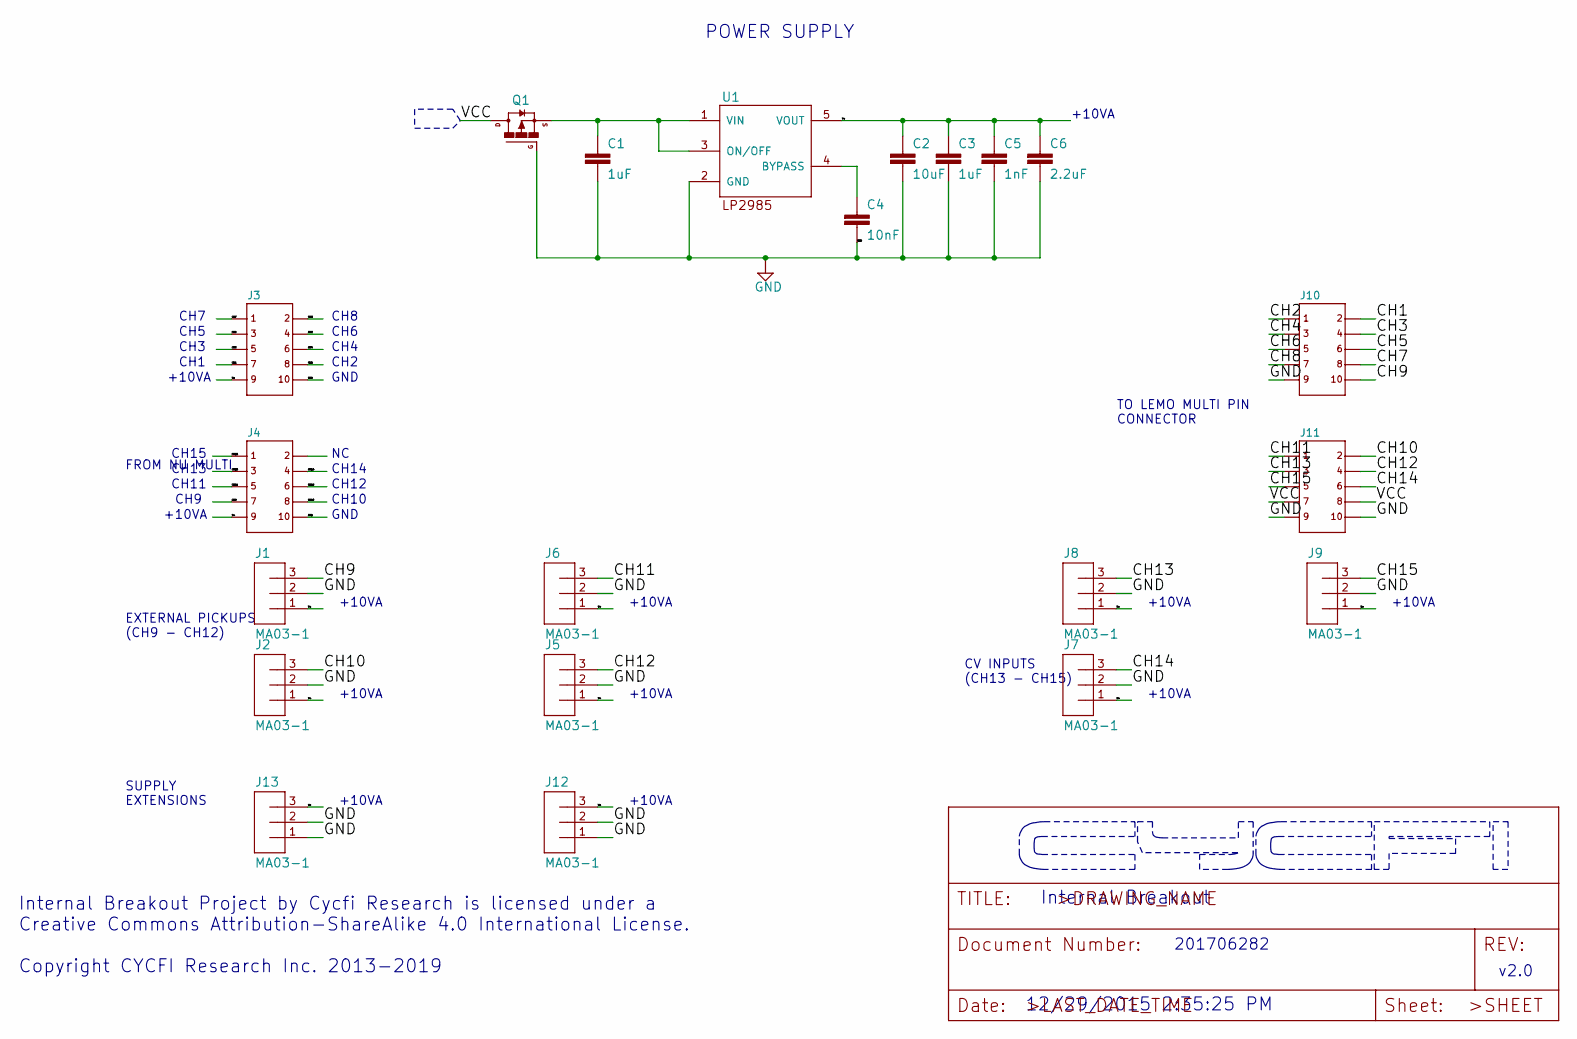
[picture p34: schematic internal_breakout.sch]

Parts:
C1, C3: 1uF; C0603
C2: 10uF; C0603
C4: 10nF; C0402
C5: 1nF; C0402
C6: 2.2uF; C0603
J1, J2, J5, J6, J7, J8, J9, J12, J13: MA03-1
J3, J4, J10, J11: 2X5
Q1: DMP3099L; SUPER-SOT3
U1: LP2985; SOT25

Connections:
/CH1: J3.7, J10.2
/CH2: J3.8, J10.1
/CH3: J3.5, J10.4
/CH4: J3.6, J10.3
/CH5: J3.3, J10.6
/CH6: J3.4, J10.5
/CH7: J3.1, J10.8
/CH8: J3.2, J10.7
/CH9: J1.3, J4.7, J10.10
/CH10: J2.3, J4.8, J11.2
/CH11: J4.5, J6.3, J11.1
/CH12: J4.6, J5.3, J11.4
/CH13: J4.3, J8.3, J11.3
/CH14: J4.4, J7.3, J11.6
/CH15: J4.1, J9.3, J11.5
/V+: C2.1, C3.1, C5.1, C6.1, J1.1, J2.1, J3.9, J4.9, J5.1, J6.1, J7.1, J8.1, J9.1, J12.3, J13.3, U1.5 (VOUT)
/VCC: J11.7, J11.8, Q1.3 (D)
GND: C1.2, C2.2, C3.2, C4.2, C5.2, C6.2, J1.2, J2.2, J3.10, J4.10, J5.2, J6.2, J7.2, J8.2, J9.2, J10.9, J11.9, J11.10, J12.1, J12.2, J13.1, J13.2, Q1.1 (G), U1.2 (GND)
unnamed: C1.1, Q1.2 (S), U1.1 (VIN), U1.3 (ON/OFF)
unnamed: C4.1, U1.4 (BYPASS)

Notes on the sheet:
POWER SUPPLY
Internal Breakout
v2.0
Internal Breakout Project by Cycfi Research is licensed under a Creative Commons Attribution-ShareAlike 4.0 International License. Copyright CYCFI Research Inc. 2013-2019
201706282
12/29/2015 2:35:25 PM
+10VA
CH1
CH3
CH5
CH7
GND
CH2
CH4
CH6
CH8
FROM NU MULTI
EXTERNAL PICKUPS (CH9 - CH12)
SUPPLY EXTENSIONS
CV INPUTS (CH13 - CH15)
TO LEMO MULTI PIN CONNECTOR
CH9
CH10
CH11
CH12
CH13
CH14
CH15

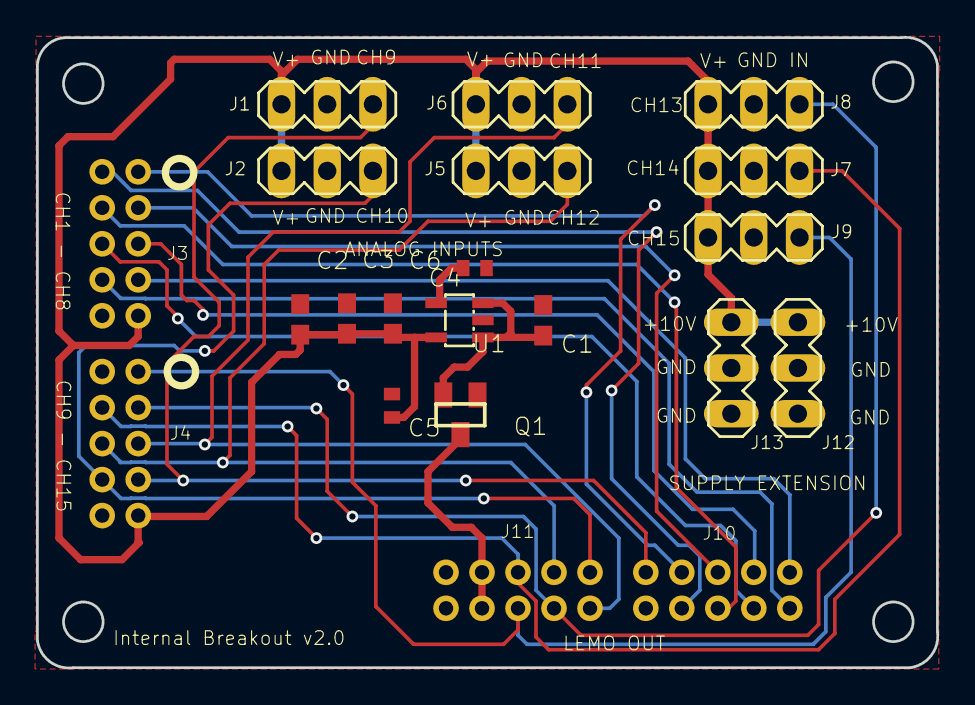
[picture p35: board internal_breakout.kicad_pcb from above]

Board: 2 copper layers, 50.0 x 35.0 mm, 21 parts (0 on the bottom side), 20 nets.

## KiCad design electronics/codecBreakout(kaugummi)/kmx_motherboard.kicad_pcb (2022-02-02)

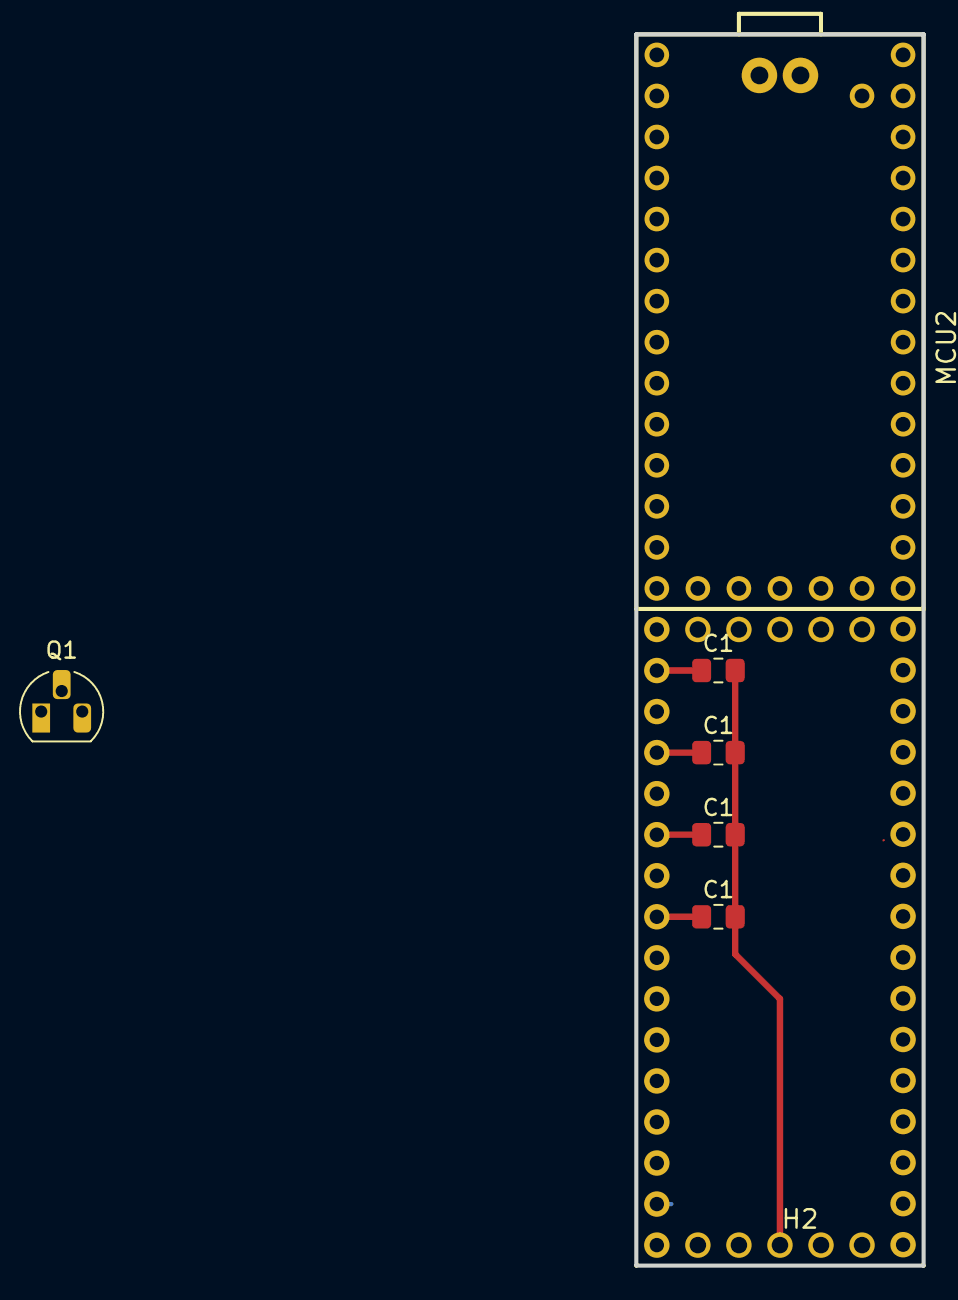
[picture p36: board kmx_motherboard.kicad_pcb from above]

Board: 2 copper layers, 17.8 x 76.2 mm, 10 parts (0 on the bottom side), 7 nets.

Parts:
C1, C1#2, C1#3, C1#4: 4.7u; C_0805_2012Metric_Pad1.18x1.45mm_HandSolder
H1, H2: Header-2.54_1x5; HDR-5X1_2.54
MCU2: TEENSY 4.0 W. USB ONLY
P1, P2: Header-2.54_1x16; HDR-16X1_2.54
Q1: MPF102; TO-92L_HandSolder

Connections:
+5V: H2.4, P1.15
GND: MCU2.GND0, MCU2.GND1, MCU2.GND2, P1.16
LRCK: H1.3, MCU2.20
MCLK: H1.1, MCU2.23
SCLK: H1.2, MCU2.21
SDIN: H1.4, MCU2.7
SDOUT: H1.5, MCU2.8

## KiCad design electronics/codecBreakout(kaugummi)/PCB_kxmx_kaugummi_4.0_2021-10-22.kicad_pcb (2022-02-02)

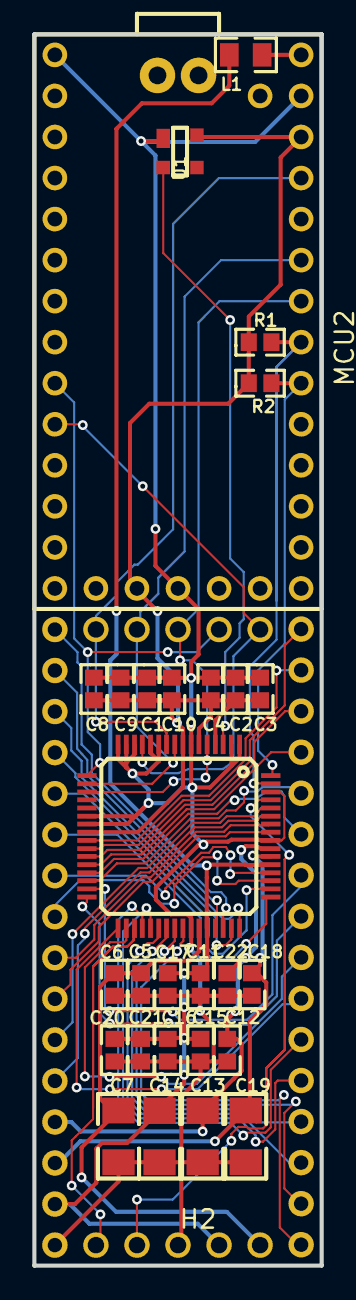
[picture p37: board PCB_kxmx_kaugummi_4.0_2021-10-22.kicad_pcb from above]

Board: 2 copper layers, 17.8 x 76.2 mm, 32 parts (0 on the bottom side), 45 nets.

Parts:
C1, C2, C3, C5, C9, C11, C16, C18, C21: 100nF; 0603
C4, C10, C17, C22: 100pF; 0603
C6, C8, C15, C20: 10uF; 0603
C7, C13, C14, C19: 100uF; 1206
C12: 22uF; 0603
H1, H2: Header-2.54_1x5; HDR-5X1/2.54
L1: 220Ω; 0805
MCU2: TEENSY 4.0 W. USB ONLY
P1, P2: Header-2.54_1x16; HDR-16X1/2.54
R1, R2: 2K; 0603
U1: CAT811TTBI-GT3; SOT-143
U2: CS42448; LQFP64-10X10

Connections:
+3V3: C1.2, C2.2, C3.2, C4.1, C8.2, C9.2, C10.1, MCU2.3, R1.1, R2.1, U1.4, U2.4, U2.6, U2.8, U2.24
+5V: C14.2, C15.2, C16.2, C17.1, C20.2, C21.2, C22.1, H2.4, L1.2, P1.15, U2.44, U2.53
FILT+_ADC: C11.2, C12.1, C13.2, P1.13, U2.55
FILT+_DAC: C18.2, C19.2, P1.14, U2.54
GND: C1.1, C2.1, C3.1, C4.2, C5.1, C6.1, C7.1, C8.1, C9.1, C10.2, C11.1, C12.2, C13.1, C14.1, C15.1, C16.1, C17.2, C18.1, C19.1, C20.1, C21.1, C22.2, H2.3, MCU2.GND0, MCU2.GND1, MCU2.GND2, P1.16, U1.1, U2.1, U2.2, U2.7, U2.11, U2.12, U2.14, U2.15, U2.16, U2.22, U2.23, U2.42, U2.56, U2.62
IN1+: P1.1, U2.46
IN1-: P1.2, U2.45
IN2+: P1.3, U2.48
IN2-: P1.4, U2.47
IN3+: P1.5, U2.50
IN3-: P1.6, U2.49
IN4+: P1.7, U2.52
IN4-: P1.8, U2.51
IN5+: P1.9, U2.58
IN5-: P1.10, U2.57
IN6+: P1.11, U2.60
IN6-: P1.12, U2.59
INT: H2.2, U2.61
L1_1: L1.1, MCU2.VIN
LRCK: H1.3, MCU2.20, U2.5, U2.19
MCLK: H1.1, MCU2.23, U2.10
MUTEC: H2.1, U2.35
OUT1+: P2.1, U2.26
OUT1-: P2.2, U2.25
OUT2+: P2.3, U2.27
OUT2-: P2.4, U2.28
OUT3+: P2.5, U2.30
OUT3-: P2.6, U2.29
OUT4+: P2.7, U2.31
OUT4-: P2.8, U2.32
OUT5+: P2.9, U2.34
OUT5-: P2.10, U2.33
OUT6+: P2.11, U2.36
OUT6-: P2.12, U2.37
OUT7+: P2.13, U2.39
OUT7-: P2.14, U2.38
OUT8+: P2.15, U2.40
OUT8-: P2.16, U2.41
RST: U1.2, U2.3
SCL: MCU2.19, R1.2, U2.63
SCLK: H1.2, MCU2.21, U2.9, U2.18
SDA: MCU2.18, R2.2, U2.64
SDIN: H1.4, MCU2.7, U2.17
SDOUT: H1.5, MCU2.8, U2.13
VQ: C5.2, C6.2, C7.2, H2.5, U2.43

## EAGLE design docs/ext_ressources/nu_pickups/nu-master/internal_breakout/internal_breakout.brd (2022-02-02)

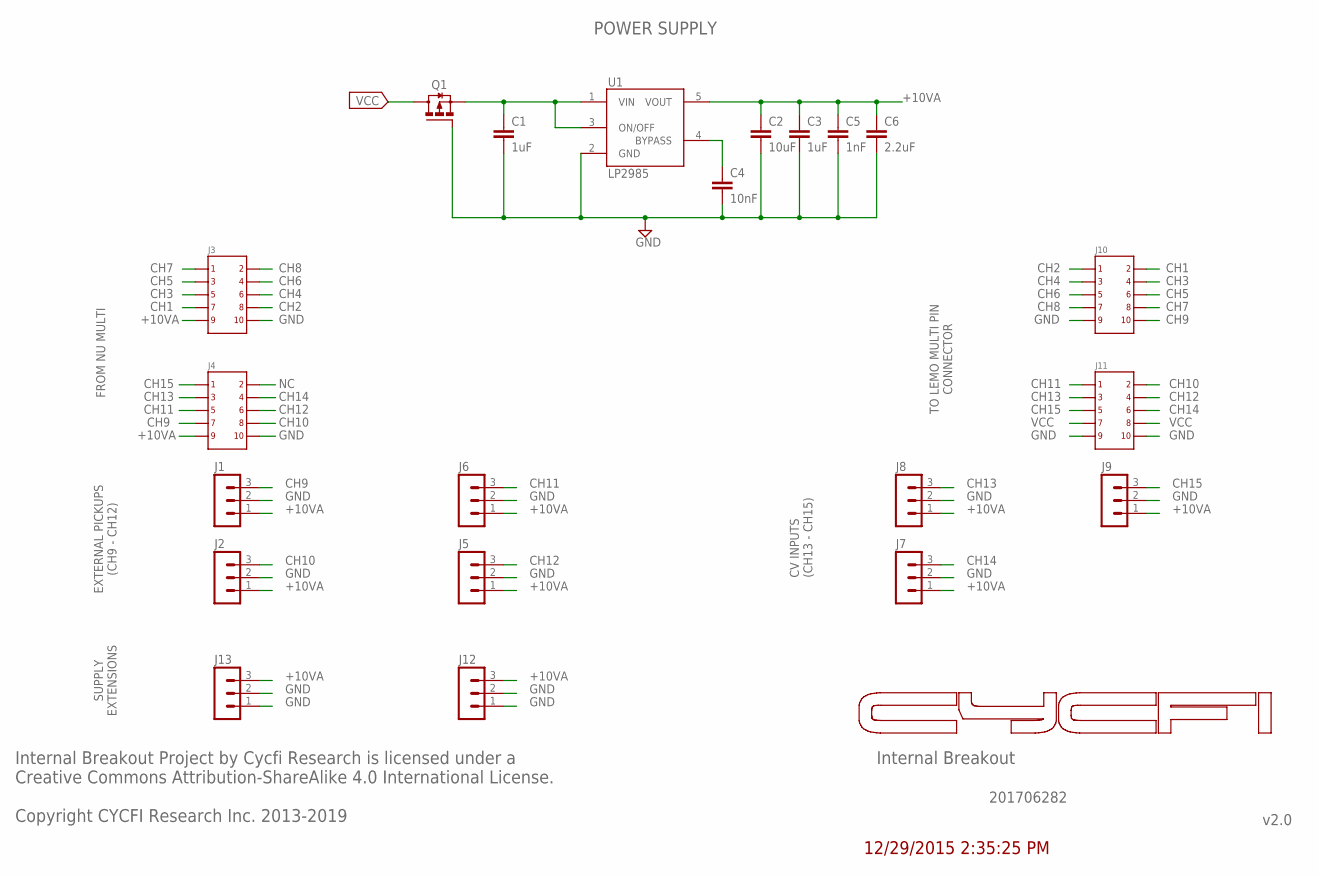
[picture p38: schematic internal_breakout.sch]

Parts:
C1, C3: 1uF; C0603
C2: 10uF; C0603
C4: 10nF; C0402
C5: 1nF; C0402
C6: 2.2uF; C0603
J1, J2, J5, J6, J7, J8, J9, J12, J13: MA03-1
J3, J4, J10, J11: 2X5
Q1: DMP3099L; SUPER-SOT3
U1: LP2985; SOT25

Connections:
BYPASS: C4.1, U1.4 (BYPASS)
CH1: J3.7, J10.2
CH2: J3.8, J10.1
CH3: J3.5, J10.4
CH4: J3.6, J10.3
CH5: J3.3, J10.6
CH6: J3.4, J10.5
CH7: J3.1, J10.8
CH8: J3.2, J10.7
CH9: J1.3, J4.7, J10.10
CH10: J2.3, J4.8, J11.2
CH11: J4.5, J6.3, J11.1
CH12: J4.6, J5.3, J11.4
CH13: J4.3, J8.3, J11.3
CH14: J4.4, J7.3, J11.6
CH15: J4.1, J9.3, J11.5
GND: C1.2, C2.2, C3.2, C4.2, C5.2, C6.2, J1.2, J2.2, J3.10, J4.10, J5.2, J6.2, J7.2, J8.2, J9.2, J10.9, J11.9, J11.10, J12.1, J12.2, J13.1, J13.2, Q1.1 (G), U1.2 (GND)
unnamed: C1.1, Q1.2 (S), U1.1 (VIN), U1.3 (ON/OFF)
NC: J4.2
V+: C2.1, C3.1, C5.1, C6.1, J1.1, J2.1, J3.9, J4.9, J5.1, J6.1, J7.1, J8.1, J9.1, J12.3, J13.3, U1.5 (VOUT)
VCC: J11.7, J11.8, Q1.3 (D)

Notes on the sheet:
POWER SUPPLY
Internal Breakout
v2.0
Internal Breakout Project by Cycfi Research is licensed under a Creative Commons Attribution-ShareAlike 4.0 International License. Copyright CYCFI Research Inc. 2013-2019
201706282
12/29/2015 2:35:25 PM
+10VA
CH1
CH3
CH5
CH7
GND
CH2
CH4
CH6
CH8
FROM NU MULTI
EXTERNAL PICKUPS (CH9 - CH12)
SUPPLY EXTENSIONS
CV INPUTS (CH13 - CH15)
TO LEMO MULTI PIN CONNECTOR
CH9
CH10
CH11
CH12
CH13
CH14
CH15

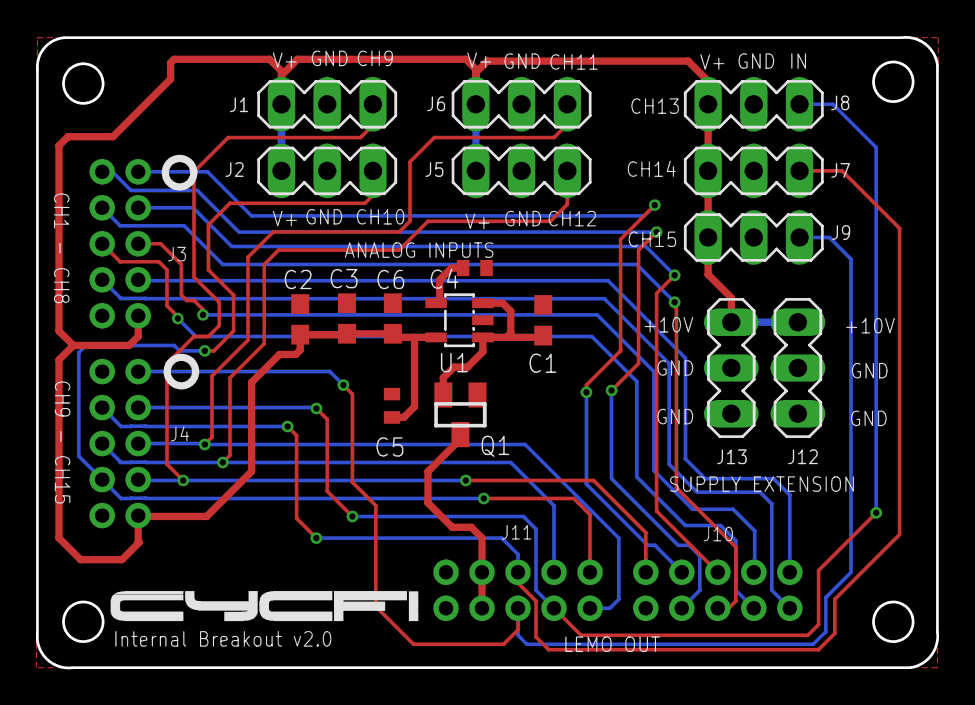
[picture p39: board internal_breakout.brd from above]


Board: 2 copper layers, 50.0 x 35.0 mm, 21 parts (4 on the bottom side), 20 nets.

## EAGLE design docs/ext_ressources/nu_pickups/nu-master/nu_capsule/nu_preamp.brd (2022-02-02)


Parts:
C1: 0.1uF; C0402
C2: 4.7uF; C0603_NK
C3: 10uF; C0603_NK
D1: D_SCHOTTKYL; SOD-323
GND: SMD2; SMD1,27-2,54
H1: 2P-2MM-TH-MALE; 2P-2MM-TH
H2: 3P-2MM-TH-MALE; 3P-2MM-TH
IN+: SMD2; SMD1,27-2,54
IN-: SMD2; SMD1,27-2,54
Q1, Q2: 2SC3324; SOT23
R2: 10k; R0402
R3: 75k; R0402
R4, R5, R8, R9: 33k; R0402
R6, R7: 150k; R0402
R10, R11: 1.2k; R0402
R12: 12k; R0402
R13, R15: 100k; R0402
R14, R16: 51k; R0402
U1: TLV170; SOT23-5

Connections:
GND: C1.2, C2.1, GND.1, H1.P$2 (2), H2.P$2 (2), H2.P$3 (3), R2.1, R6.2, R12.1, R14.1, R16.1, U1.2 (V-)
IN+: IN+.1, Q1.1 (B), R13.1, R14.2
IN-: IN-.1, Q2.1 (B), R15.1, R16.2
unnamed: C3.2, H1.P$1 (1), R2.2
unnamed: Q1.3 (C), R5.1, R8.1
unnamed: Q2.3 (C), R4.1, R9.1
unnamed: Q1.2 (E), R10.2
unnamed: Q2.2 (E), R11.2
unnamed: R10.1, R11.1, R12.2
unnamed: R5.2, R6.1, R7.2, U1.3 (IN+)
unnamed: R3.2, R4.2, U1.4 (IN-)
unnamed: C3.1, R3.1, U1.1 (OUT)
unnamed: D1.1 (A), H2.P$1 (1)
VCC1: C1.1, C2.2, D1.2 (C), R7.1, R8.2, R9.2, R13.2, R15.2, U1.5 (V+)

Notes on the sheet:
Nu Preamp
v2.1
Nu Project by Cycfi Research is licensed under a Creative Commons Attribution-ShareAlike 4.0 International License. http://creativecommons.org/licenses/by-nc/4.0/ Copyright CYCFI Research Inc. 2013-2019
VCC
COIL
VCC(V+)
GND(V-)
OUT(O)
IN+
IN-
2018005



Board: 2 copper layers, 10.0 x 18.0 mm, 27 parts (7 on the bottom side), 14 nets.

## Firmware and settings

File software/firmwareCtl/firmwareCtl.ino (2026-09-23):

#include "WS2812Serial.h"
#define USE_WS2812SERIAL
#include <FastLED.h>
#include <Wire.h>
#include <EEPROM.h>
#include "AsciiMassagePacker.h"
#include "AsciiMassageParser.h"
#include <SD.h>
#include <SPI.h>
#include "MIDI/MIDI.h"
#include "FretDetection.h"

AsciiMassagePacker msg_disp;  //to drive the display
AsciiMassagePacker msgOut_audio; //todo 
AsciiMassageParser msgIn_audio; //todo


//midi
  MIDI_CREATE_INSTANCE(HardwareSerial, Serial8, MIDI); 
  int mInst_chn=1;
  int mM8Row_chn=11;
  int mKick_chn=2;
  int mInst_anaXyCc[2]={9,10};
  int mInst_potCc[2]={7,8};
  int midi_faderCc[4]={3,4,5,6};
  int extNotes[17][128];
  int ccState[127];
  const int genSq_nCc=3;
  const int genSq_ccMp[genSq_nCc]={1,2,3};

//sdCard
File myFile;
const int chipSelect = BUILTIN_SDCARD;

//string defintions variables
  const int nStrings=6; //how many Strings
  const int nFrets=21;
  const int frtSplit=22; //22 is so high that it's disabled; point where the frets become pattern chooser
  int tuning[nStrings]={64,59,55,50,45,40};
  int defTuning[nStrings]={64,59,55,50,45,40};
  int strGain[nStrings];
  int defStrGain[nStrings]={45,40,35,30,25,20};
  int strGainMx=50;
  unsigned long lastFretRead[nStrings];
  unsigned int fretMaskT=50; //time until a next strPres on he same string is detected
  unsigned int strBncs=500; //number of same samples to trigger strPres
  unsigned int strBncsP=5000; //number of same samples to trigger strPres (Pattern section)
  float strP[nStrings];
  float lastStrP[nStrings];
  float strA[nStrings];
  float lastStrA[nStrings];
  bool strHold[nStrings]; //treat those strings as hold they were pressed
  int lastExStrPr[nStrings];
  int lastNZStrPrs[nStrings]; //last string press without releases (nz=non zero)
  

//led defintions and variables
  #define NUMPIXELS    150  //total number of leds
  const int nLedFrets=25; //how many led frets
  #include "HardwareConfig.h"
  //long sndLedTimer;
  //int sndLedInt=1000;
  float tnClrs[13][3];
  float fled_bright = 1; //brightness
  float fled_redC = 150;  //compensate the "filament filter"
  float fled_greenC= 255; //compensate the "filament filter"
  float fled_blueC = 255; //compensate the "filament filter"
  float fled_trgtC[nStrings][nLedFrets][3]; //color to reach
  float fled_actC[nStrings][nLedFrets][3];  //current color
  unsigned long fled_frameTimer; //timer for the led update
  unsigned int fled_frameInt=50;
  float hsbRGB[3]={0,0,0};
  CRGB frtPix[NUMPIXELS];
  CRGB lastFrtPix[NUMPIXELS];
  float trgtC[nStrings][nLedFrets][3];
  float actC[nStrings][nLedFrets][3];

//display
  unsigned long disp_frameTimer; //timer for the led update
  unsigned int disp_frameInt=100;
  unsigned long disp_lastDurationMicros=0; //measured display serialization time
  const unsigned long disp_clockGuardMicros=200; //keep this margin before the next internal clock tick
  
//hid
  float hidAVal[22];
  bool hidDVal[19]={0,0,0,0,0,0,0,0,0,0,0,0,0,1,1,1,1,1,1};
  byte hidRVal[3];
  long hidEVal[8];
  long hidEVal4[8];
  float lastHidAVal[22]={-1,-1,-1,-1,-1,-1,-1,-1,-1,-1,-1,-1,-1,-1,-1,-1,-1,-1,-1,-1,-1,-1};
  bool lastHidDVal[19]={0,-1,-1,-1,-1,-1,-1,-1,-1,-1,0,-1,-1,1,1,1,1,1,1};
  long lastHidRVal[3];
  long lastHidEVal[8];
  long lastHidEVal4[8];

//fretboard
  // Provisional values: tune from captured contact traces on the physical instrument.
  const FretDetectionTimings fretDetectionTimings = {1, 12, 30, 12};
  FretDetector fretDetectors[nStrings];
  byte frtb_sensMode=0; //1=only senses if string is pressed 0=senses also where the string is pressed
  bool frtState[nFrets][nStrings];
  bool lastFrtState[nFrets][nStrings];
  byte strPrs[nStrings]={0,0,0,0,0,0};
  byte frtPrs[nStrings]={0,0,0,0,0,0};
  byte lastStrPrs[nStrings]={0,0,0,0,0,0};
  byte lastLastStrPrs[nStrings]={0,0,0,0,0,0};
  int strBnc[nStrings];
  bool fbrdMode=0;
  bool fbrdSeqVHld=0; //let the leds stay in seqencer mode

//kickup
  unsigned int kickDur[nStrings]={5,5,5,5,5,5};
  bool kickCue[nStrings]={0,0,0,0,0,0};
  bool kickState[nStrings];
  unsigned long kickTimer[nStrings];
  unsigned long kCueTimer; 
  unsigned int kCueInt=3;
  byte lastKickMode=0;
  byte kickSeq=0;
  bool kickOn;

//mulltiBow
  byte bowMode=2;
  //bool bowOn=0;
  byte lastBowMode=0;

// Scales
  const int nScales=10;
  const char* sclNm[nScales]={"off", "root", "pentatonic", "major", "minor", "hrm minor", "mel minor", "altered", "whole", "wholeHalf"}; //max 16!
  float scls_sclPix[nStrings][nLedFrets][3];
  float scls_midiPix[nStrings][nLedFrets][3];
  int scls_sclClr=1; // colored or white scale view
  int scls_numSclStp[nScales]= {0, 1, 5, 7, 7, 7, 7, 7, 6, 8};
  int scls_sclSel=2;
  int scls_sclStp=0;
  int rootNote=0;
  int scls_fledSrc=1;
  

  //int scls_nDispEncFnc=4; 
  
  //string setup
  const char* toneNm[12]={"C","C#","D","D#","E","F","F#","G","G#","A","A#","B"};
  
//string arpeggiator/sequencer
  const int strArp_nPttn = 6;

  struct StrArpPatternState {
    byte tmDv[nStrings];
    byte tmDvSel[nStrings];
    byte steps[nStrings];
    byte repeat[nStrings];
    byte chn[nStrings];
    byte order[nStrings];
    bool muteCh[nStrings];
    byte strPrsFnc;
    byte strEncFnc;
    int strBtnFnc;
  };

  struct StrArpPatternBank {
    StrArpPatternState pttn[strArp_nPttn];
  };

  byte strArp_actPttn = 0;
  byte strArp_nxtPttn = 0;
  int schdStrArpPttnCh = -1;
  int schdStrArpModeSel = -1;
  StrArpPatternBank strArp_patterns;

  #define strArp_tmDv strArp_patterns.pttn[strArp_actPttn].tmDv
  #define strArp_tmDvSel strArp_patterns.pttn[strArp_actPttn].tmDvSel
  #define strArp_steps strArp_patterns.pttn[strArp_actPttn].steps
  #define strArp_repeat strArp_patterns.pttn[strArp_actPttn].repeat
  #define strArp_chn strArp_patterns.pttn[strArp_actPttn].chn
  #define strArp_order strArp_patterns.pttn[strArp_actPttn].order
  #define strArp_muteCh strArp_patterns.pttn[strArp_actPttn].muteCh
  #define strArp_strPrsFnc strArp_patterns.pttn[strArp_actPttn].strPrsFnc
  #define strArp_strEncFnc strArp_patterns.pttn[strArp_actPttn].strEncFnc
  #define strArp_strBtnFnc strArp_patterns.pttn[strArp_actPttn].strBtnFnc

  byte strArp_act=0;
  float sclArpMode=7;
  float sclArpClkMode=4;
  float sclArpRpt=4;
  byte strArp_stp[nStrings][nFrets];
  long strArp_clk[nStrings];
  const int strArp_maxVisSteps = 20;
  const int strArp_maxSteps = 64;
  float strArp_gridPix[nStrings][strArp_maxVisSteps][3];
  float strArp_crsrPix[nStrings][strArp_maxVisSteps][3];
  float strArp_stpPix[nStrings][strArp_maxVisSteps][3];
  byte strArp_nStps[nStrings];
  byte strArp_seq[strArp_maxSteps];
  byte strArp_seqLen=0;
  byte strArp_serialStep=0;
  int strArp_serialDisplayStep=-1;
  byte strArp_serialNxtClkFil=0;
  byte strArp_tmDvs[12]={96,64,48,32,24,16,12,8,6,4,3,2};
  const char* strArp_tmDvNm[12]={"1","1.5","2","3","4","6","8","12","16","24","32","48"};
  byte strArp_nTmDvs=12;
  byte strArp_nxtClkFil[nStrings];

  unsigned int strArp_pressOrder[nStrings] = {0,0,0,0,0,0};
  unsigned int strArp_pressOrderNext = 1;

  const byte strArp_strPrsFnc_simple=0;
  const byte strArp_strPrsFnc_back=1;
  const byte strArp_strPrsFnc_mirror=2;
  const byte strArp_strPrsFnc_revMirror=3;
  const char* strArp_strPrsNm[]={"simple", "back", "mirror", "rev mirror"};
  const byte strArp_nStrPrsFnc=sizeof(strArp_strPrsNm)/sizeof(strArp_strPrsNm[0]);
  
  const byte strArp_strEncFnc_stps=0;
  const byte strArp_strEncFnc_tmDv=1;
  const byte strArp_strEncFnc_chn=4;
  const byte strArp_strEncFnc_repeat=2;
  const byte strArp_strEncFnc_order=3;
  const char* strArp_strEncNm[]={"steps", "tmDv", "repeat", "order", "chn"};
  const byte strArp_nStrEncFnc=sizeof(strArp_strEncNm)/sizeof(strArp_strEncNm[0]);
  
  const char* strArp_strBtnNm[]={"mute", "randomise"};
  const int strArp_strBtnFnc_mute=0;
  const int strArp_strBtnFnc_rnd=1;
  const int strArp_nStrBtnFnc=2;

//generic Sequenzer
  //globals
  float pttr_gridPix[nStrings][nLedFrets][3];
  const int genSq_maxVisSteps = 16;
  const int genSq_maxSteps = 16;
  const int genSq_nPttn = 6;
  const int genSq_nSngs = 100;
  const int genSq_pttnMOff = nLedFrets-genSq_nPttn/2;
  int genSq_hrmInst=1;
  int genSq_strEncBtnSw = 1; //choose between button function or Encoder button select


  const int genSq_nTmDvs=14; //global
  int genSq_tmDvs[genSq_nTmDvs]={384,192,96,64,48,32,24,16,12,8,6,4,3,2};
  const char* genSq_tmDvNm[genSq_nTmDvs]={"4","2","1",".75","/2","/3","/4","/6","/8","/12","/16","/24","/32","/48"};

  const char* genSq_strPrsNm[]={"pStp","rpt","vel","c10","c11","c12"};
  const int genSq_strPrsFnc_sStp=0;
  const int genSq_strPrsFnc_rpt=1;
  const int genSq_strPrsFnc_vel=2;
  const int genSq_strPrsFnc_cc1=3;
  const int genSq_strPrsFnc_cc2=4;
  const int genSq_strPrsFnc_cc3=5;
  const int genSq_nStrPrsFnc=6;
  const int genSq_SelChnCC=127; //selected channel; currently commented
  const int genSq_maxStpV[genSq_nStrPrsFnc]={127,6,50,99,99,99};
  int genSq_strPrsFnc=0;

  const int genSq_strEncFnc_tmDv=1;
  const int genSq_strEncFnc_offSt=2;
  const int genSq_strEncFnc_stps=0; //len
  const int genSq_strEncFnc_sync=3;
  const int genSq_strEncFnc_chn=4;
  const char* genSq_strEncNm[]={"len","tmDv","offSt","sync","chn"};

  const int genSq_nStrEncFnc=sizeof(genSq_strEncNm)/sizeof(genSq_strEncNm[0]);
  const int genSeq_maxEncV[genSq_nStrEncFnc]={16,genSq_nTmDvs,genSq_maxVisSteps,6,16};
  int genSq_strEncFnc=0;
  int genSq_strEncChAStps=0;

  const int genSq_nInst = 3;
  int genSq_actInst = 0;
  int genSq_actTmDv[genSq_nInst][nStrings]; //time devision actually used (changes on timed occasions)
  const int genSq_nActPttns=12;

  struct GenSeqRuntimeState {
    int actNotes[genSq_nInst][nStrings][128];
    int velState[genSq_nInst][nStrings];
    int lastNote[genSq_nInst][nStrings];
    int clk[genSq_nInst][nStrings];
    int clkraw[genSq_nInst][nStrings];
    int nxtClkFil[genSq_nInst][nStrings];
    int muteCh[genSq_nInst][nStrings];
    int nxtPttn[genSq_nInst];
    int actPttn[genSq_nInst];
    int lastActPttn[genSq_nInst];
    int edtPttn[genSq_nInst];
    bool sclQ[genSq_nInst][nStrings];
  };

  struct GenSeqPattern {
    int tmDv[genSq_nInst][genSq_nPttn][nStrings];
    bool stpOnOff[genSq_nInst][genSq_nPttn][nStrings][genSq_maxSteps];
    int stp[genSq_nInst][genSq_nPttn][nStrings][genSq_maxSteps][genSq_nStrPrsFnc];
    int chn[genSq_nInst][genSq_nPttn][nStrings][genSq_nStrEncFnc];
  };

  struct GenSeqSong {
    int actSng;
    int syncInst[genSq_nInst]; //sync pattern switching to another sequencer instance
    const char* names[genSq_nSngs];
    int actPttns[genSq_nActPttns][genSq_nInst];
    int actPttnsIdx;
  };

  GenSeqRuntimeState genSeqRuntime;
  GenSeqPattern genSeqPatterns;
  GenSeqSong genSeqSong = {
    0,
    {-1,-1,-1},
    {"Song01", "Song02", "Song03", "Song04", "Song05", "Song06", "Song07", "Song08", "Song09", "Song10", "Song11", "Song12", "Song13", "Song14", "Song15", "Song16", "Song17", "Song18", "Song19", "Song20", "Song21", "Song22", "Song23", "Song24", "Song25", "Song26", "Song27", "Song28", "Song29", "Song30", "Song31", "Song32", "Song33", "Song34", "Song35", "Song36", "Song37", "Song38", "Song39", "Song40", "Song41", "Song42", "Song43", "Song44", "Song45", "Song46", "Song47", "Song48", "Song49", "Song50", "Song51", "Song52", "Song53", "Song54", "Song55", "Song56", "Song57", "Song58", "Song59", "Song60", "Song61", "Song62", "Song63", "Song64", "Song65", "Song66", "Song67", "Song68", "Song69", "Song70", "Song71", "Song72", "Song73", "Song74", "Song75", "Song76", "Song77", "Song78", "Song79", "Song80", "Song81", "Song82", "Song83", "Song84", "Song85", "Song86", "Song87", "Song88", "Song89", "Song90", "Song91", "Song92", "Song93", "Song94", "Song95", "Song96", "Song97", "Song98", "Song99", "Song100"},
    {0},
    0
  };

  #define genSq_actNotes genSeqRuntime.actNotes
  #define genSq_velState genSeqRuntime.velState
  #define genSq_lastNote genSeqRuntime.lastNote
  #define genSq_clk genSeqRuntime.clk
  #define genSq_clkraw genSeqRuntime.clkraw
  #define genSq_nxtClkFil genSeqRuntime.nxtClkFil
  #define genSq_muteCh genSeqRuntime.muteCh
  #define genSq_nxtPttn genSeqRuntime.nxtPttn
  #define genSq_actPttn genSeqRuntime.actPttn
  #define genSq_lastActPttn genSeqRuntime.lastActPttn
  #define genSq_edtPttn genSeqRuntime.edtPttn
  #define genSq_sclQ genSeqRuntime.sclQ
  #define genSq_tmDv genSeqPatterns.tmDv
  #define genSq_stpOnOff genSeqPatterns.stpOnOff
  #define genSq_stp genSeqPatterns.stp
  #define genSq_chn genSeqPatterns.chn
  #define genSq_actSng genSeqSong.actSng
  #define genSq_syncInst genSeqSong.syncInst
  #define genSq_SongNm genSeqSong.names
  #define genSq_actPttns genSeqSong.actPttns
  #define genSq_actPttnsIdx genSeqSong.actPttnsIdx

  float genSq_gridPix[nStrings][genSq_maxVisSteps][3];
  float genSq_crsrPix[nStrings][genSq_maxVisSteps][3];
  float genSq_stpPix[nStrings][genSq_maxVisSteps][3];
  
  float genSq_pttnGridPix[nStrings][genSq_nPttn/2][3];
  float genSq_pttnPttnPix[nStrings][genSq_nPttn/2][3];

  const char* genSq_strBtnNm[]={"mute", "rnd", "sclQ"};
  const int genSq_strBtnFnc_mute=0;
  const int genSq_strBtnFnc_rnd=1;
  const int genSq_strBtnFnc_sclQ=2;
  const int genSq_nStrBtnFnc=3;
  int genSq_strBtnFnc=0;

  int genSq_stpEdtStr;
  bool genSq_stpEdtStrs[nStrings];
  int genSq_stpEdtFrt;

  //sequencer colors
  const float strArp_gridColorA[3]={0.1,0,0.6};
  const float strArp_gridColorB[3]={0.01,0,0.06};
  const float strArp_gridMuteColorA[3]={0.1,0.1,0.1};
  const float strArp_gridMuteColorB[3]={0.02,0.02,0.2};
  const float strArp_cursorColor[3]={0,1,0};
  const float strArp_stepColor[3]={0.6,0,0.1};
  const float strArp_stepMuteColor[3]={0.06,0,0.01};
  const float genSq_gridColorA[genSq_nInst][3]={{0.0,0.25,0.25},{0.375,0.0,0.25},{0.375,0.25,0.0}};
  const float genSq_gridColorB[genSq_nInst][3]={{0.0,0.05,0.05},{0.075,0.0,0.05},{0.075,0.05,0.0}};
  const float genSq_gridMuteColorA[genSq_nInst][3]={{0.0,0.025,0.025},{0.0375,0.0,0.025},{0.0375,0.025,0.0}};
  const float genSq_gridMuteColorB[genSq_nInst][3]={{0.0,0.005,0.005},{0.0075,0.0,0.005},{0.0075,0.005,0.0}};
  const float genSq_cursorColor[3]={0.25,0.25,0.25};
  const float genSq_stepNoChannelColor[3]={0.5,0.5,0.5};
  const float genSq_stepMuteColor[3]={0.2,0.2,0.2};

  float genSq_edtPttnColor[3]={0.0,0.0,0.1};

  // GenSeq per-instance runtime state lives in genSeqRuntime.
  // GenSeq per-pattern step/channel data lives in genSeqPatterns.
  // Compatibility macros above keep existing index order unchanged.
  //int genSq_sndCh[genSq_nInst][nStrings]={{1,1,1,1,1,1},{2,2,2,2,2,2},{3,3,3,3,3,3}};

// String Sequencer (from genSeq)
  bool strSeq_act=1;
  bool strArp_modeSel=0;
  byte strArp_modeVal=0;

//sequence settings
  unsigned int bpm=90;




// instance modes
  const int strSetup_opMode=0;
  const int strArp_opMode=1;
  const int genSq_opMode=2;
  const int scls_opMode=strArp_opMode;
  
  const byte maxOpMds=12;
  byte opMode=2;
  int dispEncMode=0;
  int strEncMode;
  int lastStrEnc;
  const byte nDispEncFnc[maxOpMds]={3,6,3,3,3,3,3,3,3,3,3,3}; //number of functions selectable with the disp encoder in each opMode
  //const byte nStrEncFnc[maxOpMds]={2,2,2,2,2,2,2,2,2,2,2,2}; //number of functions selectable with the string encoders in each opMode
  int dispEncFnc[maxOpMds]={0,4,0,0,0,0,0,0,0,0,0,0}; //{0,4,2,2,2,2,0,0,0,0,0,0};
  byte strEncFnc[maxOpMds];
  
//global parameters
  bool shift=0;
  bool extClk=0;
  float vol;
  bool mtOut = 0;
  

// Clock
  long mClock; //master clock
  long lastMClock; //master clock
  long pulse;
  long lastPulse;
  long bar;
  long lastBar;
  long syncPnt[genSq_nInst];
  long lastSyncPnt[genSq_nInst];
  int syncInt[genSq_nInst];
  bool schdSync[genSq_nInst];
  bool schdSyncPnt[genSq_nInst];
  int schdPttnCh[genSq_nInst];
  bool tgl_ply=1;
  unsigned int intClockInt; //inerval between clock ticks
  long intClockTimer; //to measure interval between clock ticks
  bool clckOn=0;

//other
long scanPttnTimer;

void setup() {
  Serial.begin(115200); //debug
  Serial1.begin(250000); //audio Server
  Serial7.begin(115200); // hid
  //Serial5.begin(250000); // LED
  MIDI.begin(MIDI_CHANNEL_OMNI); 
  MIDI.turnThruOff();

  //init sdCard
  Serial.print("Initializing SD card...");

  if (!SD.begin(chipSelect)) {
    Serial.println("initialization failed!");
    return;
  }
  Serial.println("initialization done.");
  debugSetup();

  // init LEDs  
  LEDS.addLeds<WS2812SERIAL,LED_PIN,RGB>(frtPix,NUMPIXELS);
  LEDS.setBrightness(byte(fled_bright*255));

  //kickup
  for(int s=0;s<nStrings;s++){ 
    pinMode(kickupPins[s],OUTPUT);
    digitalWrite(kickupPins[s], LOW);
  }

  //fretboard
  for (int s=0; s < nStrings; s++) {
    pinMode(strPins[s], INPUT_PULLUP);
  }
  for (int f=0; f < nFrets; f++) {
    pinMode(frtPins[f], OUTPUT);
    digitalWrite(frtPins[f], LOW);
  }


  //rstAllSngs(); //uncomment if the song structure has changed. Resets all songs
  loadSong(0);
  loadStrSetupGlobals();
  chngBpm(bpm);
  strArp_drwGrid();
  mkColors();
  setMidiHandles();
  //clck_strt();
}

void loop() {
  debugPoll();
  usbMIDI.read();    
  updIntClock();
  //updDisplay();
  if (fbrdMode == 1)readFretboard(0);
  if (fbrdMode == 0){
    if (frtb_sensMode==1)readFretboard(1);
    if (frtb_sensMode==0)readFretboard(0);    
  }
  cueKicks();
  updLedFrets();
  //scanPttns();
}

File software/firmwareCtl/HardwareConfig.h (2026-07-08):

#pragma once

#include <Arduino.h>

#define LED_PIN     14   //led pin

const byte strSnsPins[nStrings]={2,3,4,5,6,7};

const byte led_pixPos[nStrings][nLedFrets]={
{144,143,132,131,120,119,108,107,96,95,84,83,72,71,60,59,48,47,36,35,24,23,12,11,0}, //for 25 frets
{145,142,133,130,121,118,109,106,97,94,85,82,73,70,61,58,49,46,37,34,25,22,13,10,1}, //for 25 frets
{146,141,134,129,122,117,110,105,98,93,86,81,74,69,62,57,50,45,38,33,26,21,14,9,2}, //for 25 frets
{147,140,135,128,123,116,111,104,99,92,87,80,75,68,63,56,51,44,39,32,27,20,15,8,3}, //for 25 frets
{148,139,136,127,124,115,112,103,100,91,88,79,76,67,64,55,52,43,40,31,28,19,16,7,4}, //for 25 frets
{149,138,137,126,125,114,113,102,101,90,89,78,77,66,65,54,53,42,41,30,29,18,17,6,5}}; //for 25 frets

byte frtPins[] = {13,33,2,3,4,5,6,7,8,9,10,11,12,24,25,26,27,30,31,32,17,16}; //{14,13,2,3,4,5,6,7,8,9,10,11,12,24,25,26,27,28,29,30,15,16};
byte strPins[] = {18,19,20,21,22,23};

const byte kickupPins[6]={41,40,39,38,37,36};//34

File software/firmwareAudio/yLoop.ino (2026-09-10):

#include "ProtocolAudio.h"

namespace {
constexpr unsigned long AUDIO_SERIAL_PACKET_TIMEOUT_MS = 10;
constexpr byte AUDIO_SERIAL_MAX_PAYLOAD = 3;

// CTL -> Audio payload lengths. These preserve the existing byte protocol:
// command byte AUDIO_CMD_* followed by exactly this many payload bytes.
byte audioCommandPayloadLength(byte command) {
  switch (command) {
    case AUDIO_CMD_TRIG_ENV: return 2;
    case AUDIO_CMD_STR_FRET: return 3;
    case AUDIO_CMD_OP_MODE: return 1;
    case AUDIO_CMD_DISP_MODE: return 1;
    case AUDIO_CMD_KICK_MODE: return 1;
    case AUDIO_CMD_BOW_MODE: return 1;
    case AUDIO_CMD_BOW_ON: return 1;
    case AUDIO_CMD_ENV_1: return 2;
    case AUDIO_CMD_ENV_2: return 2;
    case AUDIO_CMD_FILTER: return 2;
    case AUDIO_CMD_MANUAL_ENV: return 2;
    case AUDIO_CMD_VOLUME: return 1;
    case AUDIO_CMD_STR_GAIN: return 2;
    case AUDIO_CMD_FX: return 2;
    case AUDIO_CMD_LFO_1: return 2;
    case AUDIO_CMD_BPM: return 1;
    case AUDIO_CMD_MIDI_CC: return 2;
    default: return 0;
  }
}

void resetAudioSerialPacket(byte &command, byte &payloadIndex, byte &payloadLength) {
  command = 0;
  payloadIndex = 0;
  payloadLength = 0;
}

void handleAudioSerialPacket(byte command, const byte payload[]) {
  int incoming = audioIncoming(command);

  if (incoming == audioIncoming(AUDIO_CMD_TRIG_ENV)) {
    trigEnv(payload[0], payload[1] / 199.0);
  }

  if (incoming == audioIncoming(AUDIO_CMD_STR_FRET)) {
    strFret(payload[0], payload[1], payload[2]);
    strState[payload[0]] = payload[2];
  }

  if (incoming == audioIncoming(AUDIO_CMD_ENV_1)) {
    float sclVal = scale(payload[1] / 199.0, 1, sclEnvA[payload[0]]);
    chEnvA(payload[0], sclVal);
    envPA[payload[0]] = sclVal;
  }

  if (incoming == audioIncoming(AUDIO_CMD_ENV_2)) {
    float sclVal = scale(payload[1] / 199.0, 1, sclEnvF[payload[0]]);
    chEnvF(payload[0], sclVal);
    envPF[payload[0]] = sclVal;
  }

  if (incoming == audioIncoming(AUDIO_CMD_MANUAL_ENV)) {
    chManualEnvDecay(payload[0], payload[1]);
  }

  if (incoming == audioIncoming(AUDIO_CMD_FILTER)) {
    valFilter[payload[0]] = scale(payload[1] / 199.0, 1, sclFilter[payload[0]]);
    chFilter(payload[0], valFilter[payload[0]]);
  }

  if (incoming == audioIncoming(AUDIO_CMD_STR_GAIN)) {
    float val = payload[1] / 100.0;
    chngStrOutGain(payload[0], val);
    DBG_AUDIO_PRINT(payload[0]);
    DBG_AUDIO_PRINT(": ");
    DBG_AUDIO_PRINTLN(val);
  }

  if (incoming == audioIncoming(AUDIO_CMD_FX)) {
    valFX[payload[0]] = scale(payload[1] / 199.0, 1, sclFX[payload[0]]);
    chFX(payload[0], valFX[payload[0]]);
  }

  if (incoming == audioIncoming(AUDIO_CMD_LFO_1)) {
    valLfo1[payload[0]] = scale(payload[1] / 199.0, 1, sclLfo1[payload[0]]);
    for (int i = 0; i < nStrings; i++) {
      chLfo1(payload[0], valLfo1[payload[0]], i);
    }
  }

  if (incoming == audioIncoming(AUDIO_CMD_MIDI_CC)) {
    if (payload[0] == 2) sndMidiCC(3, payload[1] / 2);
  }

  if (payload[0] <= 199) {
    if (incoming == audioIncoming(AUDIO_CMD_OP_MODE)) chOpMode(payload[0]);
    if (incoming == audioIncoming(AUDIO_CMD_DISP_MODE)) chDispMode(payload[0]);
    if (incoming == audioIncoming(AUDIO_CMD_KICK_MODE)) chKickMode(payload[0]);
    if (incoming == audioIncoming(AUDIO_CMD_BOW_MODE)) chBowMode(payload[0]);
    if (incoming == audioIncoming(AUDIO_CMD_BOW_ON)) bowOn = payload[0];

    if (incoming == audioIncoming(AUDIO_CMD_VOLUME)) {
      float val = payload[0] / 199.0;
      val = val * val * 2;
      ampOut.gain(val + 0.0001);
    }

    if (incoming == audioIncoming(AUDIO_CMD_BPM)) {
      bpm = payload[0];
    }
  }
}
}

void serialEvent1(){
  static byte command = 0;
  static byte payload[AUDIO_SERIAL_MAX_PAYLOAD];
  static byte payloadIndex = 0;
  static byte payloadLength = 0;
  static unsigned long packetStartedAt = 0;

  if (payloadLength > 0 && millis() - packetStartedAt > AUDIO_SERIAL_PACKET_TIMEOUT_MS) {
    resetAudioSerialPacket(command, payloadIndex, payloadLength);
  }

  while (Serial1.available() > 0) {
    byte sbyte = Serial1.read();

    if (sbyte >= AUDIO_CMD_BASE && sbyte <= AUDIO_CMD_MAX) {
      command = sbyte;
      payloadIndex = 0;
      payloadLength = audioCommandPayloadLength(command);
      packetStartedAt = millis();
      if (payloadLength == 0 || payloadLength > AUDIO_SERIAL_MAX_PAYLOAD) {
        resetAudioSerialPacket(command, payloadIndex, payloadLength);
      }
      continue;
    }

    if (payloadLength == 0) {
      continue;
    }

    payload[payloadIndex++] = sbyte;
    if (payloadIndex >= payloadLength) {
      handleAudioSerialPacket(command, payload);
      resetAudioSerialPacket(command, payloadIndex, payloadLength);
    }
  }
}

void loop(){
  //usbMIDI.read();

//---Do control functions-----
if (millis()-ctlTimer > ctlInt){ 
  for(int i=0;i<nStrings;i++){
    if(strState[i]!=lastStrState[i]){
      //strFret(i,strState[i]);
      lastStrState[i]=strState[i];
    }
  }
  ctlTimer=millis();
}

if (millis()-nFrqTimer > nFrqInt){ 
static int i=0;
static int cntSmp;
static int nSmp=5;
  for(int s=0;s<nStrings;s++){
    nFreq[s].resume();
    if (nFreq[s].available()) {
        float note = nFreq[s].read();
        float prob = nFreq[s].probability();
        
        float mNote = base_pitch + (12.0 * log(note / base_frequency) / log(2));
        if(prob>0.96){
          strP[s]=mNote;
          //chLfo1(0, mNote,s);
          //chCoilDel(s,note);
//          Serial.printf("freq1: %3.2f | Probability: %.2f\n", note, prob);    
//          Serial.print(i+1);
//          Serial.print(" ");
//          Serial.printf("mNote: %3.2f | Probability: %.2f\n", mNote, prob);
        }               
    
    }
    //nFreq[s].stop(); 
  }
//    cntSmp++;
//    if (cntSmp>=nSmp){
//      nFreq[i].stop();
//      nFreq[(i+1)%nStrings].resume();
//      cntSmp=0;
//      i++;
//      i=i%nStrings;
//    }

  sndStrP();
  
  nFrqTimer=millis();
}

if (millis()-peakTimer > peakInt){ 
  for(int s=0; s<nStrings; s++){
    if (strPeak[s].available()) {
      float vel = strPeak[s].read() * 5.0;
      //Serial.printf("freq1: %3.2f | Probability: %.2f\n", note, prob);
      if(vel>1.0)vel=1.0;  
      strA[s]=vel;  
//      Serial.print(s+1);
//      Serial.print(" ");
//      Serial.print("Vel: "); 
//      Serial.println(vel);          
    } 
  }
  sndStrA();
  peakTimer=millis();
}

if(bowOn!=lastBowOn){
  // for (int i=0; i<nStrings; i++) {
  //   if(bowOn==0)coilAmp[i].gain(0.000);
  //   if(bowOn==1 && strState[i]>0)coilAmp[i].gain(100);
  // }
  for (int str=0; str<nStrings; str++) {
    if(bowOn==1 && strState[str]>0)coilOsc[str].amplitude(1);
    if(bowOn==0)coilOsc[str].amplitude(0);
  }

  DBG_AUDIO_PRINT("bowOn: ");
  DBG_AUDIO_PRINTLN(bowOn);
  lastBowOn=bowOn;
}
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

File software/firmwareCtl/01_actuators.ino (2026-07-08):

void kickup(byte s) {
  if (s >= nStrings) return;
  digitalWrite(kickupPins[s], HIGH);
  kickState[s] = true;
  kickTimer[s] = millis();
}

void kickOff(){
  for(int s=0;s<nStrings;s++){
    if (millis()-kickTimer[s] >= kickDur[s] && kickState[s]==1){ 
      digitalWrite(kickupPins[s],0);
      kickState[s]=0;
      }
  }
}

//fire the multiple kick that occure at once in a timed sequence to prevent voltage drop
void cueKicks(){
  kickOff();
  if (millis()-kCueTimer > kCueInt){ 
    for(int s=0;s<nStrings;s++){
      if(kickCue[s]==1){
        kickup(s);
        kickCue[s]=0;
        s=nStrings;
      }
    }
    kCueTimer=millis();
  }
}

void kick(byte str){
  if(kickOn==1)kickCue[str]=1;
}

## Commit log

2019-05-20 added breakout-box-case, some firmwarechanges
    [AdapterBox-lid.stl, AdapterBox.scad, AdapterBox.stl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]
2019-05-20 added docs folder with initial bom
    [bom.ods]
2020-10-20 New neck-design with parametric led-pcb
    [AdapterBox-lid.stl, AdapterBox.scad, AdapterBox.stl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]
2020-10-20 added other electronic-files
    [breakout.kicad_pcb, encoderBank.kicad_pcb, fader.kicad_pcb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]
2021-02-15 added polytuner, made notefreq work with different buffer size
    [bridge-A.stl, bridge-B.stl, bridge-C.stl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]
2022-02-02 new preamp, switched to teensy 4.0
    [8soic-adapter.kicad_pcb, 8soic-adapter.sch, AdapterBox.scad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]
2022-05-02 new sequencer
    [stringContact.scad, stringContact.stl]
2022-05-03 pattern switch bug workaround
    workaround by scanning through all patterns at startup
2022-05-08 added adapter for power over usb-c
    [usbc_power.scad, usbc_power.stl]
2022-06-13 genSq update and external midi instrument function
    [usbc_power_data.scad, usbc_power_data.stl]
2023-12-02 to much to tell
    [bridge(piezo(ghost)).3mf, bridge(piezo(ghost)).scad, bridge(piezo(ghost)).stl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]
2025-10-17 different changes
    [littleButton.scad, littleButton.stl]
2026-07-05 Fix Arduino sketch-local protocol headers
    [13_serialEvents.ino, 2audio.ino, 2ctl.ino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]
2026-07-05 Centralize firmware hardware pin arrays
2026-07-05 docs: add board protocol reference tables
2026-07-06 Fix firmwareCtl sequencer compile errors
    [04_hid.ino, 10_op_genSq_Disp.ino, firmwareCtl.ino]
2026-07-06 Fix song tab Arduino prototypes
    [14_song.ino]
2026-07-06 Add firmwareCtl debug enable switch
2026-07-07 Fix display clock scheduling
    [03_display.ino, 15_debug.ino]
2026-07-08 Enable arpeggiator mode from rotary switch
2026-07-13 Prevent display scheduler lockup during clock
    [03_display.ino]
2026-07-15 Fix stuck strArp serial MIDI notes
    [06_midi.ino, 09_op02_StrArp.ino]
2026-07-15 Fix strArp serial cursor alignment
    [09_op02_StrArp.ino]
2026-07-15 Reset strArp serial cursor on sync
    [09_op02_StrArp.ino, firmwareCtl.ino]
2026-07-15 Centralize strArp serial cursor reset
    [09_op02_StrArp.ino]
2026-07-15 Fix StrArp serial step timing
    [09_op02_StrArp.ino]
2026-07-15 Refactor string encoder mappings
2026-07-17 Schedule string sequencer mode switches
2026-07-24 Increase song slots and send program changes

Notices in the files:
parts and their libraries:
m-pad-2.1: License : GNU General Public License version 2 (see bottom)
